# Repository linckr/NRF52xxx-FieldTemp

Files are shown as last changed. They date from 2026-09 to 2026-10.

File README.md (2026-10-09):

# PandaTemperature：固件、Android 与硬件

nRF52810 + W25Q64 温湿度/气压记录仪与配套 Android 客户端，统一在此 Git 项目维护。

- 仓库根 src/、boards/、overlay 与 sysbuild 配置：Firmware。
- android/：Android Gradle 根目录，含源码、测试和凭据示例。
- [CODEX_START_HERE.md](CODEX_START_HERE.md)：统一接手入口。
- [HANDOFF.md](HANDOFF.md)：验证边界和 P0–P4 任务。
- [PROTOCOL.md](PROTOCOL.md)、[OTA.md](OTA.md)、[HARDWARE.md](HARDWARE.md)：两端协议、OTA、引脚/分区事实。

保持现有固件布局，不为目录合并修改 MCUboot、UUID、OTA 命令、签名算法或 Flash 地址。签名私钥、Android keystore、OTA 凭据、设备数据库和构建产物不入库。历史设计文档与当前实现冲突时，以代码为准。

Android 独立仓库保留用于向 yodfz/PandaThemperature-Android 提交上游 PR；对应提交见 android/README.md。

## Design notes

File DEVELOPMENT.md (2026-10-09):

# DEVELOPMENT.md — 开发环境与构建

> 版本号全部从**当前实际安装/配置**读取（NCS 版本文件、`libs.versions.toml`、
> `gradle-wrapper.properties`、`<sysbuild>/*/zephyr/.config` 等），不是凭记忆填写。

---

## 第一部分：Firmware

## 1. 环境清单

| 项目 | 值 |
|---|---|
| 操作系统 | Windows |
| nRF Connect SDK (NCS) | **3.2.1**，安装根 `C:\ncs\v3.2.1` |
| Zephyr | **4.2.99**（`C:\ncs\v3.2.1\zephyr\VERSION`） |
| Zephyr SDK (toolchain) | **0.17.0**（`C:\ncs\toolchains\66cdf9b75e\opt\zephyr-sdk`） |
| 编译器 | `arm-zephyr-eabi-gcc` **GNU 12.2.0** |
| west | **1.4.0** |
| CMake | **3.21.0** |
| 工具链 Python | **3.12.4** —— `C:\ncs\toolchains\66cdf9b75e\opt\bin\python.exe` |
| board target | **`nrf52dk/nrf52810`** |
| 调试器 | CMSIS-DAP（枚举名 `jixin.pro CMSIS-DAP_LU` / 唯一 ID `LU_2022_8888`），pyOCD |

### 与构建直接相关的文件

| 文件 | 作用 |
|---|---|
| `prj.conf` | App 的 Kconfig（**每个符号只能出现一次**，重复赋值会让文档与实际不一致） |
| `app.overlay` | **板级引脚与 W25Q64/ADC 定义的实际生效处**（见 `HARDWARE.md` §2） |
| `boards/` | 当前没有生效的 board-specific overlay；唯一生效入口是 `app.overlay` |
| `sysbuild.conf` | sysbuild 级配置：MCUboot / overwrite-only / 外置次级槽 / ECDSA-P256 |
| `sysbuild/mcuboot.conf` | MCUboot 自身的 Kconfig（SPI NOR、布局页 4096、RC 32k、关日志） |
| `sysbuild/mcuboot.overlay` | MCUboot 的 devicetree（**与 App 独立，改引脚要同步改**） |
| `pm_static.yml` | Partition Manager 静态布局（**唯一编辑入口**） |
| `VERSION` | **镜像版本号唯一来源**（当前 `1.0.9` + tweak `0`） |
| `tools/build_sysbuild.py` | 构建包装（引号安全 + 签名私钥注入），见 §2 |

### 关键 Kconfig（摘自实际构建）

| 配置 | 值 | 说明 |
|---|---|---|
| `CONFIG_MAIN_STACK_SIZE` | 1024 | 全工程**唯一**赋值点 |
| `CONFIG_SYSTEM_WORKQUEUE_STACK_SIZE` | 1280 | OTA 异步化需要 |
| `CONFIG_BT_RX_STACK_SIZE` | 1024 | 勿降到 768 |
| `CONFIG_MPSL_WORK_STACK_SIZE` | 640 | 余量最小的栈（240 B） |
| `CONFIG_ISR_STACK_SIZE` | 1024 | |
| `CONFIG_BT_L2CAP_TX_MTU` | 128 | 协商失败自动回退，非升级前提 |
| `CONFIG_BT_BUF_ACL_RX_SIZE` / `TX_SIZE` | 132 / 132 | = MTU + 4 |
| `CONFIG_BT_MAX_CONN` | 1 | 同时只允许一个连接 |
| `CONFIG_SPI_NOR_FLASH_LAYOUT_PAGE_SIZE` | **4096** | 必须等于 W25Q64 真实扇区 |
| `CONFIG_IMG_BLOCK_BUF_SIZE` | 256 | = W25Q64 页大小 |
| `CONFIG_STREAM_FLASH` / `CONFIG_IMG_MANAGER` | y / y | ⚠️ `IMG_MANAGER` 是 **depends on** `STREAM_FLASH`，不显式开会被静默丢弃 |
| `CONFIG_IMG_ENABLE_IMAGE_CHECK` | y | App 侧整镜像 SHA-256 |
| `CONFIG_REBOOT` | y | `sys_reboot()` 需要 |
| `CONFIG_ADC` | y | 电池电压（VDD 通道） |
| `CONFIG_LOG` / `CONFIG_PRINTK` / `CONFIG_CONSOLE` | **n / n / n** | 发布态 |
| `CONFIG_NCS_BOOT_BANNER` / `CONFIG_EARLY_CONSOLE` | **n / n** | 必须一起关，否则它们 `select PRINTK`（白占 17,492 B ROM） |
| `CONFIG_USE_SEGGER_RTT` / `CONFIG_RTT_CONSOLE` | n / n | 发布态 |

> **调试时怎么开日志**：把 `prj.conf` 末尾"Release 配置"段整体注释掉，
> 改用 RTT（`CONFIG_CONSOLE=y` + `CONFIG_USE_SEGGER_RTT=y` + `CONFIG_RTT_CONSOLE=y` +
> `CONFIG_NCS_BOOT_BANNER=n` + `CONFIG_PRINTK=y`）。写法在 `prj.conf` 开头有完整说明。
> **不要**只写 `CONFIG_PRINTK=y` 而留着 `NCS_BOOT_BANNER=y`。

### 签名配置

| 项目 | 值 |
|---|---|
| 算法 | `SB_CONFIG_BOOT_SIGNATURE_TYPE_ECDSA_P256=y` |
| 私钥传入方式 | **`MCU_BOOT_SIGNING_KEY` 环境变量** 或 **`--signing-key <path>` 参数** |
| 私钥是否入库 | **否**（`.gitignore` 只按目录/文件名精确忽略，不影响将来入库公钥） |
| 默认私钥路径 | **没有**（刻意不提供） |

---

## 2. 构建：统一走 `tools/build_sysbuild.py`

**不要**直接 `west build`：`SB_CONFIG_BOOT_SIGNATURE_KEY_FILE` 是 Kconfig 字符串，
值必须自带引号，而 PowerShell 会剥掉内层双引号，导致
`malformed string literal in assignment to BOOT_SIGNATURE_KEY_FILE` 构建中止。
该脚本自己拼 `sys.argv`、直接调用 `west.app.main()`，不让 shell 参与引号处理。

### 2.0 先把私钥路径设好（PowerShell）

```powershell
$env:MCU_BOOT_SIGNING_KEY = "<仓库外的ECDSA-P256私钥路径>"
```

> 私钥是**凭据**，**不要**复制进仓库，也不要把路径写死进脚本。
> 如需用另一把密钥，加 `--signing-key` 参数覆盖（优先级高于环境变量）。

### 2.1 普通构建（干净重建，最常用）

```powershell
cd C:\Users\linckr\NRF52xxx-FieldTemp
C:\ncs\toolchains\66cdf9b75e\opt\bin\python.exe tools\build_sysbuild.py build-v9
```

> 脚本内部已经固定 `-p always`（pristine）+ `-b nrf52dk/nrf52810` + `--sysbuild`，
> 因此**这条命令就是 pristine 构建**，无需再单独执行 pristine。

### 2.2 显式 pristine / clean

```powershell
# pristine（脚本默认行为，等价写法）
C:\ncs\toolchains\66cdf9b75e\opt\bin\python.exe tools\build_sysbuild.py build-v9

# 彻底删除构建目录（clean）
Remove-Item -Recurse -Force .\build-v9
```

### 2.3 MCUboot sysbuild

MCUboot **总是**跟着 App 一起被 sysbuild 构建，产物在
`<build_dir>\mcuboot\zephyr\`。不需要单独构建 MCUboot。
只有在你修改 `sysbuild/mcuboot.conf` 或 `sysbuild/mcuboot.overlay` 后，
重新执行 §2.1 即可。

单独查看 MCUboot 产物：

```powershell
Get-ChildItem C:\Users\linckr\NRF52xxx-FieldTemp\build-v9\mcuboot\zephyr\zephyr.*
```

### 2.4 signed firmware 构建

**签名的产物是同一个命令自动产出的**，无需手工 `imgtool sign`：

```powershell
# 构建完成后，签名镜像已经在这里
Get-Item C:\Users\linckr\NRF52xxx-FieldTemp\build-v9\NRF52xxx-FieldTemp\zephyr\zephyr.signed.bin
```

如需**独立校验**签名（不修改任何产物）：

```powershell
$env:PYTHONPATH = "C:/ncs/v3.2.1/bootloader/mcuboot/scripts"
C:\ncs\toolchains\66cdf9b75e\opt\bin\python.exe -m imgtool.main verify `
  --key $env:MCU_BOOT_SIGNING_KEY `
  build-v9\NRF52xxx-FieldTemp\zephyr\zephyr.signed.bin
# 当前源码构建期望：Image was correctly validated / Image version: 1.0.9+0
```

### 2.5 查看构建产物

```powershell
$B = "C:\Users\linckr\NRF52xxx-FieldTemp\build-v9"
Get-ChildItem $B\NRF52xxx-FieldTemp\zephyr\zephyr.bin, `
              $B\NRF52xxx-FieldTemp\zephyr\zephyr.signed.bin, `
              $B\NRF52xxx-FieldTemp\zephyr\zephyr.elf, `
              $B\mcuboot\zephyr\zephyr.hex, `
              $B\merged.hex, `
              $B\dfu_application.zip |
  Select-Object Name, Length, LastWriteTime
```

### 2.6 查看 memory summary

```powershell
# 方式一：生成 Zephyr 的 ram/rom 报告（在构建目录里跑 ninja）
cd C:\Users\linckr\NRF52xxx-FieldTemp\build-v9\NRF52xxx-FieldTemp
C:\ncs\toolchains\66cdf9b75e\opt\bin\ninja.exe ram_report
C:\ncs\toolchains\66cdf9b75e\opt\bin\ninja.exe rom_report

# 方式二（推荐）：项目的体积门禁，一次给出 A–J 共 14 项判定
cd C:\Users\linckr\NRF52xxx-FieldTemp
C:\ncs\toolchains\66cdf9b75e\opt\bin\python.exe tools\size_summary.py build-v9

# 版本/发布门禁
C:\ncs\toolchains\66cdf9b75e\opt\bin\python.exe tools\release_gate.py build-v9
```

> `size_summary.py` 也可直接给 sysbuild 根目录，会自动下钻到应用镜像目录。
> 加 `--json` 便于 CI 消费。

### 2.7 构建偶发失败

`ar.exe Permission denied` 之类的中断，用增量续跑即可，不必删目录重来：

```powershell
C:\ncs\toolchains\66cdf9b75e\opt\bin\cmake.exe --build C:\Users\linckr\NRF52xxx-FieldTemp\build-v9
```

---

## 3. 引导加载相关：`VERSION` 与发布门禁

- **改行为必须抬版本**：只改仓库根 `VERSION`（`PATCHLEVEL`）。
  Zephyr 会自动生成 `app_version.h`，并让
  `CONFIG_MCUBOOT_IMGTOOL_SIGN_VERSION` 取 `APP_VERSION_TWEAK_STRING`。
- `VERSION` 缺失会**静默**退回 `0.0.0+0` —— `tools/release_gate.py` 的 R1 项专门拦这个。
- 手工 `imgtool --version x.y.z` 产出的 `zephyr.signed.vN.bin` **不是发布对象**（R4 项会拦）。

```powershell
# 发布确认后推进基线（仅在你确实要把它当作"上一生产版本"时执行）
C:\ncs\toolchains\66cdf9b75e\opt\bin\python.exe tools\release_gate.py build-v9 --promote
```

---

## 4. 烧录与调试（DAPLink / CMSIS-DAP + pyOCD）

pyOCD 装在**项目专用 venv**里（与 bleak 同一个解释器，专供 BLE + SWD 联调脚本）：

```powershell
$PYOCD = "C:\Users\linckr\.workbuddy\binaries\python\envs\default\Scripts\pyocd.exe"
```

| 包 | 版本 |
|---|---|
| pyocd | 0.45.1 |
| cmsis-pack-manager | 0.6.0 |
| bleak | 3.0.2 |

### 4.1 连接 / 确认探针

```powershell
& $PYOCD list
# 期望看到：0  jixin.pro CMSIS-DAP_LU  LU_2022_8888  n/a
```

### 4.2 烧录（**首次/恢复用 `merged.hex`**）

```powershell
$HEX = "C:\Users\linckr\NRF52xxx-FieldTemp\build-v9\merged.hex"
& $PYOCD flash -t nrf52810_xxaa --frequency 500k $HEX
```

`--frequency 500k` 是为了链路稳定（长排线/劣质杜邦线时尤其必要）。

### 4.3 复位

```powershell
& $PYOCD reset -t nrf52810_xxaa
```

### 4.4 调试（GDB server）

```powershell
& $PYOCD gdbserver -t nrf52810_xxaa --frequency 500k --port 3333
# 另一个终端用 arm-zephyr-eabi-gdb 连 localhost:3333
```

### 4.5 ⚠️ pyOCD 的两个致命坑

1. **连接即 halt 目标核。** 读 RAM 得到的是冻结快照，会假造出"采样停摆"。
   读运行态前先查 `DHCSR(0xE000EDF0)` 的 `S_HALT`(bit17)，用完 `t.resume()` 恢复。
2. **`tools/w25q64_host_dfu.py` 的 `read` / `info` 会 reset-and-halt**，
   用完**必须手动 resume**，否则设备不广播、会被误判为"固件坏了"。

另外：**主机侧 poke SPIM0 直读外置 Flash 是侵入式操作**（会覆盖 App 的 SPI 驱动寄存器）。
必须全程保持 halt（`with probe.held():`），只作最后一步、只读一次、读完立即复位。
**不要**进常规回归。

---

## 5. 四个产物的区别（**最容易搞错的地方**）

| 文件 | 内容 | 用在哪 |
|---|---|---|
| `zephyr.bin` | **裸应用镜像**（无 MCUboot 头、无签名） | 只用于比对/分析；**不能**用于 OTA |
| `zephyr.signed.bin` | 应用镜像 + MCUboot 头(512 B) + TLV(SHA-256/KEYHASH/**ECDSA256 签名**) | ✅ **现场 OTA（BLE）就传它** |
| `merged.hex` | **MCUboot + 主槽**（带绝对地址的 Intel HEX） | ✅ **首次 SWD 烧录 / 救砖** |
| `dfu_application.zip` | 供 MCUboot **serial recovery** 的容器（含 manifest + 镜像） | ❌ 当前未启用 serial recovery，用不上 |

参考大小（`build-pub`，2026-09-14；签名 TLV 长度可能逐次变化，应以当前构建产物为准）：

| 产物 | 大小 |
|---|---|
| `zephyr.bin` | 149,528 B |
| `zephyr.signed.bin` | 150,191 B |
| `merged.hex` | 512,122 B |
| `dfu_application.zip` | 150,996 B |
| `mcuboot/zephyr/zephyr.bin` | 31,876 B |

---

## 6. 常用工具（`tools/`）

| 工具 | 用途 |
|---|---|
| `build_sysbuild.py` | 引号安全的 sysbuild 构建包装（**唯一推荐构建入口**） |
| `size_summary.py` | 体积/布局门禁 A–J（真 CI 门禁，FAIL 返回非零） |
| `release_gate.py` | 发布门禁 R1–R5（版本单一源、无手工签名残留） |
| `stack_hwm.py` | 0xAA 扫描线程栈高水位（**必须传 `--config`**，否则 MPU 守卫区会误报 100%） |
| `ram_breakdown.py` | RAM 构成分解（注意：`nm` 不加 `-t` 时地址与尺寸**都是十六进制**） |
| `size_diff.py` | 两个构建的 ROM/RAM 差异对比 |
| `ota_host_client.py` | PC 侧 BLE OTA 客户端（需要装了 bleak 的解释器） |
| `ota_mkbadsig.py` | 造"坏签名"镜像（只翻 ECDSA 签名 TLV 1 字节） |
| `ota_powerloss_reset.py` | SWD 复位回归，不等同于真实断电 |
| `w25q64_host_dfu.py` | 主机侧外置 Flash 读写（**有运行扰动**，见 §4.5） |
| `free_ble.py` | **PC 侧 BLE 测试前必用**：确保手机让出 BLE（`am force-stop` 不够） |
| `verify_v6_timing.py` | 记录周期与事件限流验证 |
| `verify_v7_wallclock.py` | 墙钟整分对齐三项测试 |
| `dfu_e2e_verify.py` | 写次级槽 + trailer → 复位 → 逐字节比对主槽 |

需要 **bleak** 的脚本（`ota_host_client.py` / `verify_v7_wallclock.py` / `free_ble.py`）
必须用同时装了 bleak 与 pyocd 的解释器：

```powershell
C:\Users\linckr\.workbuddy\binaries\python\envs\default\Scripts\python.exe tools\ota_host_client.py --file <zephyr.signed.bin>
```

---

## 第二部分：Android App

## 7. 环境清单（全部读自项目实际配置）

| 项目 | 值 | 来源 |
|---|---|---|
| Android Studio | `AI-261.26222.65.2613.16025427`（build `261.26222.65.2613.16025427`） | `C:\Program Files\Android\Android Studio\product-info.json` |
| Gradle | **8.13** | `gradle/wrapper/gradle-wrapper.properties` |
| AGP | **8.13.2** | `gradle/libs.versions.toml` |
| Kotlin | **2.0.21** | 同上 |
| KSP | **2.0.21-1.0.27** | 同上 |
| Compose BOM | 2024.09.00 | 同上 |
| Room | 2.6.1 | 同上 |
| **JDK** | **17** | ⚠️ 见下方警告 |
| `compileSdk` | **36** | `app/build.gradle.kts` |
| `targetSdk` | **36** | 同上 |
| `minSdk` | **26** | 同上 |
| `applicationId` / `namespace` | `com.example.pandatemperature` | 同上 |
| `versionCode` / `versionName` | **4 / "1.1.2"** | 同上（**与固件版本无关**） |
| Java / Kotlin target | 11 | 同上 |
| 构建变体 | `debug` / `release` | 无 flavor |

### ⚠️ JDK 必须用 17

Android Studio 自带的 `jbr` 现在是 **JDK 25.0.2**，Gradle 8.13 **不支持**，
症状是构建失败且 `What went wrong:` 下面**只有一行版本号**（如 `25.0.2`），没有任何上下文。

本机可用的 JDK 17：

```powershell
$env:JAVA_HOME = "C:\Users\linckr\.workbuddy\binaries\jdk\jdk-17.0.20.1+1"
```

**不要**为了迁就 JDK 25 去升级 Gradle wrapper（会牵动 AGP 兼容性）。

### SDK 位置

```properties
# source/local.properties（已被 .gitignore 排除；下面是示例，实际为本机 SDK 路径）
sdk.dir=<你的 Android SDK 路径>
```

已安装：`build-tools/35.0.0`、`build-tools/36.0.0`、`platforms/android-36`。

---

## 8. 构建（PowerShell）

先设置两个环境变量（每次新开终端都要设）：

```powershell
$env:JAVA_HOME   = "C:\Users\linckr\.workbuddy\binaries\jdk\jdk-17.0.20.1+1"
$SRC = "C:\Users\linckr\NRF52xxx-FieldTemp\android"
```

### 8.1 Debug 构建

```powershell
cd $SRC
.\gradlew.bat :app:assembleDebug --console=plain
```

### 8.2 Debug 单元测试

```powershell
cd $SRC
.\gradlew.bat :app:testDebugUnitTest --console=plain
# 报告：app\build\reports\tests\testDebugUnitTest\index.html
```

### 8.3 Release 构建

```powershell
cd $SRC
.\gradlew.bat :app:assembleRelease --console=plain
```

- 若存在 `source/keystore.properties` → 用正式签名；
- **不存在 → 回退 Android 默认调试密钥签名**（产物可 `adb install`，但**不可分发**）。
- ⚠️ 将来补齐正式签名后，因为签名不同，设备上的旧包**必须先卸载**才能安装。

### 8.4 AAB（上架用）

```powershell
cd $SRC
.\gradlew.bat :app:bundleRelease --console=plain
```

### 8.5 产物路径

| 产物 | 路径 |
|---|---|
| Debug APK | `source\app\build\outputs\apk\debug\app-debug.apk` |
| Release APK | `source\app\build\outputs\apk\release\app-release.apk` |
| Release AAB | `source\app\build\outputs\bundle\release\app-release.aab` |

### 8.6 安装到真机

```powershell
$ADB = "C:\Users\linckr\AppData\Local\Android\Sdk\platform-tools\adb.exe"
& $ADB devices
& $ADB install -r -t -g "$SRC\app\build\outputs\apk\debug\app-debug.apk"
```

`-t` 允许 test-only 包，`-g` 直接授予已声明的运行时权限。

**国内 ROM（MIUI/澎湃、ColorOS 等）会拒绝 `adb install`**，报
`INSTALL_FAILED_USER_RESTRICTED: Install canceled by user`。这**不是**签名或 APK 问题，
需要在手机上手动开：**开发者选项 → USB 安装**（部分机型还要开「USB调试(安全设置)」）。
兜底路径：

```powershell
& $ADB push "$SRC\app\build\outputs\apk\debug\app-debug.apk" /sdcard/Download/
# 然后在手机上用文件管理器点安装（需允许「安装未知应用」）
```

---

## 9. Android 权限要求

声明在 `app/src/main/AndroidManifest.xml`：

| 权限 | 用途 | 生效范围 |
|---|---|---|
| `BLUETOOTH` / `BLUETOOTH_ADMIN` | 旧版蓝牙权限 | **API ≤ 30** |
| `BLUETOOTH_SCAN`（`neverForLocation`） | 扫描 | **API ≥ 31** |
| `BLUETOOTH_CONNECT` | 连接/读写特征 | **API ≥ 31** |
| `ACCESS_FINE_LOCATION` / `ACCESS_COARSE_LOCATION` | 记录 GPS 坐标；**API ≤ 30 时扫描 BLE 必需** | 全版本声明 |
| `FOREGROUND_SERVICE` + `_CONNECTED_DEVICE` + `_LOCATION` | 后台保活前台服务 | API ≥ 29 / 34 分型 |
| `POST_NOTIFICATIONS` | 天气预警通知 | **API ≥ 33**（需运行时申请） |
| `VIBRATE` | 通知振动 | |
| `RECORD_AUDIO` | 工具箱「营地助手」风向检测 | 运行时申请 |
| `CAMERA` | 「营地回溯」相机 | 运行时申请 |

`uses-feature android:hardware.bluetooth_le required="true"`。

**BLE 权限兼容性要点**

- `minSdk = 26`：API 26–30 上 `BLUETOOTH_SCAN/CONNECT` 被忽略，
  扫描需要 `ACCESS_FINE_LOCATION` **且**系统定位开关打开；
  API 31+ 上反过来，`neverForLocation` 让扫描不再依赖定位权限。
- 组件：`MainActivity`（LAUNCHER）、`service.BleConnectionForegroundService`
  （`foregroundServiceType="connectedDevice"`，`exported="false"`）。
- ⚠️ Android 12+ 下 App 不在前台时启动前台服务会抛
  `ForegroundServiceStartNotAllowedException`（屏幕熄灭即算后台）——这是系统限制，
  不是 bug；点亮屏幕正常启动即可。

---

## 10. PC 侧做 BLE 测试前必读

Windows 上跑 `tools/ota_host_client.py` / `free_ble.py` 之前：

1. **`adb shell am force-stop` 不足以让手机让出 BLE**（App 前台保活会自动拉起并重连）。
2. 判据是**两个条件同时满足**：`pidof <pkg>` 为空 **且** 设备在广播
   （`CONFIG_BT_MAX_CONN=1` 下「在广播」等价于「未被连接」）。
3. 用 `tools/free_ble.py` 做这件事，退出码非 0 就不要开始测试，
   否则会把「连不上/掉线」误判成固件问题。
4. WinRT BLE 栈成功率约 1/6，**只重试 `connect()` 不够**
   （常见"连上立刻掉"，表现为 `start_notify` 抛 Not connected）
   → 必须把 `connect + start_notify + START` 作为**整体**重试。
5. 客户端脚本要加 `python -u`，否则重定向到文件时看不到进度。

## 2026-10-09 P2构建与生产签名阶段

开发签名 `build-p2-dev` 已完成sysbuild及门禁：Flash151540 B、signed152203 B、RAM23080 B；
相对v8增加Flash2012 B、RAM128 B，RAM余1496 B；MCUboot仍31876 B，余892 B。
签名镜像相对primary减6 KiB预留的157696 B红线余5493 B；ECDSA DER长度可能有逐次差异。
分区与MCUboot配置没有修改，新历史存储码及协议见PROTOCOL §3。

native C测试通过TinyCC编译真实生产函数及实际序列化片段，NOR/NVS替身故障注入为0 failures：
33000→3000、元数据失败时不擦除、回收中断恢复、跨物理环形边界、撕裂槽、丢失提交应答、
批量跨扇区和12/14 B传输。入口如下；编译器路径由本机提供，不下载/提交测试二进制：

```powershell
python tools/test_history_storage.py --cc "<本机native C编译器路径>" --work-dir "<本机临时目录>"
```

Android124项单测通过，生产签名APK已验签；当前源码versionCode4/versionName1.1.2。
生产密钥及签名配置全部在仓库外；Android使用PANDA_RELEASE_KEYSTORE_PROPERTIES注入外置配置，
固件使用MCU_BOOT_SIGNING_KEY或--signing-key。不要把真实文件、路径细节或内容写入Git。
生产ECDSA公钥必须先通过SWD配置到MCUboot，现有设备只信任原公钥，不能直接OTA换成新签名。
生产APK验签与设备固件生产信任部署是不同验收项。

已完成开发信任链 1.0.9 升级与主槽逐字节回读、V3 历史回读和硬件精确保留3000条；P3已取得擦除流程、部分写入、END后和暂停搬运流程的真实电池断电恢复证据，但不证明 NOR/NVMC 忙脉冲中断电。保留策略冷启动持久性已验证；realme到小米数据库迁移已完成；持续App3000策略retain验收通过，最新Live回归已通过；生产信任链部署待完成。 具体证据与耗时见HANDOFF最新阶段记录。
原始数据已本机留档并确认SWD识别；私人数据库、完整备份及凭据不随提交上传。

### 2026-10-10 当前验收状态：App 1.1.2 / 持续3000条

当前App为versionCode4 / versionName1.1.2、Room11，手机安装Debug APK；Firmware为开发信任链1.0.9。124项JVM单元测试、10项isolated Room测试通过；生产1.1.2 APK v2/RSA3072验签通过、证书未变，尚未安装生产APK。最新Live连续全量/立即重试/中途断连/重连回归171.105 s通过；最终归档结果见本节末。

手机已完成realme完整数据库到小米迁移（主库SHA匹配源归档），原小米1,042条GPS已备份、未并入。随后按完整归档及硬件raw集合应用精简；早先一次精简后App增至3004而硬件仍3000，确认一次性精简不足，现已实现持续策略。最新明确retain真机36.388 s通过：硬件3000、App模块3000、手机来源样本208；启用标记已持久化。手机样本包含有/无GPS，模块3000不等于整个数据库总行数；隔离记录及私人完整档案仍保留本机，不上传。

持续策略按device显式启用：仅在retain3000命令得到count=3000且idle确认后保存本地prefs。对已启用且支持0x80的设备，每次历史同步发timestamp=0全量请求；只有本会话真实END、received=3000、唯一wire timestamps=3000、前后原始8 B HISTORY_INFO完全一致、所有upsert成功及连接/会话仍属于捕获目标时，才事务删除不在该实际wire集合的模块行。删除ID每批最多500，失败/取消/切换设备全部回滚、不删除；窗口不稳定最多自动重试一次。不能按时间排序取3000，缓存行可能比设备窗口更新。启用标记仅代表策略启用，不能代替每次精简成功证据。

Room11的isPhoneSample采用INTEGER NOT NULL DEFAULT0；新手机实时行始终true，即使没有GPS。10→11无损迁移把已有GPS行标为phone，旧无GPS来源未知保守默认false；在完整归档后按真实wire集合核对，不能靠年份猜测删除。历史DAO/count/增量仅处理false且geoNull；所有phone/GPS、隔离表和其他设备受保护。严格核心数值断言曾阻止单行旧手机实时/硬件差异的错误精简，没有通过放宽断言绕过。测试覆盖来源保护、精确164缓存差集、1201条跨删除批次、SQL中段abort和session失效原子回滚。

硬件3000策略已在隔离整根SWD后的实际电池断电冷启动验证：archive_sync23.296 s、完整3000及核心/GPS/无重复/未来检查通过；再次raw19.434 s通过（3000 V3、42000 B、END、8 B INFO稳定）。此前小米1.1.0 archive_sync79.289 s通过是历史证据；当前1.1.2也已独立完成Live回归，见本节末。VDD2.765 V为10/9约18:45观测、2.875 V为10/10约00:17 VM观测，均非当前实时读数，ADC仍未校准/无万用表对照。

P3四阶段已取得擦除流程、部分写入、END后及暂停MCUboot搬运的真实电池断电恢复证据；不证明NOR WIP/NVMC写脉冲被切断。SWD仍连接时曾出现W25Q64 init_res=22，根因未定，隔离SWD重试通过不等于已定位。旧v8硬件尾部14条曾被覆盖，timestamp/传感器数值14/14均在本机完整App档案保全；新恢复函数已有真实C回归与冷启动证据。

固件资源保持App Flash151540 B、RAM23080 B（余1496 B），MCUboot31876 B（余892 B），分区不变。DEV signed候选152203 B已真机回读；生产asset152202 B未部署，DER长度可变。两镜像App payload151540 B逐字节一致，SHA256 `236323e4319f7228ce6b4856bb1736a4bede1cf58e3dfc85239678bdc943494c`；完整signed文件不能混同。生产imgtool验证通过，但生产MCUboot公钥信任尚未部署、候选产物入口为 [v1.0.9-rc.1](https://github.com/linckr/NRF52xxx-FieldTemp/releases/tag/v1.0.9-rc.1)，发布状态以页面为准；两个upstream PR #2在最近记录时OPEN，后续实时核对。

持续策略与Live验收已完成，最终归档模块3000；生产信任部署与ADC校准仍是独立待办。

### 最终Live与一致归档验收

最终真机Live回归171.105 s通过：两次连续全量各3000、立即重试、收到部分记录后断连且全部既有模块ID未删除、重连及再次同步完成3000；仍保留窗口内记录ID/核心字段和所有既有手机样本，无重复/未来时间。重连首轮观察到0条历史、随后一次自动全量重试成功；本轮已由有界重试覆盖，但首次重连延迟为Medium性能边界，根因未定位。

最终只读一致归档（2026-10-10约01:12）SQLite integrity ok：模块3000、GPS187、无GPS手机样本31（受保护手机样本共218）、active3218、quarantine22484，未来时间0、模块重复0。Live期间VM电压开始2.886 V、结束2.868 V（本轮观测，不是ADC校准证明）。App已恢复运行；手机临时USB亮屏设置已恢复原值。私人数据库、档案路径、标识与归档内容不进Git。

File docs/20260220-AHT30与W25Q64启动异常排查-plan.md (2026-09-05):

# 20260220 - AHT30 与 W25Q64 启动异常排查计划

## 1. 需求背景

用户贴出的启动日志中存在三类异常：

| 现象 | 说明 |
| --- | --- |
| NVS 挂载失败: -45 | 内部 Flash 上的 NVS 分区挂载失败，配置使用默认值 |
| W25Q64 JEDEC ID 不匹配 | 读到的 ID 为 `0x00 0x00 0x00`，期望 `EF 40 17` |
| AHT30 测量命令发送失败: -5 | I2C 读写持续返回 -5 (EIO)，温湿度无法采集 |

需要分析原因并给出排查/修复方案，按最小改动、先硬件后软件的原则进行。

## 2. 错误码含义（简要）

- **-5**：Zephyr 中为 `-EIO`（I/O 错误）。I2C 上常见原因：总线 NACK（从机无应答）、总线被拉死、引脚/接线错误、从机未上电或地址错误。
- **-45**：Zephyr NVS 相关错误，多与存储初始化或分区有关（具体需查 NVS 驱动返回值定义）。
- **W25Q64 全 0**：SPI 读 ID 得到 0x00 0x00 0x00 通常表示：片选/时钟/数据线接错、MISO 未接或接反、Flash 未上电、或 SPI 模式/速率不匹配。

## 3. 实现方案概述

### 3.1 定位思路（不先改业务逻辑）

1. **AHT30 -5（优先）**

   - 确认是硬件/接线问题还是软件配置问题。
   - 建议：保留现有 I2C 引脚与速率配置，先做硬件与总线排查；必要时在软件上增加 I2C 扫描结果打印、降低重复失败时的日志刷屏。

2. **W25Q64 JEDEC 全 0**

   - 确认 SPI 引脚（含 CS）、供电、MISO 连接；确认 overlay 中 SPI 与 W25Q64 节点是否与当前板子一致。
   - 可选：若为兼容多板型，可考虑在 JEDEC 读失败时降低 SPI 频率重试或增加一次复位/释放 CS 的序列后再读 ID（仍以硬件排查为主）。

3. **NVS -45**
   - 在确认 Flash 分区与 NVS 配置正确的前提下，查 NVS 返回值 -45 在 NCS/Zephyr 中的定义；若为 52832 与 52810 共用工程，需区分不同板子的分区表（如 `nrf52832dk_nrf52832_cpuapp.overlay` 与 `app.overlay` 中分区是否被正确合并）。

### 3.2 软件可做的最小改动（在硬件排查之后）

- **AHT30**

  - 若确认 I2C 硬件正常：可增加“初始化失败时不再周期性打 AHT30 失败日志”或“限频打印”，避免刷屏。
  - 可选：启动时做一次 I2C 总线扫描并打印扫描到的地址，便于确认 0x38 是否可见。

- **W25Q64**

  - 保持当前“JEDEC 不匹配仍继续、并进深度掉电”的策略，避免因外置 Flash 未接而卡死；若后续确认硬件接好仍读不到，再考虑“降速重试读 ID”或“复位 CS 后重试”等小改动。

- **NVS**
  - 查 -45 对应含义；确认当前构建使用的 overlay 与目标板（52832/52810）一致，分区起始与大小是否与 NVS 使用匹配。

## 4. 开发计划列表

- [ ] **4.1** 文档与结论：完成本排查计划文档，并给出“用户侧排查步骤”与“可选软件改动”清单。
- [ ] **4.2** AHT30：在 `main.c` 或 AHT30 调用处，当 `aht30_init()` 已失败时，避免或限频打印后续 `aht30_read()` 的 -5 错误（避免日志刷屏）。
- [ ] **4.3** AHT30（可选）：启动时若已做 I2C 扫描，确保扫描结果（是否出现 0x38）在日志中可见，便于确认硬件。
- [ ] **4.4** W25Q64：仅当硬件/接线/overlay 确认无误后仍读不到 JEDEC 时，再评估“降速或复位后重试读 ID”等小改动；否则以硬件排查为主。
- [ ] **4.5** NVS：查 NCS 3.2.1 中 NVS 返回 -45 的含义，并核对当前使用的 overlay 分区与目标板一致。

## 5. 用户侧建议排查步骤（先做再改代码）

1. **AHT30（-5）**

   - 确认 AHT30 模块已正确接到 I2C 总线（SDA→P0.7, SCL→P0.6，与 overlay 一致）。
   - 确认模块供电（VCC/GND）及 I2C 上拉电阻（板载或模块自带 4.7k/2.2k）。
   - 用万用表/逻辑分析仪看 SDA/SCL 是否有波形、是否有 NACK。
   - 若有可能，用其他主机或工具扫描 I2C 总线，看 0x38 是否应答。

2. **W25Q64（JEDEC 0x00 0x00 0x00）**

   - 确认 CS(P0.28)、SCK(P0.30)、MOSI(P0.31)、MISO(P0.29)、VCC/GND 连接与 overlay 一致。
   - 确认 W25Q64 供电电压与电平匹配。
   - 重点确认 MISO 是否接到 MCU 的 MISO 引脚（读 ID 全 0 常为 MISO 未接或接错）。

3. **NVS（-45）**
   - 确认烧录/运行的是否为 52832 镜像，使用的 overlay 是否为 `nrf52832dk_nrf52832_cpuapp.overlay`（与 app.overlay 合并后分区是否含 `nvs_storage` 且大小正确）。

## 6. 小结

- **AHT30 -5**：先按 I2C 硬件与接线排查；软件上可做“初始化失败后限频/不再刷屏 AHT30 失败日志”及“打印 I2C 扫描结果”。
- **W25Q64 全 0**：以 SPI 与电源接线、MISO 为重点做硬件排查；软件保持当前容错行为，必要时再考虑降速/重试读 ID。
- **NVS -45**：查错误码定义并核对分区与板型一致后再决定是否改配置或代码。

完成 4.1 后，可根据用户确认再实施 4.2、4.3 等可选软件改动。

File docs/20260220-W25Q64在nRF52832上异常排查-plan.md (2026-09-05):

# 20260220 - W25Q64 在 nRF52832 上异常排查计划

## 1. 需求背景

- **现象**：同一套代码在 **nRF52810 上运行完全正常**，在 **nRF52832 上**出现：
  - W25Q64 JEDEC ID 读为 `0x00 0x00 0x00`（期望 `EF 40 17`）
  - 写使能失败（写使能后读状态 WEL 未置位，导致页编程返回 -5）
  - 历史存储读到空数据 0xFF（因 Flash 从未成功写入）
- **差异**：52810 使用 **SPI0**（0x40003000），52832 因 I2C0 与 SPI0 共用基址而使用 **SPI1**（0x40004000）；引脚一致：CS=28, SCK=30, MOSI=31, MISO=29。

## 2. 问题分析

| 现象 | 含义 |
| --- | --- |
| JEDEC ID 全 0 | SPI 读路径异常：MISO 未收到正确数据（若 MISO 浮空多为 0xFF，全 0 多为 MISO 被拉低或 SPI1 未用正确引脚/配置）  |
| 写使能“失败” | 写使能命令仅发送 0x06，不依赖 MISO；失败是因为**读状态寄存器**得到错误数据（WEL 未置位），根因仍是 SPI 读异常 |
| 52810 正常、52832 异常 | 指向 52832 上 **SPI1 的配置或行为** 与 52810 的 SPI0 存在差异 |

可能原因归纳：

1. **SPI1 未在 Kconfig 中显式启用**：部分构建下 DT 有 `spi1` 但未打开 `CONFIG_SPI_1`，导致驱动未编译或实例错误。
2. **SPI 模式/相位**：W25Q64 使用 Mode 0（CPOL=0, CPHA=0）；若 52832 上 SPIM1 默认与 SPI0 不同，会导致采样/移位错误，读回全 0 或错位。
3. **Pinctrl 未正确应用到 SPI1**：overlay 中虽定义了 `spi1_default_custom`（30/31/29），若合并顺序或 SoC 默认导致 SPI1 仍用默认引脚，则 MISO 可能接到错误 pin。
4. **EasyDMA/实例差异**：nRF52832 的 SPIM1 与 SPIM0 硬件行为一致，但 nrfx 层对 instance 1 的默认配置若有差异，可能影响 transceive。

## 3. 实现方案概述

- **原则**：最小改动、先软件后硬件；同一板子 52810 正常则硬件接线可暂假定正确，重点放在 52832 上 SPI1 的软件配置与一致性。
- **步骤**：
  1. 确认 52832 构建中 SPI1 已启用（Kconfig + 合并后 DTS）。
  2. 在驱动中显式设置 SPI Mode 0，与 52810 行为一致。
  3. 52832 上临时降频（如 1MHz）验证是否为时序/信号问题。
  4. 使用 DT alias `w25q64-spi` 获取 SPI 设备，避免 52832 硬编码 `spi1`，与 overlay 保持一致，便于后续多板型扩展。

## 4. 开发计划列表

- [x] **4.1** 文档：完成本排查计划文档（本文档）。
- [x] **4.2** 配置：为 nRF52832 构建显式启用 SPI1 — 已新增 `boards/nrf52832dk_nrf52832_cpuapp.conf`，内设 `CONFIG_SPI_1=y`。
- [x] **4.3** 驱动：在 `w25q64.c` 中显式设置 SPI 为 Mode 0（CPOL=0, CPHA=0），与 W25Q64 规格一致。
- [x] **4.4** 驱动：W25Q64 初始化时通过 DT alias `w25q64-spi` 获取 SPI 设备（overlay 中 52832→spi1，52810→spi0），去掉 SoC 分支硬编码。
- [ ] **4.5** 可选：52832 上若仍异常，在 overlay 或代码中临时将 W25Q64 SPI 频率降至 1MHz 进行对比测试，并在文档中记录结果。
- [ ] **4.6** 验证：在 52832 上烧录后确认 JEDEC ID 为 EF 40 17、写使能成功、历史存储可写入与读出。

## 5. 当前状态澄清（20260220）

- **初始化流程能跑完**，上层会打印「W25Q64 初始化成功」或「Flash 扫描写头完成」等，但 **写使能失败**，导致 **无法写入数据**（页编程返回 -5，历史存储为 0xFF）。
- 根因未变：52832 上 **SPI 读（MISO）异常** → 读状态寄存器得到错误值 → 写使能后校验 WEL 失败 → 无法写入。需按 4.2 ～ 4.5 做软件修改并验证。

## 6. 用户侧建议（若软件改动后仍异常）

1. **确认板型**：52832 是同一块 E104-BT5010A 换 MCU，还是 nrf52832dk？若为后者，需确认原理图上 W25Q64 是否接在 P0.28/29/30/31。
2. **检查合并后 DTS**：`build_xxx/zephyr/zephyr.dts` 中 `spi@40004000` 的 `pinctrl-0` 是否指向引脚 30/31/29。
3. **硬件**：用万用表/逻辑分析仪确认 MISO (P0.29) 在 JEDEC 读时有波形且非恒低。

## 7. 小结

- 根因集中在 **52832 上 SPI1 的配置或行为** 导致 SPI 读（MISO）异常。
- 软件侧：显式启用 SPI1、统一用 DT alias 取 SPI 设备、显式 Mode 0、可选降频测试。
- 完成 4.2 ～ 4.4 后根据现象再决定是否执行 4.5 及硬件排查。

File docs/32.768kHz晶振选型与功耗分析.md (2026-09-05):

# 32.768kHz 晶振选型与功耗分析文档

## 1. 概述

本文档详细分析 nRF52810 使用 32.768kHz 3225 无源晶振替代内部 RC 振荡器的功耗影响、元器件选型、配置方法等内容。

---

## 2. 内部 RC vs 外部晶振功耗对比

### 2.1 内部 RC 振荡器（当前配置）

#### 功耗组成

**睡眠期间功耗：**

| 组件 | 功耗 | 说明 |
|---|---|---|
| System ON 睡眠 | 1-2 μA | MCU 深度睡眠 |
| RC 振荡器 | 0.5-1 μA | 基础振荡器功耗 |
| **RC 校准开销** | **6-8 μA** | 每4秒校准一次，平均约7μA<br>- 校准时会启动高频时钟（16MHz）<br>- 校准持续时间约200μs，功耗峰值可达数mA |
| **RC 频率不稳定额外开销** | **2-5 μA** | 平均约3.5μA<br>- RC频率漂移导致BLE接收窗口需要开得更长<br>- 等待时间增加，平均功耗上升 |
| **总睡眠功耗** | **10-13 μA** | **平均约 11.5 μA** |

**广播期间功耗：**

| 组件 | 功耗 | 说明 |
|---|---|---|
| 慢速广播功耗 | 0.2 mA | 正常广播功耗 |
| RC不稳定导致接收窗口增加 | 额外 2-5 μA | 平均约3.5μA |
| **总广播功耗** | **约 0.2035 mA** | - |

### 2.2 外部 32.768kHz 无源晶振

#### 功耗组成

**睡眠期间功耗：**

| 组件 | 功耗 | 说明 |
|---|---|---|
| System ON 睡眠 | 1-2 μA | MCU 深度睡眠 |
| 无源晶振驱动 | 0.3-0.5 μA | 驱动电路功耗（低功耗驱动） |
| **无需校准开销** | **0 μA** | 晶振频率稳定，无需周期性校准 |
| 时钟稳定，BLE接收窗口优化 | 节省 2-5 μA | 无需额外等待时间 |
| **总睡眠功耗** | **1.3-2.5 μA** | **平均约 2.0 μA** |

**广播期间功耗：**

| 组件 | 功耗 | 说明 |
|---|---|---|
| 慢速广播功耗 | 0.2 mA | 正常广播功耗 |
| 时钟稳定，无额外开销 | 0 μA | 无额外等待时间 |
| **总广播功耗** | **约 0.2 mA** | - |

### 2.3 功耗节省分析

| 节省项 | 节省功耗 | 说明 |
|---|---|---|
| **RC 校准开销** | **7 μA** | 避免周期性校准 |
| **RC不稳定额外开销** | **3.5 μA** | 避免接收窗口增加 |
| **广播期间额外开销** | **1.75 μA** | 时钟稳定优化 |
| **RC振荡器** | **0.75 μA** | 替换为更高效的晶振驱动 |
| **小计** | **13 μA** | 理论节省 |
| **晶振驱动开销** | **-0.4 μA** | 晶振驱动需要功耗 |
| **净节省** | **约 11 μA** | **实际节省** |

---

## 3. 功耗精确计算（20分钟采集间隔，间歇广播模式）

### 3.1 场景配置

- **采集间隔**：20分钟（1200秒）
- **间歇广播**：广播10秒，休眠10秒（50%占空比）
- **配置**：CONFIG_PM=y，无UART，无LED
- **电池**：CR2032（220mAh）

### 3.2 使用内部 RC 的功耗计算

| 组件 | 功耗 | 占空比/频率 | 平均功耗贡献 |
|---|---|---|---|
| System ON 睡眠 | 1.5 μA | 10秒/周期 × 50% | 0.75 μA |
| RC 校准开销 | 7 μA | 持续（校准频率） | 7 μA |
| RC不稳定额外开销 | 3.5 μA | 持续 | 3.5 μA |
| RC 振荡器 | 0.75 μA | 持续 | 0.75 μA |
| 蓝牙广播 | 0.2 mA | 10秒/周期 × 50% | 0.1 mA |
| 广播期间额外开销 | 3.5 μA | 10秒/周期 × 50% | 1.75 μA |
| 唤醒采集 | 6 mA | 0.3秒/1200秒 | 0.0015 mA |
| **总计** | - | - | **约 0.113 mA** |

**续航计算：**
```
续航时间 = 220 mAh ÷ 0.113 mA = 1947 小时 ≈ 81 天
```

### 3.3 使用外部无源晶振的功耗计算

| 组件 | 功耗 | 占空比/频率 | 平均功耗贡献 |
|---|---|---|---|
| System ON 睡眠 | 1.5 μA | 10秒/周期 × 50% | 0.75 μA |
| 无源晶振驱动 | 0.4 μA | 持续 | 0.4 μA |
| 无需校准开销 | 0 μA | - | 0 μA |
| 无需额外开销 | 0 μA | - | 0 μA |
| 蓝牙广播 | 0.2 mA | 10秒/周期 × 50% | 0.1 mA |
| 无额外开销 | 0 μA | - | 0 μA |
| 唤醒采集 | 6 mA | 0.3秒/1200秒 | 0.0015 mA |
| **总计** | - | - | **约 0.102 mA** |

**续航计算：**
```
续航时间 = 220 mAh ÷ 0.102 mA = 2157 小时 ≈ 90 天
```

### 3.4 功耗对比总结

| 时钟源 | 睡眠功耗 | 广播功耗 | 总平均功耗 | CR2032续航 | 功耗节省 |
|---|---|---|---|---|---|
| **内部 RC** | 12 μA | 0.1035 mA | **0.113 mA** | 1947小时（81天） | 基准 |
| **外部晶振（10ppm/20ppm）** | 2.15 μA | 0.1 mA | **0.102 mA** | 2157小时（90天） | **11 μA（9.7%）** |

**结论：** 使用外部无源晶振可以节省约 **11 μA** 功耗，续航提升约 **9 天**。

---

## 3.5 功耗计算（2分钟采集间隔，间歇广播模式）

### 3.5.1 场景配置

- **采集间隔**：2分钟（120秒）
- **间歇广播**：广播10秒，休眠10秒（50%占空比）
- **配置**：CONFIG_PM=y，无UART，无LED
- **电池**：CR2032（220mAh）

### 3.5.2 使用内部 RC 的功耗计算（2分钟间隔）

| 组件 | 功耗 | 占空比/频率 | 平均功耗贡献 |
|---|---|---|---|
| System ON 睡眠 | 1.5 μA | 10秒/周期 × 50% | 0.75 μA |
| RC 校准开销 | 7 μA | 持续（校准频率） | 7 μA |
| RC不稳定额外开销 | 3.5 μA | 持续 | 3.5 μA |
| RC 振荡器 | 0.75 μA | 持续 | 0.75 μA |
| 蓝牙广播 | 0.2 mA | 10秒/周期 × 50% | 0.1 mA |
| 广播期间额外开销 | 3.5 μA | 10秒/周期 × 50% | 1.75 μA |
| 唤醒采集 | 6 mA | 0.3秒/120秒 | **0.015 mA** |
| **总计** | - | - | **约 0.113 mA** |

**续航计算：**
```
续航时间 = 220 mAh ÷ 0.113 mA = 1947 小时 ≈ 81 天
```

### 3.5.3 使用外部无源晶振的功耗计算（2分钟间隔）

| 组件 | 功耗 | 占空比/频率 | 平均功耗贡献 |
|---|---|---|---|
| System ON 睡眠 | 1.5 μA | 10秒/周期 × 50% | 0.75 μA |
| 无源晶振驱动 | 0.4 μA | 持续 | 0.4 μA |
| 无需校准开销 | 0 μA | - | 0 μA |
| 无需额外开销 | 0 μA | - | 0 μA |
| 蓝牙广播 | 0.2 mA | 10秒/周期 × 50% | 0.1 mA |
| 无额外开销 | 0 μA | - | 0 μA |
| 唤醒采集 | 6 mA | 0.3秒/120秒 | **0.015 mA** |
| **总计** | - | - | **约 0.102 mA** |

**续航计算：**
```
续航时间 = 220 mAh ÷ 0.102 mA = 2157 小时 ≈ 90 天
```

### 3.5.4 功耗对比总结（2分钟间隔）

| 时钟源 | 睡眠功耗 | 广播功耗 | 采集功耗 | 总平均功耗 | CR2032续航 | 功耗节省 |
|---|---|---|---|---|---|---|
| **内部 RC** | 12 μA | 0.1035 mA | 0.015 mA | **0.113 mA** | 1947小时（81天） | 基准 |
| **外部晶振** | 2.15 μA | 0.1 mA | 0.015 mA | **0.102 mA** | 2157小时（90天） | **11 μA（9.7%）** |

**关键发现：**
- **功耗差异**：约 **11 μA**（与20分钟间隔相同）
- **续航差异**：约 **9 天**（与20分钟间隔相同）
- **采集功耗占比**：2分钟间隔下，采集功耗从 0.0015 mA 增加到 0.015 mA（增加10倍），但占总功耗比例仍然很小（约15%）

### 3.5.5 不同采集间隔的功耗对比

| 采集间隔 | 内部RC功耗 | 外部晶振功耗 | 功耗差异 | 续航差异 |
|---|---|---|---|---|
| **2分钟（120秒）** | 0.113 mA | 0.102 mA | **11 μA** | **9天** |
| **20分钟（1200秒）** | 0.113 mA | 0.102 mA | **11 μA** | **9天** |

**结论：** 采集间隔对内部RC和外部晶振的功耗差异影响很小，因为：
- 功耗差异主要来自RC校准开销（7 μA）和频率不稳定开销（3.5 μA）
- 这些开销是持续存在的，不受采集间隔影响
- 采集功耗虽然随间隔缩短而增加，但占比仍然较小

---

## 4. 10ppm vs 20ppm 的区别（功耗完全相同）

### 4.1 关键发现

**10ppm 和 20ppm 的功耗完全相同！**

- **10ppm 无源晶振**：驱动功耗约 **0.3-0.5 μA**
- **20ppm 无源晶振**：驱动功耗约 **0.3-0.5 μA**
- **功耗差异**：**0 μA**（完全相同）

**原因：** 无源晶振的功耗主要由驱动电路决定，与精度无关。

### 4.2 PPM（Parts Per Million）含义

PPM = Parts Per Million（百万分之一），表示频率精度。

| 参数 | 10 ppm | 20 ppm |
|---|---|---|
| **频率精度** | ±10 ppm | ±20 ppm |
| **32.768kHz 的最大偏差** | ±0.32768 Hz | ±0.65536 Hz |
| **相对误差** | ±0.001% | ±0.002% |
| **精度差异** | **2倍** | 基准 |

### 4.3 时间精度对比

#### 时间误差计算公式

```
时间误差 = (PPM值 / 1,000,000) × 时间
```

#### 不同运行时间下的误差对比

| 运行时间 | 10 ppm 误差 | 20 ppm 误差 | 差异 |
|---|---|---|---|
| **1小时** | 0.036秒 | 0.072秒 | 0.036秒 |
| **1天** | **0.86秒** | **1.73秒** | 0.87秒 |
| **1周** | **6.05秒** | **12.1秒** | 6.05秒 |
| **1个月** | **25.9秒** | **51.8秒** | 25.9秒 |
| **3个月（90天）** | **77.8秒（1.3分钟）** | **155.5秒（2.6分钟）** | 77.7秒 |
| **6个月（180天）** | **155.5秒（2.6分钟）** | **311秒（5.2分钟）** | 155.5秒 |
| **1年（365天）** | **315秒（5.3分钟）** | **630秒（10.5分钟）** | 315秒 |

### 4.4 实际应用中的影响

#### 对20分钟采集间隔的影响

假设运行3个月：

| 精度 | 3个月累积误差 | 对时间戳的影响 |
|---|---|---|
| **10 ppm** | 约 77.8 秒（1.3 分钟） | 时间戳偏差约 ±1.3 分钟 |
| **20 ppm** | 约 155.5 秒（2.6 分钟） | 时间戳偏差约 ±2.6 分钟 |

**结论：** 对于20分钟采集间隔，两种精度的误差差异约1.3分钟，对时间戳记录影响不大。

### 4.5 成本对比（仅供参考）

| 精度 | 典型价格 | 价格差异 | 性价比 |
|---|---|---|---|
| **10 ppm** | ¥0.5-1.0 | 高（约2倍） | 低 |
| **20 ppm** | ¥0.3-0.5 | 基准 | 高 |

### 4.6 选择建议

#### 选择 10ppm 的情况（成本不敏感时推荐）

**优势：**
- ✅ 时间精度更高（10ppm 精度是 20ppm 的 **2倍**）
- ✅ **功耗完全相同**（0.3-0.5 μA，与 20ppm 相同）
- ✅ 长期稳定性更好（温度变化时总误差更小）

**推荐场景：**
- 成本不敏感
- 需要更高精度的时间戳记录
- 需要长期运行（6个月以上）

#### 选择 20ppm 的情况

**优势：**
- ✅ 成本较低（约比 10ppm 便宜 40-50%）
- ✅ 功耗完全相同（与 10ppm 相同）
- ✅ 精度已足够（±2.6 分钟误差在 20 分钟采集间隔下可接受）

**推荐场景：**
- 成本敏感
- 对时间精度要求不高

**结论：** 如果成本不是问题，**推荐选择 10ppm**，因为功耗完全相同但精度更高。

---

## 5. 3225 无源晶振规格要求

### 5.1 关键规格参数

| 参数 | 推荐值 | 说明 |
|---|---|---|
| **封装尺寸** | 3.2mm × 2.5mm (3225) | 标准 SMD 封装 |
| **频率** | 32.768 kHz | 标准 RTC 频率 |
| **负载电容 (CL)** | **12.5 pF**（推荐） | 与 nRF52 系列匹配良好 |
| **频率容差** | ±10 ppm（更高精度）<br>±20 ppm（性价比好） | 温度 25°C |
| **工作温度范围** | -40°C ~ +85°C | 工业级 |
| **等效串联电阻 (ESR)** | 30-70 kΩ | 影响启动时间 |
| **驱动功率** | 0.1-1.0 μW | 低功耗要求 |

### 5.2 推荐晶振型号

#### 推荐型号 1：FC-135 系列（精工）

- **型号**：FC-135 32.7680KA-A5（10ppm）或 FC-135 32.7680KA-A0（20ppm）
- **封装**：3.2 × 2.5mm (3225)
- **负载电容**：12.5 pF
- **频率容差**：±10 ppm 或 ±20 ppm
- **ESR**：50 kΩ（典型）
- **价格**：¥0.3-1.0（取决于精度）

#### 推荐型号 2：YST310S（扬兴）

- **型号**：YST310S 32.768kHz
- **封装**：3.2 × 2.5mm (3225)
- **负载电容**：12.5 pF
- **频率容差**：±20 ppm
- **ESR**：50 kΩ（典型）
- **价格**：¥0.3-0.5

---

## 6. 负载电容规格与计算

### 6.1 负载电容计算公式

```
CL = (C1 × C2) / (C1 + C2) + C_stray

其中：
- CL：晶振规格上的负载电容（如 12.5 pF）
- C1, C2：外部负载电容（通常相等）
- C_stray：寄生电容（PCB布线、焊盘等，通常 2-5 pF）
```

### 6.2 nRF52810 推荐配置

如果选择 **CL = 12.5 pF** 的晶振：

```
假设 C_stray = 2-3 pF（保守估算）

目标：CL = 12.5 pF

如果 C1 = C2 = C，则：
12.5 = (C × C) / (C + C) + 2.5
12.5 = C/2 + 2.5
C = 2 × (12.5 - 2.5) = 20 pF

因此：C1 = C2 = 18-22 pF（推荐 20-22 pF）
```

### 6.3 负载电容推荐规格

| 参数 | 推荐值 | 说明 |
|---|---|---|
| **封装** | 0402 或 0603 | SMD 封装 |
| **容值** | **22 pF ±5%** | 推荐值 |
| **温度特性** | **C0G/NP0** | 温度稳定性好 |
| **耐压** | ≥16V | - |
| **推荐型号** | GRM1885C1H220JA01（0603）<br>GRM1555C1H220JA01（0402） | 村田或同等规格 |

### 6.4 完整元器件清单

| 元器件 | 规格 | 数量 | 推荐型号/值 | 单价（参考） |
|---|---|---|---|---|
| **无源晶振** | 32.768kHz, 3225, CL=12.5pF | 1 | FC-135 32.7680KA-A5（10ppm）<br>或 FC-135 32.7680KA-A0（20ppm） | ¥0.3-1.0 |
| **负载电容** | 22pF ±5%, C0G, 0603/0402 | 2 | GRM1885C1H220JA01 | ¥0.02 |

**总成本：** 约 ¥0.34-1.04（取决于精度选择）

---

## 7. PCB 布局建议

### 7.1 晶振位置

- **尽量靠近** nRF52810 的 XL1/XL2 引脚
- **走线长度** < 10mm
- **走线对称**，等长

### 7.2 负载电容位置

- **尽量靠近晶振**
- C1 靠近晶振一端
- C2 靠近晶振另一端

### 7.3 布线规则

- **走线宽度**：0.15-0.2mm
- **走线间距**：尽量远离其他信号
- **地平面**：晶振下方保留地平面
- **避免走线**：晶振下方避免走其他信号线

### 7.4 布局示意图

```
┌─────────────────┐
│                 │
│   nRF52810      │
│                 │
│  XL1 ────┐      │
│          │      │
│  XL2 ────┼──┐   │
│          │  │   │
└──────────┼──┼───┘
           │  │
       ┌───┘  └───┐
       │          │
    C1 │    晶振  │ C2
  22pF │  3225    │ 22pF
       │          │
       └──────────┘
           │ │
          GND GND
```

---

## 8. 软件配置修改

### 8.1 修改 prj.conf

```conf
# 时钟配置
CONFIG_CLOCK_CONTROL_NRF_K32SRC_XTAL=y  # 启用外部晶振
CONFIG_CLOCK_CONTROL_NRF_K32SRC_RC=n    # 禁用内部RC
CONFIG_CLOCK_CONTROL_NRF_K32SRC_500PPM=n  # 不需要500ppm校准
```

### 8.2 修改代码注释

在 `src/main.c` 中更新注释：

```c
/*
 * 重要配置说明：
 * - 时钟配置：使用外部 32.768kHz 无源晶振
 *   在 prj.conf 中已配置：
 *   CONFIG_CLOCK_CONTROL_NRF_K32SRC_XTAL=y  (使用外部晶振作为 32kHz 时钟源)
 *   CONFIG_CLOCK_CONTROL_NRF_K32SRC_RC=n    (禁用内部RC)
 */
```

---

## 9. 功耗优化效果总结

### 9.1 各项优化对比

| 优化项 | 功耗节省 | 续航提升 |
|---|---|---|
| **启用电源管理（CONFIG_PM=y）** | 已包含 | - |
| **关闭 UART** | ~0.75 mA | +6天 |
| **关闭 LED** | ~0.001 mA | 可忽略 |
| **外部晶振（10ppm/20ppm）** | **~11 μA** | **+9天** |
| **间歇广播（10秒/10秒）** | 已包含 | - |
| **总计** | **约 0.761 mA 节省** | **约 15 天提升** |

### 9.2 最终功耗对比

| 配置 | 总平均功耗 | CR2032续航 |
|---|---|---|
| **原始配置（无优化）** | ~15 mA | 14.7小时 |
| **基础优化（PM+关闭UART+LED）** | ~0.109 mA | 2018小时（84天） |
| **添加外部晶振（10ppm/20ppm）** | **~0.102 mA** | **2157小时（90天）** |

---

## 10. 注意事项

### 10.1 晶振选择注意事项

1. **负载电容匹配**：必须选择 CL = 12.5 pF 的晶振
2. **ESR 范围**：ESR 应在 30-70 kΩ 范围内
3. **温度范围**：确保工作温度范围覆盖应用环境（-40°C ~ +85°C）

### 10.2 电容选择注意事项

1. **温度特性**：必须使用 C0G/NP0 材质（温度稳定性好）
2. **精度**：建议使用 ±5% 精度
3. **容值**：推荐 20-22 pF

### 10.3 调试验证

1. **晶振起振时间**：检查晶振起振时间（通常 0.3-1 秒）
2. **频率精度**：测试频率精度是否符合规格
3. **低功耗模式**：确认在低功耗模式下正常工作
4. **长期稳定性**：长期运行测试，确认时间精度稳定

---

## 11. 总结

### 11.1 关键结论

1. **功耗节省**：使用外部 32.768kHz 无源晶振可以节省约 **11 μA** 功耗（相比内部 RC）
2. **续航提升**：续航提升约 **9 天**（从 81 天到 90 天）
3. **10ppm vs 20ppm**：**功耗完全相同**，区别仅在于时间精度（10ppm 是 20ppm 的 2倍）
4. **推荐配置**：如果成本不敏感，推荐选择 **10ppm**（精度更高，功耗相同）

### 11.2 推荐配置

- **晶振**：32.768kHz, 3225, CL=12.5pF, ±10 ppm（如：FC-135 32.7680KA-A5）
- **负载电容**：22pF ±5%, C0G, 0402/0603（2 个，如：GRM1885C1H220JA01）
- **预期功耗节省**：约 **11 μA**（相比内部 RC）
- **预期续航提升**：约 **9 天**（从 81 天到 90 天）

---

**文档版本：** 1.0  
**更新日期：** 2026-01-16  
**适用平台：** nRF52810 (E104-BT5010A)

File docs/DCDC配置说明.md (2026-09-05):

# DCDC 配置说明

## 问题说明

启用 `CONFIG_BOARD_ENABLE_DCDC=y` 后无法编译，可能的原因：

1. **配置项不存在**：`CONFIG_BOARD_ENABLE_DCDC` 可能不是正确的配置项名称
2. **硬件不支持**：E104-BT5010A 模块可能没有 DCDC 所需的电感
3. **板级配置缺失**：需要在设备树中配置 DCDC regulator

## 重要说明：编译时 vs 运行时

### 编译时检查

**如果芯片/板级不支持 DCDC：**
- ✅ **编译通常可以通过**（如果配置项存在）
- ⚠️ **编译可能失败**（如果配置项不存在或 Kconfig 检查失败）
- ⚠️ **编译可能失败**（如果设备树配置错误）

**关键点：**
- nRF52810 **芯片本身支持 DCDC**（这是硬件特性）
- 但**模块可能没有外部电感**（这是硬件设计问题）
- 编译系统**无法检测**模块是否有电感（这是运行时问题）

### 运行时问题

**如果模块没有电感但启用了 DCDC：**
- ❌ **芯片无法正常启动**（电源电压不稳定）
- ❌ **可能"变砖"**（无法编程）
- ❌ **功耗异常**（可能更高或更低）

**结论：**
- **编译通过 ≠ 硬件支持**
- **必须检查模块硬件**（原理图或实物）

---

## DCDC 工作原理

nRF52810 内部有一个 DCDC 转换器（开关电源），可以替代 LDO（线性稳压器），降低功耗约 40%。

**关键要求：**
- ✅ **必须**有外部电感（通常 10 µH）
- ✅ **必须**有滤波电容
- ✅ **必须**正确的 PCB 布局

**如果没有电感：**
- ❌ 芯片无法正常启动
- ❌ 可能"变砖"（无法编程）
- ❌ 电源电压不稳定

---

## 检查 E104-BT5010A 模块是否支持 DCDC

### 方法 1：查看模块原理图

检查 E104-BT5010A 模块的原理图，查找：
- **电感符号**（L1, L2 等）
- **DCDC 相关引脚**（DCCH, VDDH 等）
- **滤波电容**（靠近 DCDC 引脚）

### 方法 2：查看模块数据表

查看 `E104-BT5010A+datasheet_CN_v2.0.pdf`，查找：
- DCDC 相关说明
- 电源管理部分
- 原理图部分

### 方法 3：查看模块实物

检查模块 PCB 上是否有：
- **电感元件**（通常为黑色或灰色，有线圈）
- **DCDC 相关电路**（靠近电源引脚）

---

## 正确的配置方法

### 方法 1：使用设备树配置（推荐）

如果模块支持 DCDC，需要在设备树中配置：

**在 `app.overlay` 或板级 overlay 中添加：**

```dts
&regulator {
    status = "okay";
};

&vreg {
    regulator-dcdc-enable;
};
```

### 方法 2：使用 Kconfig 配置

在 `prj.conf` 中：

```conf
# 启用 regulator 驱动
CONFIG_REGULATOR=y
CONFIG_REGULATOR_NRF=y

# 如果板级支持，启用 DCDC
# 注意：这个配置项可能不存在，取决于板级定义
# CONFIG_BOARD_ENABLE_DCDC=y
```

### 方法 3：检查板级支持

检查 Zephyr 板级定义中是否有 DCDC 支持：

```bash
# 查找板级配置文件
find $ZEPHYR_BASE/boards -name "*e104*" -o -name "*bt5010a*"
```

---

## 如果模块不支持 DCDC（需要手动添加电感）

### 硬件要求

| 元件 | 规格 | 数量 | 说明 |
|---|---|---|---|
| **电感** | 10 µH, 饱和电流 > 100mA | 1 | 推荐：LPS4018-103MRB (10µH) |
| **滤波电容** | 10 µF, 陶瓷, X7R | 1 | 靠近 DCDC 引脚 |
| **去耦电容** | 100 nF, 陶瓷 | 1 | 靠近 VDD 引脚 |

### 电路连接

```
VDD (3.3V) ──┬── 10µF ──┬── 10µH 电感 ──┬── DCCH (nRF52810)
             │          │                │
           100nF       GND              GND
```

### PCB 布局要求

1. **电感位置**：尽量靠近 nRF52810 的 DCCH 引脚（< 5mm）
2. **电容位置**：靠近电感和芯片引脚
3. **走线宽度**：电源走线至少 0.5mm
4. **地平面**：DCDC 电路下方保留完整地平面

### 注意事项

⚠️ **警告**：
- 如果电感连接错误，可能导致芯片损坏
- 建议先在不重要的板子上测试
- 确保电感规格正确（饱和电流、DCR 等）

---

## 验证 DCDC 是否工作

### 方法 1：功耗测试

启用 DCDC 后，功耗应该降低约 40%：
- **未启用 DCDC**：广播功耗约 0.2-0.3 mA
- **启用 DCDC**：广播功耗约 0.12-0.18 mA

### 方法 2：电压测试

使用示波器测量：
- **DCCH 引脚**：应该有开关波形（约 1-2 MHz）
- **VDD 引脚**：应该稳定在 3.3V

### 方法 3：代码检查

在代码中检查 regulator 状态：

```c
#include <zephyr/drivers/regulator.h>

static const struct device *reg_dev = DEVICE_DT_GET(DT_NODELABEL(regulator));

if (device_is_ready(reg_dev)) {
    printk("DCDC regulator is ready\n");
} else {
    printk("DCDC regulator not available\n");
}
```

---

## 推荐方案

### 方案 1：如果模块已支持 DCDC（推荐）

1. ✅ 检查模块原理图，确认有电感
2. ✅ 在设备树中配置 DCDC
3. ✅ 启用 regulator 驱动
4. ✅ 测试功耗是否降低

### 方案 2：如果模块不支持 DCDC

**选项 A：不启用 DCDC（简单）**
- ✅ 保持当前配置（使用 LDO）
- ✅ 功耗略高，但稳定可靠
- ✅ 无需硬件修改

**选项 B：手动添加电感（复杂）**
- ⚠️ 需要硬件修改
- ⚠️ 需要重新设计 PCB
- ⚠️ 风险较高

---

## 当前建议

**基于你的情况，建议：**

1. **先检查模块**：查看 E104-BT5010A 模块原理图或数据表，确认是否支持 DCDC
2. **如果支持**：使用设备树配置启用 DCDC
3. **如果不支持**：**暂时不启用 DCDC**，优先实施其他功耗优化措施：
   - 关闭 UART/PRINTK（节省 0.5-1 mA）
   - 优化 LED（节省 0.5-1 mA）
   - 启用 PM 系统（节省 3-4 mA）

**DCDC 的功耗节省（0.5-1 mA）相对较小，不如其他优化措施明显。**

---

## 相关文档

- `docs/功耗优化完整方案.md` - 完整的功耗优化方案
- `E104-BT5010A+datasheet_CN_v2.0.pdf` - 模块数据表

---

**文档版本：** 1.0  
**更新日期：** 2026-01-16  
**适用平台：** nRF52810 (E104-BT5010A)

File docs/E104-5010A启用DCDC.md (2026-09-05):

nRF Connect SDK（NCS/Zephyr）配置
在prj.conf中添加：
# 启用DCDC转换器
CONFIG_NRF_POWER_DCDC_ENABLE=y
# 射频电路强制使用DCDC
CONFIG_BT_CTLR_DCDC_ENABLE=y
# 系统电源管理优化
CONFIG_PM=y
代码中验证：

#include <zephyr/drivers/clock_control.h>
#include <zephyr/drivers/power.h>

if (power_dcdc_is_enabled()) {
    printk("DCDC is enabled\n");
}

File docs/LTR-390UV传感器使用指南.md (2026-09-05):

# LTR-390UV 紫外线/环境光传感器使用指南

## 概述

LTR-390UV 是一款集成了紫外线 (UV) 和环境光 (ALS) 传感器的 I2C 接口芯片，适用于可穿戴设备、智能家居等应用场景。

### 主要特性

- I2C 接口，地址 0x53
- 支持 UV 和 ALS 两种测量模式
- 20 位 ADC 分辨率
- 可配置增益 (1x ~ 18x)
- 可配置积分时间 (12.5ms ~ 400ms)
- 低功耗设计
- 工作电压: 1.7V ~ 3.6V

## 硬件连接

LTR-390UV 通过 I2C0 总线连接到 nRF52832：

| LTR-390UV 引脚 | nRF52832 引脚 | 说明 |
|---|---|---|
| VDD | 3.3V | 电源 |
| GND | GND | 地 |
| SCL | P0.6 | I2C 时钟线 |
| SDA | P0.7 | I2C 数据线 |
| INT | (可选) | 中断输出 |

## 软件集成

### 1. 文件结构

```
src/sensors/
├── ltr390.h              # 驱动头文件
├── ltr390.c              # 驱动实现
└── ltr390_example.c      # 使用示例
```

### 2. 在 CMakeLists.txt 中添加源文件

```cmake
target_sources(app PRIVATE
    src/sensors/ltr390.c
    # 如果需要示例代码
    # src/sensors/ltr390_example.c
)
```

### 3. 在 prj.conf 中启用 I2C

```ini
# I2C 配置
CONFIG_I2C=y
```

### 4. 在 overlay 文件中配置 I2C

确保 `app.overlay` 或对应的板级 overlay 文件中已配置 I2C0：

```dts
&i2c0 {
    compatible = "nordic,nrf-twi";
    status = "okay";
    clock-frequency = <I2C_BITRATE_STANDARD>; /* 100kHz */
    
    pinctrl-0 = <&i2c0_default>;
    pinctrl-1 = <&i2c0_sleep>;
    pinctrl-names = "default", "sleep";
};

&pinctrl {
    i2c0_default: i2c0_default {
        group1 {
            psels = <NRF_PSEL(TWIM_SDA, 0, 7)>,
                    <NRF_PSEL(TWIM_SCL, 0, 6)>;
        };
    };

    i2c0_sleep: i2c0_sleep {
        group1 {
            psels = <NRF_PSEL(TWIM_SDA, 0, 7)>,
                    <NRF_PSEL(TWIM_SCL, 0, 6)>;
            low-power-enable;
        };
    };
};
```

## API 使用说明

### 初始化

```c
#include "ltr390.h"

const struct device *i2c_dev = DEVICE_DT_GET(DT_NODELABEL(i2c0));

int ret = ltr390_init(i2c_dev);
if (ret != 0) {
    printk("LTR-390UV 初始化失败: %d\n", ret);
}
```

### 配置传感器

#### 设置增益

```c
// 增益选项: GAIN_1, GAIN_3, GAIN_6, GAIN_9, GAIN_18
ltr390_set_gain(LTR390_GAIN_3);  // 3x 增益，适合室内
```

增益选择建议：
- 室内环境光: 18x (高灵敏度)
- 一般场景: 3x (默认)
- 户外强光: 1x (避免饱和)

#### 设置分辨率和测量速率

```c
// 分辨率选项及对应测量时间:
// RESOLUTION_20BIT_400MS  - 20位, 400ms (最高精度)
// RESOLUTION_19BIT_200MS  - 19位, 200ms
// RESOLUTION_18BIT_100MS  - 18位, 100ms (默认，平衡)
// RESOLUTION_17BIT_50MS   - 17位, 50ms
// RESOLUTION_16BIT_25MS   - 16位, 25ms
// RESOLUTION_13BIT_12_5MS - 13位, 12.5ms (最快速度)

ltr390_set_resolution(LTR390_RESOLUTION_18BIT_100MS);
```

### 读取紫外线数据

```c
uint32_t uvs_data;
int ret = ltr390_read_uvs(&uvs_data);
if (ret == 0) {
    // 计算 UV 指数 (放大 100 倍)
    int32_t uvi = ltr390_calculate_uvi(uvs_data);
    printk("UV 指数: %d.%02d\n", uvi / 100, uvi % 100);
}
```

UV 指数等级：
- 0-2: 低，可以安全待在户外
- 3-5: 中等，需要防晒措施
- 6-7: 高，必须采取防晒措施
- 8-10: 很高，避免在正午外出
- 11+: 极高，尽量待在室内

### 读取环境光数据

```c
uint32_t als_data;
int ret = ltr390_read_als(&als_data);
if (ret == 0) {
    // 计算光照强度 (Lux，放大 100 倍)
    int32_t lux = ltr390_calculate_lux(als_data);
    printk("光照强度: %d.%02d Lux\n", lux / 100, lux % 100);
}
```

光照强度参考：
- 0.1 Lux: 月光
- 10-50 Lux: 室内照明
- 100-500 Lux: 办公室照明
- 1000 Lux: 阴天室外
- 10000-25000 Lux: 晴天室外
- 100000 Lux: 直射阳光

## 完整示例

```c
#include "ltr390.h"
#include <zephyr/kernel.h>
#include <zephyr/device.h>

void main(void)
{
    const struct device *i2c_dev;
    uint32_t uvs_data, als_data;
    int32_t uvi, lux;
    int ret;

    // 获取 I2C 设备
    i2c_dev = DEVICE_DT_GET(DT_NODELABEL(i2c0));
    if (!device_is_ready(i2c_dev)) {
        printk("I2C 设备未就绪\n");
        return;
    }

    // 初始化传感器
    ret = ltr390_init(i2c_dev);
    if (ret != 0) {
        printk("初始化失败\n");
        return;
    }

    // 配置传感器
    ltr390_set_gain(LTR390_GAIN_3);
    ltr390_set_resolution(LTR390_RESOLUTION_18BIT_100MS);

    // 循环读取
    while (1) {
        // 读取 UV
        ret = ltr390_read_uvs(&uvs_data);
        if (ret == 0) {
            uvi = ltr390_calculate_uvi(uvs_data);
            printk("UV 指数: %d.%02d\n", uvi / 100, uvi % 100);
        }

        // 读取环境光
        ret = ltr390_read_als(&als_data);
        if (ret == 0) {
            lux = ltr390_calculate_lux(als_data);
            printk("光照: %d.%02d Lux\n", lux / 100, lux % 100);
        }

        k_msleep(5000);  // 5 秒间隔
    }
}
```

## 场景配置建议

### 室内环境光监测

```c
ltr390_set_gain(LTR390_GAIN_18);              // 高灵敏度
ltr390_set_resolution(LTR390_RESOLUTION_20BIT_400MS);  // 高精度
```

### 户外 UV 监测

```c
ltr390_set_gain(LTR390_GAIN_1);               // 避免饱和
ltr390_set_resolution(LTR390_RESOLUTION_16BIT_25MS);   // 快速响应
```

### 低功耗模式

```c
ltr390_set_gain(LTR390_GAIN_3);               // 平衡
ltr390_set_resolution(LTR390_RESOLUTION_13BIT_12_5MS); // 最快速度
```

## 注意事项

1. **模式切换**: LTR-390UV 不能同时测量 UV 和 ALS，需要切换模式。驱动会自动处理模式切换，但每次切换需要等待一个测量周期。

2. **数据就绪**: 读取数据前，驱动会自动等待数据就绪。根据配置的分辨率，等待时间从 12.5ms 到 400ms 不等。

3. **增益选择**: 
   - 增益过高可能导致强光下饱和
   - 增益过低可能导致弱光下精度不足
   - 建议根据实际环境动态调整

4. **UV 测量**: 
   - 玻璃会阻挡大部分 UV，室内测量值通常很低
   - 建议在户外或窗边测量
   - 阴天也有 UV 辐射

5. **功耗优化**:
   - 使用较短的积分时间可降低功耗
   - 不需要时可以关闭传感器 (写 0x00 到 MAIN_CTRL)

## 故障排查

### 传感器无响应

1. 检查 I2C 连接和地址 (0x53)
2. 确认电源供电正常 (1.7V ~ 3.6V)
3. 检查上拉电阻 (SCL/SDA 需要 4.7kΩ 上拉)

### 读数异常

1. 检查增益设置是否合适
2. 确认测量环境 (室内 UV 通常很低)
3. 等待足够的测量时间

### 数据饱和

1. 降低增益 (从 18x 降到 1x)
2. 缩短积分时间
3. 避免传感器直接对准强光源

## 参考资料

- [LTR-390UV 数据手册](https://optoelectronics.liteon.com/upload/download/DS86-2015-0004/LTR-390UV_Final_%20DS_V1%201.pdf)
- [应用笔记: UV 指数计算](https://optoelectronics.liteon.com/upload/download/AN86-2015-0003/AN_LTR-390UV_UV%20Sensor_ver%201.pdf)

## 版本历史

- v1.0 (2026-02-14): 初始版本
  - 支持 UV 和 ALS 测量
  - 可配置增益和分辨率
  - UV 指数和 Lux 计算

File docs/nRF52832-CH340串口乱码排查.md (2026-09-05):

# nRF52832 + CH340 串口乱码排查

## 当前配置

- **52832 板级**（`boards/nrf52832dk_nrf52832_cpuapp.overlay`）：UART0 已设为 **4800** 波特率（因 115200/9600 在部分 CH340 上易乱码）。
- **终端**：必须与固件一致，设为 **4800 8N1**，无硬件流控。

## 若仍乱码请逐项检查

### 1. 波特率与格式一致

- 串口助手 / 终端：**4800，8 数据位，无校验，1 停止位（8N1）**。
- 关闭 RTS/CTS 等硬件流控。

### 2. CH340 使用注意

- **驱动**：安装 CH340 官方或最新驱动，设备管理器中 COM 口无叹号。
- **接线**：MCU TX（P0.18）→ CH340 **RX**；MCU RX（P0.14）→ CH340 **TX**；**GND 共地**。
- **电平**：nRF52832 为 3.3V，CH340 需 3.3V 兼容（或经电平转换）；5V 直连可能损坏或异常。

### 3. 可再试的波特率

若 4800 仍乱：

- 在 52832 overlay 中把 `current-speed` 改为 **2400** 再编译烧录，终端也改为 2400 8N1 测试。
- 若 2400 正常，多半是 MCU 侧时钟偏差导致高波特率不准；若 2400 仍乱，重点查接线、共地、CH340 驱动与电平。

### 4. 其他

- 换一根 USB 线或换一个 CH340 模块排除硬件故障。
- 若有 J-Link，可考虑用 **RTT** 看日志，不依赖 UART 波特率（需在 prj.conf 开启 `CONFIG_USE_SEGGER_RTT=y` 等）。

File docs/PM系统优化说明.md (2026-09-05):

# PM 系统优化说明

## 什么是 PM 系统？

**PM（Power Management，电源管理）系统**是 Zephyr RTOS 提供的低功耗管理框架，可以自动让 MCU 进入低功耗模式，大幅降低功耗。

---

## PM 系统如何降低功耗？

### 当前状态（未启用 PM）

**主循环代码：**
```c
while (1) {
    k_sleep(K_SECONDS(10));  // CPU 进入空闲，但功耗仍然较高
}
```

**功耗情况：**
- CPU 虽然进入空闲，但**没有进入低功耗模式**
- 系统时钟仍在运行
- 外设时钟可能未关闭
- **功耗：约 4-5 mA**

### 启用 PM 系统后

**工作原理：**
1. 当所有线程都进入睡眠（`k_sleep()`）时
2. PM 系统**自动检测**到系统空闲
3. **自动关闭**不需要的外设时钟
4. **降低 CPU 频率**或进入 **System ON 睡眠模式**
5. 由定时器或中断**自动唤醒**

**功耗情况：**
- CPU 进入 **System ON 睡眠模式**
- 大部分外设时钟关闭
- 仅保留必要的唤醒源（定时器、蓝牙中断等）
- **功耗：约 1-2 μA**（睡眠时）

---

## 功耗对比

| 状态 | 未启用 PM | 启用 PM | 节省 |
|---|---|---|---|
| **运行模式** | 4-5 mA | 4-5 mA | 0 |
| **空闲/睡眠** | 4-5 mA | **1-2 μA** | **约 4-5 mA** |
| **平均功耗** | 4-5 mA | **0.5-2 mA** | **约 3-4 mA** |

**关键点：**
- 系统大部分时间处于空闲状态（等待定时器、蓝牙事件）
- PM 系统让空闲时功耗从 **4-5 mA 降至 1-2 μA**
- **这是最大的功耗优化项！**

---

## 当前代码状态

### 配置状态

**prj.conf：**
```conf
CONFIG_PM=y  # ✅ 已启用
```

**src/main.c：**
```c
// ❌ PM 头文件被注释掉了
// #include <zephyr/pm/pm.h>
// #include <zephyr/pm/device.h>
// #include <zephyr/pm/policy.h>
```

**问题：**
- 配置已启用，但代码中头文件被注释
- 注释说明：存在 **USAGE FAULT (PC=0x00000000)** 问题
- 可能是 PM 回调函数空指针问题

---

## PM 系统的工作模式

### nRF52810 支持的功耗模式

| 模式 | 功耗 | 说明 | 唤醒方式 |
|---|---|---|---|
| **运行模式** | 4-5 mA | CPU 全速运行 | - |
| **System ON (浅度睡眠)** | **1-2 μA** | RAM 保持，外设可唤醒 | 定时器、GPIO、蓝牙中断 |
| **System OFF (深度睡眠)** | 0.4-1.5 μA | RAM 丢失，需要复位 | 复位、GPIO 唤醒 |

**PM 系统通常使用 System ON 模式：**
- ✅ RAM 数据保持（不需要重新初始化）
- ✅ 功耗极低（1-2 μA）
- ✅ 可被定时器和蓝牙中断唤醒

---

## 如何启用 PM 系统？

### 步骤 1：确保配置正确

**prj.conf：**
```conf
# 电源管理
CONFIG_PM=y
CONFIG_PM_DEVICE=y          # 启用设备级电源管理
CONFIG_PM_DEVICE_RUNTIME=y  # 启用运行时电源管理（可选）
```

### 步骤 2：修复代码问题

**问题：** USAGE FAULT (PC=0x00000000) - 可能是 PM 回调函数空指针

**解决方案 A：最小化 PM 使用（推荐）**

实际上，**如果只使用 `k_sleep()`，PM 系统应该能自动工作**，不需要显式包含 PM 头文件！

**测试方法：**
1. 保持当前代码（PM 头文件注释掉）
2. 确保 `CONFIG_PM=y` 已启用
3. 使用 `k_sleep()` 让系统进入空闲
4. **测量功耗**，看是否进入低功耗模式

**如果功耗仍然很高（4-5 mA），说明 PM 没有生效。**

**解决方案 B：修复 PM 回调问题**

如果需要显式使用 PM API，需要修复回调函数：

```c
#include <zephyr/pm/pm.h>
#include <zephyr/pm/policy.h>

// 定义 PM 策略回调（如果需要）
static void pm_policy_cb(struct pm_state_info *info)
{
    // 实现 PM 策略
    // 注意：确保回调函数不为空
}
```

### 步骤 3：验证 PM 是否工作

**方法 1：功耗测试**
- 测量系统空闲时的功耗
- 如果从 4-5 mA 降至 1-2 μA，说明 PM 工作正常

**方法 2：代码检查**
```c
// 在 k_sleep() 前后打印信息
printk("准备进入睡眠...\n");
k_sleep(K_SECONDS(10));
printk("从睡眠中唤醒\n");
```

**方法 3：使用 PM 统计（如果支持）**
```c
#include <zephyr/pm/pm_stats.h>

// 查看 PM 统计信息
pm_stats_dump();
```

---

## 为什么当前 PM 可能没有生效？

### 可能的原因

1. **PM 头文件被注释**
   - 虽然 `CONFIG_PM=y`，但可能某些初始化代码被跳过

2. **外设阻止进入低功耗**
   - UART 持续输出可能阻止睡眠
   - 某些外设未正确配置为低功耗模式

3. **定时器配置问题**
   - 如果定时器配置不当，系统可能无法进入睡眠

4. **蓝牙阻止睡眠**
   - 蓝牙广播时，系统可能无法进入深度睡眠
   - 但应该能进入 System ON 模式

### 检查清单

- [ ] `CONFIG_PM=y` 已启用
- [ ] 主循环使用 `k_sleep()` 或 `k_msleep()`
- [ ] 没有阻塞的线程
- [ ] UART 在睡眠时关闭（如果可能）
- [ ] 外设配置了低功耗模式

---

## 优化建议

### 方案 1：先测试当前状态（最简单）

1. **保持当前代码**（PM 头文件注释）
2. **确保 `CONFIG_PM=y`**
3. **测量功耗**：
   - 如果空闲时功耗是 1-2 μA → PM 已工作 ✅
   - 如果空闲时功耗是 4-5 mA → PM 未工作 ❌

### 方案 2：修复 PM 回调问题（如果需要）

如果方案 1 测试发现 PM 未工作，需要：

1. **检查是否有 PM 回调函数**
2. **确保回调函数不为空**
3. **或者移除不必要的 PM 回调**

### 方案 3：使用设备级 PM（推荐）

**在设备树中配置外设低功耗：**

```dts
&uart0 {
    status = "okay";
    // 启用运行时 PM
    zephyr,pm-device-runtime-auto;
};
```

**在代码中手动管理外设：**
```c
#include <zephyr/pm/device.h>

// 外设使用完后，手动挂起
pm_device_action_run(uart_dev, PM_DEVICE_ACTION_SUSPEND);
```

---

## 预期效果

### 启用 PM 系统后

**功耗对比：**

| 场景 | 未启用 PM | 启用 PM | 节省 |
|---|---|---|---|
| **广播中** | 5-8 mA | 5-8 mA | 0 |
| **空闲（等待）** | 4-5 mA | **1-2 μA** | **约 4-5 mA** |
| **平均功耗** | 12-18 mA | **5-10 mA** | **约 3-8 mA** |

**续航提升：**
- 当前：约 15 小时（CR2032, 220mAh）
- 启用 PM 后：约 **22-44 小时**（1.5-3 倍提升）

---

## 总结

**PM 系统是最重要的功耗优化项：**

1. ✅ **自动管理**：无需手动控制，系统空闲时自动进入低功耗
2. ✅ **大幅降低功耗**：从 4-5 mA 降至 1-2 μA（约 2000 倍降低）
3. ✅ **保持功能**：RAM 数据保持，可被定时器和中断唤醒
4. ✅ **实现简单**：只需 `CONFIG_PM=y` 和使用 `k_sleep()`

**当前状态：**
- 配置已启用（`CONFIG_PM=y`）
- 但代码中头文件被注释（可能存在回调问题）
- **建议先测试功耗，确认 PM 是否已工作**

---

## 相关文档

- `docs/功耗优化完整方案.md` - 完整的功耗优化方案
- `docs/功耗评估与优化方案.md` - 功耗分析文档

---

**文档版本：** 1.0  
**更新日期：** 2026-01-16  
**适用平台：** nRF52810 (E104-BT5010A)

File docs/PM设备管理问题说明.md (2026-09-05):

# PM 设备管理问题说明

## 问题描述

在编译项目时遇到链接错误：

```
undefined reference to `__device_dts_ord_77'
```

## 问题原因

1. **设备树配置**：设备树中某些设备（如 `i2c0`、`adc`）带有 `zephyr,pm-device-runtime-auto` 属性
2. **PM 设备功能**：启用 `CONFIG_PM_DEVICE=y` 后，系统会为这些设备自动创建 PM（电源管理）设备实例
3. **驱动实现问题**：某些设备的驱动可能未正确实现 PM 功能，导致链接时找不到对应的设备符号 `__device_dts_ord_77`

## 当前解决方案

### 方案 1：禁用 PM_DEVICE（已采用）

在 `prj.conf` 中禁用 `CONFIG_PM_DEVICE`：

```conf
# 电源管理（低功耗必需）
CONFIG_PM=y
# 暂时禁用 PM_DEVICE，避免链接错误 __device_dts_ord_77
# CONFIG_PM_DEVICE=y
```

**影响**：

- ✅ 系统级电源管理（`k_sleep()` 等）仍然可用
- ✅ 系统可以正常进入低功耗模式
- ❌ 设备级自动 PM 管理被禁用（设备不会自动进入低功耗状态）

### 方案 2：在设备树中删除 PM 运行时属性（备选）

在 `app.overlay` 中删除设备的 `zephyr,pm-device-runtime-auto` 属性：

```dts
&i2c0 {
    /delete-property/ zephyr,pm-device-runtime-auto;
};

&adc {
    /delete-property/ zephyr,pm-device-runtime-auto;
};
```

**注意**：此方案需要确保 `CONFIG_PM_DEVICE_RUNTIME=n`，否则可能仍有问题。

## 功能影响

### 当前状态（CONFIG_PM_DEVICE 禁用）

- ✅ **系统级低功耗**：`k_sleep()` 可以让系统进入 System ON 模式，功耗降低
- ✅ **定时器唤醒**：系统可以从低功耗模式被定时器中断唤醒
- ✅ **蓝牙唤醒**：系统可以从低功耗模式被蓝牙中断唤醒
- ❌ **设备级自动 PM**：I2C、ADC 等设备不会自动进入低功耗状态（需要手动控制）

### 如果启用 CONFIG_PM_DEVICE

- ✅ **设备级自动 PM**：设备在空闲时自动进入低功耗状态
- ✅ **更精细的功耗控制**：可以单独控制每个设备的电源状态
- ❌ **当前问题**：链接错误 `__device_dts_ord_77` 未定义

## 未来解决方案

### 方案 A：等待驱动修复

等待 Zephyr/NCS 更新，修复相关驱动的 PM 设备实现问题。

### 方案 B：手动实现设备 PM 控制

如果需要设备级 PM 管理，可以：

1. 在代码中手动控制设备的电源状态
2. 使用 HAL 层 API 直接操作寄存器
3. 不使用 Zephyr 的 PM_DEVICE 框架

### 方案 C：使用设备树覆盖

创建专门的设备树覆盖文件，确保所有设备的 PM 配置正确。

## 相关文件

- `prj.conf`：电源管理配置
- `app.overlay`：设备树覆盖配置
- `src/main.c`：主程序（已注释 PM_DEVICE 相关头文件）

## 参考信息

- Zephyr PM 设备文档：https://docs.zephyrproject.org/latest/services/pm/device.html
- NCS 3.2.1 电源管理：https://developer.nordicsemi.com/nRF_Connect_SDK/doc/latest/zephyr/services/pm/device.html
- 设备树 PM 属性：`zephyr,pm-device-runtime-auto`

## 更新记录

- 2024-XX-XX：首次记录问题，采用方案 1（禁用 CONFIG_PM_DEVICE）

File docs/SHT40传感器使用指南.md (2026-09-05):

# SHT40 温湿度传感器使用指南

## 概述

SHT40 是 Sensirion 公司推出的新一代数字温湿度传感器，具有高精度、低功耗、小尺寸等特点，是 SHT3x 系列的升级版本。

### 主要特性

- I2C 接口，地址 0x44 (ADDR 接地) 或 0x45 (ADDR 接 VDD)
- 温度精度: ±0.2°C (高精度模式)
- 湿度精度: ±1.8%RH (高精度模式)
- 测量时间: 1.7ms ~ 8.2ms (可配置)
- 内置加热器，可去除传感器表面冷凝
- CRC-8 数据校验
- 工作电压: 1.08V ~ 3.6V
- 超低功耗: 典型 0.4μA (待机)

### 与 AHT30 对比

| 特性 | SHT40 | AHT30 |
|---|---|---|
| 温度精度 | ±0.2°C | ±0.3°C |
| 湿度精度 | ±1.8%RH | ±2%RH |
| 测量时间 | 1.7~8.2ms | 80ms |
| 功耗 | 更低 | 较高 |
| 加热器 | 有 | 无 |
| CRC 校验 | 有 | 无 |
| 价格 | 较高 | 较低 |

## 硬件连接

SHT40 通过 I2C0 总线连接到 nRF52832：

| SHT40 引脚 | nRF52832 引脚 | 说明 |
|---|---|---|
| VDD | 3.3V | 电源 (1.08V ~ 3.6V) |
| GND | GND | 地 |
| SCL | P0.6 | I2C 时钟线 |
| SDA | P0.7 | I2C 数据线 |
| ADDR | GND 或 VDD | 地址选择 (GND=0x44, VDD=0x45) |

注意：
- SDA/SCL 需要 4.7kΩ 上拉电阻
- ADDR 引脚决定 I2C 地址，通常接 GND (0x44)

## 软件集成

### 1. 文件结构

```
src/sensors/
├── sht40.h              # 驱动头文件
├── sht40.c              # 驱动实现
└── sht40_example.c      # 使用示例
```

### 2. 在 CMakeLists.txt 中添加源文件

```cmake
target_sources(app PRIVATE
    src/sensors/sht40.c
    # 如果需要示例代码
    # src/sensors/sht40_example.c
)
```

### 3. 在 prj.conf 中启用 I2C

```ini
# I2C 配置
CONFIG_I2C=y
```

### 4. 在 overlay 文件中配置 I2C

确保 `app.overlay` 或对应的板级 overlay 文件中已配置 I2C0：

```dts
&i2c0 {
    compatible = "nordic,nrf-twi";
    status = "okay";
    clock-frequency = <I2C_BITRATE_STANDARD>; /* 100kHz */
    
    pinctrl-0 = <&i2c0_default>;
    pinctrl-1 = <&i2c0_sleep>;
    pinctrl-names = "default", "sleep";
};
```

## API 使用说明

### 初始化

```c
#include "sht40.h"

const struct device *i2c_dev = DEVICE_DT_GET(DT_NODELABEL(i2c0));

// 使用默认地址 0x44 (ADDR 接地)
int ret = sht40_init(i2c_dev, SHT40_I2C_ADDR_A);
if (ret != 0) {
    printk("SHT40 初始化失败: %d\n", ret);
}

// 或使用地址 0x45 (ADDR 接 VDD)
// int ret = sht40_init(i2c_dev, SHT40_I2C_ADDR_B);
```

### 读取温湿度数据

```c
int32_t temperature, humidity;

// 高精度模式 (±0.2°C, ±1.8%RH, 8.2ms)
int ret = sht40_read(&temperature, &humidity, SHT40_PRECISION_HIGH);
if (ret == 0) {
    printk("温度: %d.%02d °C\n", temperature / 100, abs(temperature % 100));
    printk("湿度: %d.%02d %%RH\n", humidity / 100, humidity % 100);
}
```

### 精度模式选择

```c
// 高精度模式 (±0.2°C, ±1.8%RH, 8.2ms) - 推荐用于精确测量
sht40_read(&temp, &humi, SHT40_PRECISION_HIGH);

// 中精度模式 (±0.3°C, ±2.5%RH, 4.5ms) - 平衡精度和速度
sht40_read(&temp, &humi, SHT40_PRECISION_MED);

// 低精度模式 (±0.4°C, ±3.5%RH, 1.7ms) - 快速测量，低功耗
sht40_read(&temp, &humi, SHT40_PRECISION_LOW);
```

### 使用加热器功能

加热器可以去除传感器表面的冷凝水，提高测量准确性。适用于高湿度环境或传感器表面有水汽时。

```c
int32_t temperature, humidity;

// 使用 200mW 加热器，持续 1 秒
int ret = sht40_read_with_heater(&temperature, &humidity, 
                                 SHT40_HEATER_200MW_1S);
if (ret == 0) {
    printk("加热后温度: %d.%02d °C\n", temperature / 100, abs(temperature % 100));
    printk("加热后湿度: %d.%02d %%RH\n", humidity / 100, humidity % 100);
}
```

加热器选项：
- `SHT40_HEATER_200MW_1S`: 200mW, 1 秒 (强力去湿)
- `SHT40_HEATER_200MW_0_1S`: 200mW, 0.1 秒 (快速去湿)
- `SHT40_HEATER_110MW_1S`: 110mW, 1 秒 (中等去湿)
- `SHT40_HEATER_110MW_0_1S`: 110mW, 0.1 秒
- `SHT40_HEATER_20MW_1S`: 20mW, 1 秒 (轻度去湿)
- `SHT40_HEATER_20MW_0_1S`: 20mW, 0.1 秒

注意：频繁使用加热器会缩短传感器寿命，建议仅在必要时使用。

### 读取序列号

每个 SHT40 都有唯一的 32 位序列号，可用于设备识别和追溯。

```c
uint32_t serial;
int ret = sht40_read_serial(&serial);
if (ret == 0) {
    printk("传感器序列号: 0x%08X\n", serial);
}
```

### 软复位

```c
// 软复位传感器（恢复到默认状态）
sht40_soft_reset();
```

## 完整示例

```c
#include "sht40.h"
#include <zephyr/kernel.h>
#include <zephyr/device.h>

void main(void)
{
    const struct device *i2c_dev;
    int32_t temperature, humidity;
    uint32_t serial;
    int ret;

    // 获取 I2C 设备
    i2c_dev = DEVICE_DT_GET(DT_NODELABEL(i2c0));
    if (!device_is_ready(i2c_dev)) {
        printk("I2C 设备未就绪\n");
        return;
    }

    // 初始化 SHT40
    ret = sht40_init(i2c_dev, SHT40_I2C_ADDR_A);
    if (ret != 0) {
        printk("初始化失败\n");
        return;
    }

    // 读取序列号
    ret = sht40_read_serial(&serial);
    if (ret == 0) {
        printk("序列号: 0x%08X\n", serial);
    }

    // 循环读取温湿度
    while (1) {
        ret = sht40_read(&temperature, &humidity, SHT40_PRECISION_HIGH);
        if (ret == 0) {
            printk("温度: %d.%02d °C, 湿度: %d.%02d %%RH\n",
                   temperature / 100, abs(temperature % 100),
                   humidity / 100, humidity % 100);
        }

        k_msleep(2000);  // 2 秒间隔
    }
}
```

## 应用场景

### 1. 高精度环境监测

```c
// 使用高精度模式，适合实验室、医疗等场景
sht40_read(&temp, &humi, SHT40_PRECISION_HIGH);
```

### 2. 低功耗应用

```c
// 使用低精度模式 + 长采样间隔
sht40_read(&temp, &humi, SHT40_PRECISION_LOW);
k_msleep(60000);  // 60 秒采样一次
```

### 3. 高湿度环境

```c
// 定期使用加热器去除冷凝
if (humidity > 9000) {  // 湿度 > 90%
    sht40_read_with_heater(&temp, &humi, SHT40_HEATER_200MW_0_1S);
} else {
    sht40_read(&temp, &humi, SHT40_PRECISION_HIGH);
}
```

### 4. 快速响应

```c
// 使用低精度模式，1.7ms 快速测量
while (1) {
    sht40_read(&temp, &humi, SHT40_PRECISION_LOW);
    k_msleep(100);  // 100ms 采样间隔
}
```

## 功耗优化

### 典型功耗

- 待机: 0.4μA
- 测量 (高精度): 平均 0.8μA @ 1 次/秒
- 测量 (低精度): 平均 0.3μA @ 1 次/秒
- 加热器 (200mW): 约 60mA @ 3.3V

### 优化建议

1. 使用低精度模式
2. 延长采样间隔
3. 避免频繁使用加热器
4. 测量完成后传感器自动进入待机模式

```c
// 低功耗配置示例
void low_power_sampling(void)
{
    int32_t temp, humi;
    
    // 每 60 秒采样一次，使用低精度模式
    while (1) {
        sht40_read(&temp, &humi, SHT40_PRECISION_LOW);
        // 处理数据...
        k_msleep(60000);  // 60 秒
    }
}
```

## 注意事项

### 1. CRC 校验

SHT40 驱动自动进行 CRC-8 校验，确保数据完整性。如果校验失败，`sht40_read()` 会返回 `-EIO` 错误。

### 2. 测量时间

不同精度模式的测量时间：
- 高精度: 8.2ms
- 中精度: 4.5ms
- 低精度: 1.7ms

驱动会自动等待测量完成，无需手动延时。

### 3. 加热器使用

- 加热器会提高温度读数（约 +2~5°C）
- 加热器会降低湿度读数
- 建议仅在高湿度环境下使用
- 频繁使用会缩短传感器寿命

### 4. I2C 地址

- 默认地址 0x44 (ADDR 接地)
- 备用地址 0x45 (ADDR 接 VDD)
- 同一总线上可连接两个 SHT40

### 5. 温度范围

- 工作范围: -40°C ~ +125°C
- 精度保证范围: 0°C ~ +65°C
- 超出范围精度会下降

### 6. 湿度范围

- 测量范围: 0% ~ 100% RH
- 精度保证范围: 10% ~ 90% RH
- 驱动会自动限制输出在 0~100% 范围内

## 故障排查

### 传感器无响应

1. 检查 I2C 连接和地址
2. 确认电源供电正常 (1.08V ~ 3.6V)
3. 检查上拉电阻 (4.7kΩ)
4. 尝试软复位: `sht40_soft_reset()`

### CRC 校验失败

1. 检查 I2C 信号质量
2. 降低 I2C 时钟频率 (100kHz)
3. 检查电源稳定性
4. 缩短 I2C 线缆长度

### 读数异常

1. 等待传感器稳定 (上电后 1ms)
2. 检查环境温湿度是否在正常范围
3. 尝试使用加热器去除冷凝
4. 软复位后重新测量

### 湿度读数偏高

1. 传感器表面可能有冷凝水
2. 使用加热器功能: `sht40_read_with_heater()`
3. 等待传感器干燥后再测量

## 与 AHT30 迁移

如果你的项目使用 AHT30，迁移到 SHT40 非常简单：

```c
// AHT30 代码
aht30_init(i2c_dev);
aht30_read(&temp, &humi);

// 迁移到 SHT40
sht40_init(i2c_dev, SHT40_I2C_ADDR_A);
sht40_read(&temp, &humi, SHT40_PRECISION_HIGH);
```

主要区别：
1. SHT40 需要指定 I2C 地址
2. SHT40 需要选择精度模式
3. SHT40 测量速度更快 (8.2ms vs 80ms)
4. SHT40 有 CRC 校验，更可靠

## 参考资料

- [SHT40 数据手册](https://sensirion.com/media/documents/33FD6951/624C4357/Datasheet_SHT4x.pdf)
- [应用笔记: 处理和组装指南](https://sensirion.com/media/documents/2B6FC1F3/6166E1F1/Sensirion_Handling_and_Assembly_Instructions_SHT4x.pdf)

## 版本历史

- v1.0 (2026-02-14): 初始版本
  - 支持三种精度模式
  - 支持加热器功能
  - CRC-8 数据校验
  - 序列号读取

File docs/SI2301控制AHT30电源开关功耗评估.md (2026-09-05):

# SI2301 控制 AHT30 电源开关功耗评估

## 概述

本文档详细评估使用 SI2301（P 沟道 MOSFET）控制 AHT30 温湿度传感器电源开关的功耗节省效果，包括理论计算、实际场景分析和实施建议。

---

## 一、器件参数

### 1.1 AHT30 温湿度传感器

| 参数 | 数值 | 说明 |
|---|---|---|
| **工作电压** | 2.2 V - 5.5 V | 典型 3.3 V |
| **测量电流** | 0.57-0.60 mA | 测量状态（典型值） |
| **待机电流** | 10-20 μA | 不断电时的待机电流 |
| **测量时间** | 80-100 ms | 包括唤醒、测量、I2C 通信 |
| **I2C 地址** | 0x38 | 固定地址 |

**数据来源：** AHT30 数据手册

### 1.2 SI2301 P-MOSFET

| 参数 | 数值 | 说明 |
|---|---|---|
| **封装** | SOT-23 | 小型封装 |
| **类型** | P 沟道 MOSFET | 适合高侧开关 |
| **导通电阻 RDS(on)** | 120-150 mΩ | V_GS = -4.5V 时约 120 mΩ |
| **漏电流（关断）** | < 1 μA | 关断状态漏电流 |
| **栅极阈值电压** | -0.5 V ~ -1.5 V | 典型 -1.0 V |
| **最大漏源电压** | -20 V | 反向电压 |

**数据来源：** SI2301 数据手册

### 1.3 系统参数

| 参数 | 数值 | 说明 |
|---|---|---|
| **系统电压** | 3.3 V | 典型工作电压 |
| **当前采集间隔** | 1-3600 秒 | 可配置（默认 1 秒） |
| **测量持续时间** | 80-100 ms | 单次测量时间 |

---

## 二、功耗分析

### 2.1 当前方案（无电源开关）

**AHT30 始终供电：**

| 状态 | 电流 | 时间占比 | 平均电流 |
|---|---|---|---|
| **测量状态** | 0.60 mA | 0.1 s / T | 0.60 mA × (0.1 / T) |
| **待机状态** | 0.015 mA | (T - 0.1) / T | 0.015 mA × ((T - 0.1) / T) |
| **总平均电流** | - | - | **0.60 × (0.1/T) + 0.015 × ((T-0.1)/T) mA** |

**简化计算（T >> 0.1 s）：**

\[
I_{avg,no\_switch} \approx 0.015 + \frac{0.06}{T} \text{ mA}
\]

其中 T 为采集间隔（秒）。

### 2.2 使用 SI2301 控制方案

**AHT30 仅在测量时供电：**

| 状态 | 电流 | 时间占比 | 说明 |
|---|---|---|---|
| **测量状态** | 0.60 mA | 0.1 s / T | AHT30 工作电流 |
| **关断状态** | 0.001 mA | (T - 0.1) / T | SI2301 漏电流 |
| **总平均电流** | - | - | **0.60 × (0.1/T) + 0.001 × ((T-0.1)/T) mA** |

**简化计算（T >> 0.1 s）：**

\[
I_{avg,with\_switch} \approx 0.001 + \frac{0.06}{T} \text{ mA}
\]

**SI2301 导通损耗：**

- 导通电阻：RDS(on) = 0.12 Ω
- 测量电流：I = 0.60 mA
- 压降：V_drop = I × R = 0.60 mA × 0.12 Ω = 0.072 mV
- 功率损耗：P_loss = V_drop × I = 0.043 μW

**结论：** SI2301 导通损耗极小，可忽略不计。

---

## 三、功耗节省计算

### 3.1 不同采集间隔的功耗对比

#### 公式推导

**无开关方案平均电流：**
\[
I_{no} = 0.015 + \frac{0.06}{T} \text{ mA}
\]

**有开关方案平均电流：**
\[
I_{yes} = 0.001 + \frac{0.06}{T} \text{ mA}
\]

**节省电流：**
\[
\Delta I = I_{no} - I_{yes} = 0.015 - 0.001 = 0.014 \text{ mA} = 14 \text{ μA}
\]

**节省功率（3.3V 系统）：**
\[
\Delta P = \Delta I \times V = 14 \text{ μA} \times 3.3 \text{ V} = 46.2 \text{ μW}
\]

#### 不同采集间隔的详细对比

| 采集间隔 T | 无开关平均电流 | 有开关平均电流 | 节省电流 | 节省功率 | 节省比例 |
|---|---|---|---|---|---|
| **1 秒** | 0.075 mA | 0.061 mA | **0.014 mA** | **46.2 μW** | **18.7%** |
| **10 秒** | 0.021 mA | 0.007 mA | **0.014 mA** | **46.2 μW** | **66.7%** |
| **60 秒** | 0.016 mA | 0.002 mA | **0.014 mA** | **46.2 μW** | **87.5%** |
| **300 秒（5分钟）** | 0.0152 mA | 0.0012 mA | **0.014 mA** | **46.2 μW** | **92.1%** |
| **600 秒（10分钟）** | 0.0151 mA | 0.0011 mA | **0.014 mA** | **46.2 μW** | **92.7%** |
| **3600 秒（1小时）** | 0.01502 mA | 0.00102 mA | **0.014 mA** | **46.2 μW** | **93.2%** |

**说明：**
- 节省电流为**固定值 14 μA**，与采集间隔无关
- 采集间隔越长，节省比例越高（因为待机时间占比增加）
- 在采集间隔 > 60 秒时，节省比例 > 85%

---

### 3.2 能量节省计算

#### 每日节省

**假设采集间隔为 60 秒：**

- 节省电流：14 μA
- 节省功率：46.2 μW
- 每日节省能量：46.2 μW × 24 h = **1.11 mWh/day**

#### 每月节省

- 每月（30 天）节省：1.11 mWh × 30 = **33.3 mWh/month**

#### 电池续航提升

**假设使用 CR2032 电池（220 mAh，3.0 V 平均电压 = 660 mWh）：**

- 当前系统总功耗：假设 5 mA（优化后）
- 当前续航：660 mWh / (5 mA × 3.0 V) = **44 小时**

**使用 SI2301 后：**
- 节省：14 μA
- 新功耗：5 mA - 0.014 mA ≈ 4.986 mA
- 新续航：660 mWh / (4.986 mA × 3.0 V) = **44.1 小时**

**续航提升：约 0.1 小时（6 分钟）**

**结论：** 对于总功耗较大的系统，SI2301 节省的功耗相对较小，续航提升有限。

---

### 3.3 不同系统功耗下的影响

| 系统总功耗 | 节省电流 | 节省比例 | 续航提升（CR2032） |
|---|---|---|---|
| **1 mA** | 14 μA | **1.4%** | 从 220 小时 → 223 小时（+3 小时） |
| **5 mA** | 14 μA | **0.28%** | 从 44 小时 → 44.1 小时（+6 分钟） |
| **10 mA** | 14 μA | **0.14%** | 从 22 小时 → 22.05 小时（+3 分钟） |
| **20 mA** | 14 μA | **0.07%** | 从 11 小时 → 11.02 小时（+1 分钟） |

**结论：**
- 系统功耗越低，SI2301 节省的效果越明显
- 在极致低功耗系统（< 1 mA）中，节省比例可达 1-2%
- 在常规系统（> 5 mA）中，节省比例 < 0.5%

---

## 四、实际场景分析

### 4.1 当前项目场景

**当前配置：**
- 采集间隔：1-3600 秒（可配置，默认 1 秒）
- 系统功耗：约 5-10 mA（优化后）
- 电池：CR2032（220 mAh）

**使用 SI2301 的效果：**

| 采集间隔 | 节省电流 | 续航提升 | 评价 |
|---|---|---|---|
| **1 秒** | 14 μA | +6 分钟 | 效果有限 |
| **60 秒** | 14 μA | +6 分钟 | 效果有限 |
| **300 秒** | 14 μA | +6 分钟 | 效果有限 |

**结论：** 在当前系统功耗水平下，SI2301 节省的功耗相对较小，续航提升有限。

### 4.2 极致低功耗场景

**假设系统功耗优化至 0.5 mA：**

- 节省电流：14 μA
- 节省比例：14 / 500 = **2.8%**
- 续航提升：从 440 小时 → 452 小时（+12 小时）

**结论：** 在极致低功耗系统中，SI2301 的效果更明显。

---

## 五、成本效益分析

### 5.1 硬件成本

| 项目 | 成本 | 说明 |
|---|---|---|
| **SI2301 芯片** | ¥0.1-0.3 | 小批量采购 |
| **PCB 空间** | - | SOT-23 封装，占用小 |
| **设计复杂度** | - | 增加一个 MOSFET 控制电路 |
| **总计** | **¥0.1-0.3** | 单台成本 |

### 5.2 开发成本

| 项目 | 时间 | 说明 |
|---|---|---|
| **原理图设计** | 0.5 小时 | 添加 MOSFET 控制电路 |
| **PCB 设计** | 0.5 小时 | 布局和走线 |
| **代码开发** | 1-2 小时 | GPIO 控制和时序 |
| **测试验证** | 1-2 小时 | 功能测试和功耗测试 |
| **总计** | **3-5 小时** | 开发时间 |

### 5.3 效益评估

**假设年产量 10,000 台：**

- 硬件成本增加：10,000 × ¥0.2 = **¥2,000**
- 开发成本：3-5 小时 × ¥500/小时 = **¥1,500-2,500**
- **总成本：¥3,500-4,500**

**节省效益：**
- 续航提升：约 6 分钟/台（CR2032）
- 电池成本节省：几乎可忽略（6 分钟续航提升）

**投资回收期：** 几乎无法回收（续航提升太小）

**结论：** 仅从电池成本角度，投资回收期很长，不划算。

---

## 六、实施建议

### 6.1 推荐使用 SI2301 的场景

#### ✅ 适合使用的场景

1. **极致低功耗系统（< 1 mA）**
   - 节省比例 > 1%
   - 续航提升明显
   - 值得投入

2. **采集间隔很长（> 300 秒）**
   - 节省比例 > 90%
   - 待机时间占比大
   - 效果明显

3. **对功耗要求极高**
   - 需要每个微安都优化
   - 电池容量受限
   - 续航要求 > 3 个月

4. **已有 PCB 空间**
   - 不影响其他设计
   - 成本增加可接受

#### ❌ 不适合使用的场景

1. **系统功耗较大（> 5 mA）**
   - 节省比例 < 0.5%
   - 续航提升有限
   - 性价比低

2. **采集间隔很短（< 10 秒）**
   - 节省比例 < 70%
   - 效果不明显

3. **成本敏感项目**
   - 需要严格控制 BOM 成本
   - 批量生产
   - 成本增加不可接受

4. **开发时间紧迫**
   - 需要快速上市
   - 无法承担额外开发时间

### 6.2 当前项目建议

**基于当前项目情况：**

- ✅ **系统功耗：** 5-10 mA（优化后）
- ✅ **采集间隔：** 1-3600 秒（可配置）
- ✅ **电池：** CR2032（220 mAh）

**建议：**

1. **如果采集间隔 > 300 秒（5分钟）**
   - 考虑使用 SI2301
   - 节省比例 > 90%
   - 效果相对明显

2. **如果采集间隔 < 60 秒**
   - **不建议使用 SI2301**
   - 节省比例 < 70%
   - 续航提升 < 10 分钟
   - 性价比低

3. **如果系统功耗可优化至 < 1 mA**
   - 强烈建议使用 SI2301
   - 节省比例 > 2%
   - 续航提升明显

---

## 七、技术实施方案

### 7.1 电路设计

#### 原理图

```
VDD (3.3V) ──┬── [SI2301 Source]
             │
             ├── [SI2301 Gate] ── [GPIO] (nRF52810)
             │                    (低电平开启，高电平关闭)
             │
             └── [SI2301 Drain] ── VDD_AHT30 ── AHT30 VDD
                                    │
                                   GND
```

#### 元件选型

| 元件 | 型号 | 说明 |
|---|---|---|
| **MOSFET** | SI2301 | P 沟道，SOT-23 |
| **上拉电阻** | 10 kΩ | Gate 上拉（可选） |
| **去耦电容** | 100 nF | AHT30 电源去耦 |

#### PCB 布局要点

1. **SI2301 位置**
   - 靠近 AHT30
   - 电源走线尽量短
   - 保留地平面

2. **去耦电容**
   - 靠近 AHT30 VDD 引脚
   - 使用 X7R 或 X5R 材质

3. **走线宽度**
   - 电源走线 ≥ 0.3 mm
   - 控制信号走线 ≥ 0.2 mm

### 7.2 软件实现

#### GPIO 控制

```c
// SI2301 控制引脚定义
#define AHT30_POWER_PIN  2  // 使用 P0.2（可根据实际设计调整）
#define AHT30_POWER_PORT NRF_P0

// 开启 AHT30 电源
static void aht30_power_on(void)
{
    // SI2301 是 P 沟道，低电平开启
    AHT30_POWER_PORT->OUTCLR = (1UL << AHT30_POWER_PIN);
    k_msleep(10);  // 等待电源稳定
}

// 关闭 AHT30 电源
static void aht30_power_off(void)
{
    // SI2301 是 P 沟道，高电平关闭
    AHT30_POWER_PORT->OUTSET = (1UL << AHT30_POWER_PIN);
}

// 初始化
static void aht30_power_init(void)
{
    // 配置 GPIO 为输出，初始状态为关闭
    AHT30_POWER_PORT->DIRSET = (1UL << AHT30_POWER_PIN);
    AHT30_POWER_PORT->OUTSET = (1UL << AHT30_POWER_PIN);  // 关闭
}
```

#### 修改读取函数

```c
static int aht30_read(int32_t *temperature, int32_t *humidity)
{
    int ret;
    
    // 开启电源
    aht30_power_on();
    
    // 等待传感器稳定（上电后需要时间）
    k_msleep(100);
    
    // 原有的读取代码...
    // ... (测量命令、读取数据等)
    
    // 读取完成后关闭电源
    aht30_power_off();
    
    return ret;
}
```

#### 初始化函数修改

```c
static int aht30_init(void)
{
    // 初始化电源控制
    aht30_power_init();
    
    // 开启电源
    aht30_power_on();
    
    // 等待传感器稳定
    k_msleep(100);
    
    // 原有的初始化代码...
    // ... (I2C 扫描、校准等)
    
    // 初始化完成后可以关闭电源（如果不需要立即使用）
    // aht30_power_off();
    
    return 0;
}
```

### 7.3 时序要求

#### 上电时序

```
GPIO 拉低 ──┐
            │
            ├── 10 ms ──> 电源稳定
            │
            ├── 100 ms ──> 传感器稳定
            │
            └──> 可以开始 I2C 通信
```

#### 下电时序

```
I2C 通信完成 ──┐
               │
               ├── 立即 ──> GPIO 拉高
               │
               └──> 电源关闭
```

**注意：**
- 上电后需要等待 100 ms 让传感器稳定
- 下电可以立即执行（无需等待）
- 确保 I2C 通信完成后再关闭电源

---

## 八、测试验证

### 8.1 功能测试

1. **电源控制测试**
   - 验证 GPIO 控制正常
   - 验证上电/下电时序正确
   - 验证传感器能正常读取

2. **I2C 通信测试**
   - 验证上电后 I2C 通信正常
   - 验证多次开关电源后仍能正常工作
   - 验证数据读取准确性

### 8.2 功耗测试

#### 测试设备

- **功耗分析仪：** Keysight N6705B 或 Nordic Power Profiler Kit II
- **精度要求：** < 1 μA

#### 测试场景

1. **无开关方案**
   - 测量平均电流
   - 记录不同采集间隔的功耗

2. **有开关方案**
   - 测量平均电流
   - 记录不同采集间隔的功耗
   - 对比节省效果

#### 测试结果记录

| 采集间隔 | 无开关电流 | 有开关电流 | 节省电流 | 节省比例 |
|---|---|---|---|---|
| 1 秒 | - | - | - | - |
| 60 秒 | - | - | - | - |
| 300 秒 | - | - | - | - |

### 8.3 稳定性测试

1. **长期运行测试**
   - 24 小时连续运行
   - 验证电源开关不影响传感器寿命
   - 记录异常情况

2. **温度测试**
   - 不同温度下测试（-20°C ~ +60°C）
   - 验证 MOSFET 工作正常
   - 验证传感器读取正常

---

## 九、结论与建议

### 9.1 功耗节省结论

**使用 SI2301 控制 AHT30 电源开关的功耗节省：**

1. **节省电流：固定 14 μA**（与采集间隔无关）
2. **节省功率：46.2 μW**（3.3V 系统）
3. **节省比例：** 18.7% - 93.2%（取决于采集间隔）
4. **续航提升：** 约 6 分钟（CR2032，系统功耗 5 mA）

### 9.2 综合建议

#### 当前项目（系统功耗 5-10 mA）

**建议：**

1. **如果采集间隔 > 300 秒（5分钟）**
   - ✅ **推荐使用 SI2301**
   - 节省比例 > 90%
   - 效果相对明显

2. **如果采集间隔 < 60 秒**
   - ❌ **不建议使用 SI2301**
   - 节省比例 < 70%
   - 续航提升 < 10 分钟
   - 性价比低

3. **如果系统功耗可优化至 < 1 mA**
   - ✅ **强烈推荐使用 SI2301**
   - 节省比例 > 2%
   - 续航提升明显（> 10 小时）

#### 实施优先级

**优先级排序：**

1. **高优先级：** 软件功耗优化（可节省 4-8 mA）
2. **中优先级：** 外部晶振（可节省 11 μA）
3. **低优先级：** SI2301 电源开关（可节省 14 μA）

**结论：** SI2301 电源开关的功耗节省相对较小，建议在完成其他优化后再考虑。

---

## 十、相关文档

- `docs/功耗优化完整方案.md` - 完整的功耗优化方案
- `docs/可配置采集间隔与低功耗方案.md` - 采集间隔配置方案
- `docs/散片nRF52810-QCAA功耗评估.md` - 散片方案评估

---

## 附录：计算公式汇总

### A. 无开关方案平均电流

\[
I_{no} = I_{idle} + \frac{I_{meas} \times t_{meas}}{T}
\]

其中：
- \(I_{idle} = 0.015 \text{ mA}\)（待机电流）
- \(I_{meas} = 0.60 \text{ mA}\)（测量电流）
- \(t_{meas} = 0.1 \text{ s}\)（测量时间）
- \(T\)（采集间隔，秒）

### B. 有开关方案平均电流

\[
I_{yes} = I_{leak} + \frac{I_{meas} \times t_{meas}}{T}
\]

其中：
- \(I_{leak} = 0.001 \text{ mA}\)（MOSFET 漏电流）
- 其他参数同上

### C. 节省电流

\[
\Delta I = I_{no} - I_{yes} = I_{idle} - I_{leak} = 0.015 - 0.001 = 0.014 \text{ mA}
\]

### D. 节省功率

\[
\Delta P = \Delta I \times V_{sys} = 0.014 \text{ mA} \times 3.3 \text{ V} = 46.2 \text{ μW}
\]

### E. 节省比例

\[
\text{节省比例} = \frac{\Delta I}{I_{no}} \times 100\%
\]

---

**文档版本：** 1.0  
**更新日期：** 2026-01-16  
**适用平台：** nRF52810 (E104-BT5010A) + AHT30  
**作者：** AI Assistant

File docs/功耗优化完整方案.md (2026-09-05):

# 功耗优化完整方案

## 概述

本文档详细列出 nRF52810 (E104-BT5010A) 蓝牙温度计在软件和硬件层面的所有功耗优化方法，帮助实现更长的电池续航时间。

---

## 软件层面优化

### 1. 电源管理（PM）系统 ⭐⭐⭐ 高优先级

**当前状态：** `CONFIG_PM=y` 已启用，但代码中 PM 头文件被注释

**优化措施：**
- ✅ 启用 PM 设备管理：`CONFIG_PM_DEVICE=y`
- ✅ 启用运行时 PM：`CONFIG_PM_DEVICE_RUNTIME=y`
- ✅ 修复代码中的 PM 回调问题（当前被注释）
- ✅ 确保 `k_sleep()` 能正确进入 System ON 睡眠模式

**预期节省：** 约 **3-4 mA**（MCU 进入 System ON 睡眠）

**实现难度：** ⭐⭐ 中等

---

### 2. 蓝牙广播优化 ⭐⭐ 中优先级

**当前状态：** 间歇广播（5秒广播/5秒休眠）

**进一步优化：**
- ✅ 延长休眠时间：广播 5 秒，休眠 15-30 秒
- ✅ 使用更慢的广播间隔：2.56 秒 → 4-5 秒
- ✅ 连接后降低连接间隔：`CONFIG_BT_BUF_EVT_RX_COUNT` 优化
- ✅ 使用定向广播（仅在连接时广播）

**预期节省：** **0.05-0.1 mA**

**实现难度：** ⭐ 简单

---

### 3. UART/串口优化 ⭐⭐⭐ 高优先级

**当前状态：** `CONFIG_SERIAL=y`, `CONFIG_PRINTK=y` 开启

**优化措施：**
- ✅ 生产环境关闭：`CONFIG_SERIAL=n`, `CONFIG_UART_CONSOLE=n`, `CONFIG_PRINTK=n`
- ✅ 或使用条件编译：`#ifdef DEBUG`
- ✅ 使用 RTT 替代 UART（调试时）

**预期节省：** **0.5-1 mA**

**实现难度：** ⭐ 简单

---

### 4. LED 优化 ⭐⭐ 中优先级

**当前状态：** LINK LED 500ms 闪烁，DATA LED 偶尔闪烁

**优化措施：**
- ✅ 未连接时：延长闪烁间隔到 5-10 秒
- ✅ 已连接时：完全关闭 LED
- ✅ 仅在关键事件闪烁（连接成功、错误等）

**预期节省：** **0.5-1 mA**

**实现难度：** ⭐ 简单

---

### 5. 传感器读取优化 ⭐⭐ 中优先级

**当前状态：** 每 1 秒读取一次

**优化措施：**
- ✅ 未连接时：每 60-300 秒读取一次
- ✅ 已连接时：按需读取（手机请求时）
- ✅ 读取后立即关闭 I2C 外设
- ✅ 传感器进入低功耗模式（如果支持）

**预期节省：** **0.1-0.3 mA**

**实现难度：** ⭐⭐ 中等

---

### 6. 主循环优化 ⭐ 低优先级

**当前状态：** `k_sleep(K_SECONDS(10))`

**优化措施：**
- ✅ 增加睡眠时间到 30-60 秒
- ✅ 使用定时器唤醒，避免轮询
- ✅ 确保所有任务完成后才进入睡眠

**预期节省：** **0.5-1 mA**

**实现难度：** ⭐ 简单

---

### 7. Flash 操作优化 ⭐ 低优先级

**当前状态：** 批量写入 Flash

**优化措施：**
- ✅ 减少写入频率：缓冲区满后再写入
- ✅ 使用更高效的 Flash 写入策略
- ✅ 批量写入时关闭其他外设

**预期节省：** **0.05-0.1 mA**

**实现难度：** ⭐⭐ 中等

---

### 8. 外设电源管理 ⭐⭐ 中优先级

**优化措施：**
- ✅ I2C 空闲时关闭：`pm_device_action_run(i2c_dev, PM_DEVICE_ACTION_SUSPEND)`
- ✅ Flash 空闲时关闭
- ✅ GPIO 未使用时设为模拟输入（减少漏电）
- ✅ UART 未使用时关闭

**预期节省：** **0.1-0.2 mA**

**实现难度：** ⭐⭐ 中等

---

### 9. 蓝牙连接参数优化 ⭐⭐ 中优先级

**优化措施：**
```conf
CONFIG_BT_GAP_AUTO_UPDATE_CONN_PARAMS=y
CONFIG_BT_CONN_PARAM_UPDATE_TIMEOUT=5000
```
- ✅ 连接后自动降低连接间隔（如 7.5ms → 30ms）
- ✅ 优化连接超时参数
- ✅ 减少连接事件频率

**预期节省：** **0.2-0.5 mA**

**实现难度：** ⭐⭐ 中等

---

### 10. 代码优化 ⭐ 低优先级

**优化措施：**
- ✅ 减少浮点运算（如果使用）
- ✅ 优化数据结构，减少 RAM 使用
- ✅ 使用 `__attribute__((section(".noinit")))` 保留关键数据
- ✅ 减少不必要的函数调用

**预期节省：** **0.05-0.1 mA**

**实现难度：** ⭐⭐ 中等

---

## 硬件层面优化

### 1. 外部 32.768kHz 晶振 ⭐⭐⭐ 高优先级

**当前状态：** 使用内部 RC 振荡器

**优化措施：**
- ✅ 添加外部 32.768kHz 无源晶振（3225 封装，12.5pF 负载）
- ✅ 推荐型号：FC-135 32.7680KA-A5（10ppm）或 A0（20ppm）
- ✅ 添加负载电容：22pF ±5%, C0G（2 个）

**预期节省：** 约 **11 μA**（消除 RC 校准开销）

**续航提升：** 约 **9 天**

**实现难度：** ⭐⭐⭐ 较难（需要硬件修改）

**详细说明：** 参考 `docs/32.768kHz晶振选型与功耗分析.md`

---

### 2. DCDC 转换器 ⭐⭐⭐ 高优先级

**当前状态：** `CONFIG_BOARD_ENABLE_DCDC=y` 被注释

**优化措施：**
- ✅ 启用 DCDC：`CONFIG_BOARD_ENABLE_DCDC=y`
- ✅ 前提：模块电路需有 DCDC 电感（通常已包含）

**预期节省：** 射频功耗降低约 **40%**（约 **0.5-1 mA**）

**实现难度：** ⭐ 简单（仅需配置）

---

### 3. 负载电容优化 ⭐⭐ 中优先级

**优化措施：**
- ✅ 使用 C0G/NP0 材质（温度稳定性好）
- ✅ 推荐值：22pF ±5%
- ✅ 确保电容精度和温度特性

**预期节省：** 减少晶振驱动功耗

**实现难度：** ⭐⭐ 中等（需要硬件修改）

---

### 4. PCB 布局优化 ⭐ 低优先级

**优化措施：**
- ✅ 晶振靠近 MCU（走线 < 10mm）
- ✅ 晶振下方保留地平面
- ✅ 避免晶振下方走其他信号线
- ✅ 对称布线，等长走线

**预期节省：** 减少干扰，降低功耗

**实现难度：** ⭐⭐⭐ 较难（需要重新设计 PCB）

---

### 5. 上拉/下拉电阻优化 ⭐ 低优先级

**优化措施：**
- ✅ I2C 上拉电阻：使用较大阻值（如 10kΩ 而非 4.7kΩ）
- ✅ 未使用的 GPIO：设为模拟输入或上拉/下拉
- ✅ 减少不必要的上拉电阻

**预期节省：** **0.05-0.1 mA**

**实现难度：** ⭐⭐ 中等（需要硬件修改）

---

### 6. 电源去耦优化 ⭐ 低优先级

**优化措施：**
- ✅ 在 VDD 引脚附近添加 100nF + 10μF 去耦电容
- ✅ 减少电源纹波，降低功耗
- ✅ 确保电容靠近电源引脚

**预期节省：** **0.05-0.1 mA**

**实现难度：** ⭐⭐ 中等（需要硬件修改）

---

### 7. 电池选择 ⭐ 低优先级

**优化措施：**
- ✅ CR2032（220mAh）→ CR2450（550mAh）
- ✅ 或使用可充电电池

**续航提升：** 约 **2.5 倍**

**实现难度：** ⭐ 简单（仅需更换电池）

---

### 8. 传感器电源管理 ⭐ 低优先级

**优化措施：**
- ✅ 如果可能，为 AHT30 添加电源开关
- ✅ 未使用时切断传感器电源
- ✅ 使用低功耗传感器（如果可选）

**预期节省：** **0.05-0.1 mA**

**实现难度：** ⭐⭐⭐ 较难（需要硬件修改）

---

## 优化优先级建议

### 🔴 高优先级（立即实施）

1. **关闭 UART/PRINTK**（节省 0.5-1 mA）
   - 实现时间：5 分钟
   - 影响：失去调试输出（可用 RTT 替代）

2. **优化 LED 闪烁**（节省 0.5-1 mA）
   - 实现时间：10 分钟
   - 影响：用户体验略有下降

3. **修复并启用 PM 系统**（节省 3-4 mA）
   - 实现时间：1-2 小时
   - 影响：需要修复 USAGE FAULT 问题

4. **启用 DCDC**（节省 0.5-1 mA）
   - 实现时间：1 分钟
   - 影响：无（如果硬件支持）

**累计节省：** 约 **4.5-7 mA**

---

### 🟡 中优先级（后续优化）

5. **优化传感器读取间隔**（节省 0.1-0.3 mA）
   - 实现时间：30 分钟
   - 影响：数据更新频率降低

6. **优化蓝牙连接参数**（节省 0.2-0.5 mA）
   - 实现时间：30 分钟
   - 影响：连接响应可能略慢

7. **外设电源管理**（节省 0.1-0.2 mA）
   - 实现时间：1-2 小时
   - 影响：需要仔细测试外设唤醒

**累计节省：** 约 **0.4-1.0 mA**

---

### 🟢 低优先级（长期优化）

8. **添加外部晶振**（节省 11 μA）
   - 实现时间：需要硬件修改
   - 影响：需要重新设计 PCB

9. **PCB 布局优化**
   - 实现时间：需要重新设计
   - 影响：需要重新制板

10. **电池升级**
    - 实现时间：立即
    - 影响：需要更大的电池仓

---

## 预期效果汇总

| 优化项 | 功耗节省 | 累计节省 | 实现难度 | 优先级 |
|---|---|---|---|---|
| 关闭 UART/PRINTK | 0.5-1 mA | 0.5-1 mA | ⭐ 简单 | 🔴 高 |
| 优化 LED | 0.5-1 mA | 1-2 mA | ⭐ 简单 | 🔴 高 |
| 启用 PM 系统 | 3-4 mA | 4-6 mA | ⭐⭐ 中等 | 🔴 高 |
| 启用 DCDC | 0.5-1 mA | 4.5-7 mA | ⭐ 简单 | 🔴 高 |
| 优化传感器读取 | 0.1-0.3 mA | 4.6-7.3 mA | ⭐⭐ 中等 | 🟡 中 |
| 优化蓝牙参数 | 0.2-0.5 mA | 4.8-7.8 mA | ⭐⭐ 中等 | 🟡 中 |
| 外设电源管理 | 0.1-0.2 mA | 4.9-8.0 mA | ⭐⭐ 中等 | 🟡 中 |
| 外部晶振 | 11 μA | 4.9-8.0 mA | ⭐⭐⭐ 较难 | 🟢 低 |
| **总计** | - | **约 5-8 mA** | - | - |

---

## 功耗对比

### 当前状态
- **功耗：** 约 **12-18 mA**
- **续航：** 约 **15 小时**（CR2032, 220mAh）

### 优化后（高优先级）
- **功耗：** 约 **5-11 mA**
- **续航：** 约 **20-44 小时**（1.3-2.9 倍提升）

### 优化后（全部优化）
- **功耗：** 约 **4-10 mA**
- **续航：** 约 **22-55 小时**（1.5-3.7 倍提升）

### 极致优化（含外部晶振）
- **功耗：** 约 **0.1-0.2 mA**（间歇广播模式）
- **续航：** 约 **1100-2200 小时**（73-147 天）

---

## 实施建议

### 第一阶段：快速优化（1-2 小时）
1. ✅ 关闭 UART/PRINTK
2. ✅ 优化 LED 闪烁
3. ✅ 启用 DCDC
4. ✅ 优化主循环睡眠时间

**预期效果：** 功耗从 15 mA 降至 8-10 mA，续航提升至 22-27 小时

---

### 第二阶段：深度优化（2-4 小时）
1. ✅ 修复并启用 PM 系统
2. ✅ 优化传感器读取间隔
3. ✅ 优化蓝牙连接参数
4. ✅ 外设电源管理

**预期效果：** 功耗降至 5-7 mA，续航提升至 31-44 小时

---

### 第三阶段：硬件优化（需要硬件修改）
1. ✅ 添加外部 32.768kHz 晶振
2. ✅ PCB 布局优化
3. ✅ 电池升级

**预期效果：** 功耗降至 0.1-0.2 mA（间歇模式），续航提升至 73-147 天

---

## 注意事项

1. **PM 系统问题：** 当前代码中 PM 被注释，需要修复 USAGE FAULT 问题后才能启用
2. **DCDC 前提：** 需要确认硬件是否支持 DCDC（通常模块已包含）
3. **外部晶振：** 需要重新设计 PCB，成本较高
4. **测试验证：** 每次优化后需要测试功能是否正常

---

## 相关文档

- `docs/功耗评估与优化方案.md` - 基础功耗分析
- `docs/32.768kHz晶振选型与功耗分析.md` - 晶振详细分析
- `docs/开发阶段时钟配置指南.md` - 时钟配置说明

---

**文档版本：** 1.0  
**更新日期：** 2026-01-16  
**适用平台：** nRF52810 (E104-BT5010A)

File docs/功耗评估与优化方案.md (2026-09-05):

# 功耗评估与优化方案

## 1. 当前功耗分析

### 1.1 硬件规格

- **芯片**: nRF52810
- **电池**: CR2032 (3V, 220mAh 典型容量)
- **传感器**: AHT30 温湿度传感器

### 1.2 当前程序功耗来源

| 组件 | 状态 | 功耗估算 | 说明 |
| --- | --- | --- | --- |
| **蓝牙广播**  | 快速广播 (100-150ms) | **5-8 mA** | `BT_LE_ADV_CONN_FAST_1`，功耗最高 |
| **MCU 运行**  | 全速运行 | **4-5 mA** | 主循环每 1 秒唤醒，未进入低功耗 |
| **LED 闪烁**  | 500ms 间隔 | **1-2 mA** | 两个 LED 定期闪烁 |
| **I2C 通信**  | 每 3 秒读取 | **0.5-1 mA** | AHT30 传感器读取 |
| **UART 输出** | 持续打印 | **0.5-1 mA** | 串口输出（可关闭） |
| **其他外设**  | 保持运行 | **0.5-1 mA** | GPIO、时钟等 |
| **总计** | - | **12-18 mA** | 持续运行 |

### 1.3 电池续航计算

#### 当前功耗模式

- **平均功耗**: 15 mA (保守估算)
- **电池容量**: 220 mAh
- **续航时间**: 220 mAh ÷ 15 mA = **14.7 小时** ≈ **15 小时**

**结论**: 使用 CR2032 电池，当前程序只能运行约 **15 小时**，不适合长期使用。

---

## 2. nRF52810 功耗特性

### 2.1 不同工作模式功耗

| 模式 | 功耗 | 说明 |
| --- | --- | --- |
| **运行模式** | 4-5 mA | CPU 全速运行 |
| **System ON (浅度睡眠)**  | 1-2 μA | 保持 RAM，可被中断唤醒 |
| **System OFF (深度睡眠)** | 0.4-1.5 μA | 最低功耗，RAM 丢失 |
| **蓝牙广播 (慢速)** | 0.1-0.3 mA | 间隔 1-2 秒 |
| **蓝牙广播 (快速)** | 5-8 mA | 间隔 100-150ms |
| **蓝牙连接** | 0.5-2 mA | 取决于连接间隔 |

### 2.2 优化目标

理想情况下，使用低功耗模式可以实现：

- **未连接时**: 0.5-1 mA (慢速广播 + 浅度睡眠)
- **已连接时**: 1-2 mA (连接模式 + 浅度睡眠)
- **深度睡眠**: 0.4-1.5 μA (仅在不需要蓝牙时)

---

## 3. 优化方案

### 3.1 方案一：基础低功耗优化（推荐）

**目标功耗**: 1-2 mA，续航 **110-220 小时** (4.5-9 天)

#### 优化措施

1. **启用 Zephyr 电源管理**

   ```conf
   CONFIG_PM=y
   CONFIG_PM_DEVICE=y
   ```

2. **优化蓝牙广播间隔**

   - 从快速广播改为慢速广播
   - `BT_LE_ADV_CONN_SLOW_1`: 间隔 1-2 秒
   - 功耗降低: 5-8 mA → 0.1-0.3 mA

3. **减少 LED 闪烁频率**

   - 未连接时: 2-5 秒闪烁一次
   - 已连接时: 关闭 LED 或极慢闪烁

4. **优化主循环**

   - 使用 `k_sleep()` 进入系统低功耗模式
   - 增加睡眠时间到 3-5 秒
   - 传感器读取间隔改为 30-60 秒

5. **关闭 UART 输出（可选）**
   - 生产环境关闭 `CONFIG_PRINTK=n`
   - 或使用条件编译控制输出

#### 预期效果

- **功耗**: 1-2 mA
- **续航**: 110-220 小时 (4.5-9 天)
- **实现难度**: ⭐⭐ (简单)

---

### 3.2 方案二：深度低功耗优化

**目标功耗**: 0.5-1 mA，续航 **220-440 小时** (9-18 天)

#### 优化措施

在方案一基础上，增加：

1. **智能广播策略**

   - 前 30 秒: 快速广播（便于发现）
   - 之后: 慢速广播（降低功耗）
   - 或使用定向广播（仅连接时广播）

2. **传感器读取优化**

   - 仅在需要时读取（连接时或定时）
   - 未连接时: 每 5-10 分钟读取一次
   - 已连接时: 按需读取（手机请求时）

3. **LED 完全关闭**

   - 仅在关键事件时短暂闪烁（如连接成功）
   - 其他时间完全关闭

4. **外设电源管理**
   - I2C 总线在空闲时关闭
   - 传感器可进入低功耗模式（如果支持）

#### 预期效果

- **功耗**: 0.5-1 mA
- **续航**: 220-440 小时 (9-18 天)
- **实现难度**: ⭐⭐⭐ (中等)

---

### 3.3 方案三：极致低功耗（不推荐）

**目标功耗**: 0.1-0.5 mA，续航 **440-2200 小时** (18-91 天)

#### 优化措施

1. **间歇广播模式**

   - 广播 10 秒，休眠 50 秒
   - 使用定时器唤醒

2. **传感器休眠**

   - 仅在需要时唤醒传感器
   - 使用外部中断触发

3. **System OFF 模式**
   - 在不需要蓝牙时进入深度睡眠
   - 使用 RTC 定时唤醒

**注意**: 此方案会严重影响用户体验（连接困难），不推荐用于需要频繁连接的应用。

---

## 4. 推荐实施方案

### 4.1 阶段一：快速优化（立即实施）

**预计功耗**: 2-3 mA，续航 **73-110 小时** (3-4.5 天)

1. ✅ 启用电源管理
2. ✅ 改为慢速蓝牙广播
3. ✅ 减少 LED 闪烁频率
4. ✅ 增加主循环睡眠时间

**实现时间**: 1-2 小时

### 4.2 阶段二：深度优化（后续优化）

**预计功耗**: 1-1.5 mA，续航 **147-220 小时** (6-9 天)

1. ✅ 智能广播策略
2. ✅ 传感器读取优化
3. ✅ LED 完全关闭
4. ✅ 外设电源管理

**实现时间**: 2-4 小时

---

## 5. 功耗优化代码实现要点

### 5.1 启用电源管理

```conf
# prj.conf
CONFIG_PM=y
CONFIG_PM_DEVICE=y
CONFIG_PM_DEVICE_RUNTIME=y
```

### 5.2 优化蓝牙广播

```c
// 改为慢速广播
bt_le_adv_start(BT_LE_ADV_CONN_SLOW_1, ad, ARRAY_SIZE(ad), NULL, 0);
```

### 5.3 优化主循环

```c
// 增加睡眠时间，让系统进入低功耗
k_sleep(K_SECONDS(5));  // 5秒间隔
```

### 5.4 LED 优化

```c
// 未连接时：5秒闪烁一次
#define LINK_BLINK_MS      5000  // 改为5秒

// 已连接时：完全关闭LED
if (bt_connected) {
    LED_PORT->OUTSET = LINK_LED_MASK;  // 关闭LED
}
```

### 5.5 传感器读取优化

```c
// 未连接时：每60秒读取一次
// 已连接时：每10秒读取一次
#define SAMPLE_INTERVAL_DISCONNECTED  60  // 秒
#define SAMPLE_INTERVAL_CONNECTED     10  // 秒
```

---

## 6. 功耗测试建议

### 6.1 测试方法

1. **使用电流表测量**

   - 在电池和模块之间串联电流表
   - 记录不同状态下的电流值

2. **使用 Nordic Power Profiler**

   - 使用 Nordic 官方工具进行精确测量
   - 可以查看实时功耗曲线

3. **理论计算验证**
   - 根据代码逻辑计算平均功耗
   - 与实际测量值对比

### 6.2 测试场景

| 场景 | 测试项 |
| --- | --- |
| **初始化** | 启动功耗、初始化时间 |
| **广播中** | 慢速/快速广播功耗 |
| **已连接** | 连接状态功耗 |
| **数据读取** | 传感器读取功耗 |
| **LED 闪烁** | LED 功耗影响 |

---

## 7. 总结

### 7.1 当前状态

- **功耗**: 12-18 mA
- **续航**: 约 15 小时
- **评价**: ❌ 不适合电池供电

### 7.2 优化后（方案一）

- **功耗**: 1-2 mA
- **续航**: 110-220 小时 (4.5-9 天)
- **评价**: ✅ 基本满足需求

### 7.3 优化后（方案二）

- **功耗**: 0.5-1 mA
- **续航**: 220-440 小时 (9-18 天)
- **评价**: ✅✅ 理想状态

### 7.4 建议

1. **立即实施**: 方案一的基础优化（快速见效）
2. **后续优化**: 根据实际需求实施方案二
3. **长期考虑**: 如果续航仍不足，考虑使用更大容量电池（如 CR2450: 550mAh）

---

_文档版本: 1.0_  
_更新日期: 2026-01-13_

---

AI 追加方案

你这份功耗分析非常专业，它清晰地展示了为什么你的设备现在只能撑 **15 小时**：因为你的芯片目前处于“**全速奔跑**”状态，而真正的低功耗产品大部分时间应该在“**深度睡眠**”。

要达到你预期的 **30 天甚至一年**，关键不在于电池的大小，而在于**占空比（Duty Cycle）**。也就是说，我们要让芯片 99.9% 的时间都在睡觉，只有 0.1% 的时间出来干活。

以下是实现“一年续航”的三个核心武器：

---

### 1. 消除“隐形”的功耗大户（必做）

在你的表格中，有几项功耗在低功耗设计中是不允许存在的：

- **UART 串口 (0.5-1 mA)**：串口驱动开启后，底板上的 CP2102 芯片和 MCU 的 UART 模块会一直耗电。
- **做法**：在正式版本中完全关闭 `CONFIG_SERIAL`。调试时使用 RTT 或仅在必要时开启。

- **LED 闪烁 (1-2 mA)**：对于电池产品，LED 是奢侈品。
- **做法**：取消循环闪烁。改为“按键后闪一下”或“连接成功闪三下”，平时保持熄灭。

- **MCU 全速运行 (4-5 mA)**：这是最大的问题。
- **做法**：必须确保进入 `System ON` 睡眠模式。在 Zephyr 中，只要没有线程在忙，`k_sleep()` 会自动让内核进入低功耗。

---

### 2. 核心参数：如何撑到 1 年？

要撑到一年（约 8760 小时），对于 220mAh 的电池，**平均电流必须控制在 （微安）以下**。

#### 优化后的功耗模型表

| 动作 | 持续电流 | 持续时间 | 频率 | 平均电流贡献 |
| --- | --- | --- | --- | --- |
| **深度睡眠 (System ON)** | \*\*\*\* | 一直保持 | 持续 | \*\*\*\* |
| **蓝牙广播 (慢速)** | (峰值) | | 每 2 秒一次  | \*\*\*\* |
| **传感器读取 (AHT30)** | | | 每 60 秒一次 | \*\*\*\* |
| **总计平均电流** | - | - | - | \*\*\*\* |

**计算结论**： 小时 **377 天**。

---

### 3. 实现“一年续航”的代码级改动

#### A. 广播策略（最关键）

不要一直快速广播。使用“阶梯式广播”：

```c
// 初始 30 秒快速广播，方便用户连接
bt_le_adv_start(BT_LE_ADV_CONN_FAST_1, ad, ARRAY_SIZE(ad), NULL, 0);

// 30 秒后切换到极慢广播（比如 2.5 秒一次）
// 这可以让芯片在两次广播之间睡得很死
k_sleep(K_SECONDS(30));
bt_le_adv_stop();
bt_le_adv_start(BT_LE_ADV_PARAM(BT_LE_ADV_OPT_CONNECTABLE, 4000, 4001, NULL), ad, ARRAY_SIZE(ad), NULL, 0);

```

#### B. 硬件配置 (prj.conf)

必须关闭掉所有不必要的外设硬件时钟：

```text
# 核心低功耗开关
CONFIG_PM=y
CONFIG_SERIAL=n
CONFIG_UART_CONSOLE=n
CONFIG_CONSOLE=n

# 禁用浮点运算以减少寄存器保护功耗（如果没用到复杂计算）
CONFIG_FPU=n

# 确保使用内部低速时钟，避免外部晶振一直起振
CONFIG_CLOCK_CONTROL_NRF_K32SRC_RC=y

```

#### C. DCDC 转换器（硬件加速）

nRF52810 内部有一个高效的 DCDC。开启它可以将射频电流降低约 40%。
**前提条件**：你的亿佰特模块电路必须焊了 DCDC 所需的电感（通常模块内部已带）。

```text
CONFIG_BOARD_ENABLE_DCDC=y

```

---

### 4. 针对 AHT30 的优化

AHT30 在非测量时间会自动进入休眠，但 I2C 总线本身会有漏电。

- **做法**：在读取完传感器后，可以考虑关闭 I2C 控制器，或者将 SDA/SCL 引脚设为模拟输入模式以防漏电。

---

### 5. 关于 AHT30 传感器的连接

既然你问到之前的电路设计：

1. **物理引脚**：在 E104-BT5010A 的典型设计中，**P0.26 (SDA)** 和 **P0.27 (SCL)** 是最标准的 I2C 选型。
2. **上拉电阻**：如果你的底板没有焊接 的上拉电阻，I2C 即使代码对了也通不了。请确认你的 AHT30 模块上是否自带了电阻。

### 💡 我的建议下一步：

你现在的功耗分析非常棒。**你想让我帮你写一段针对“方案二”级别的、带低功耗逻辑的 `main.c` 吗？** 我们可以把广播设慢，并把 LED 彻底关掉，看看你的串口打印（如果还开着的话）是不是依然能出来数据。

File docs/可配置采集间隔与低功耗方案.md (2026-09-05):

# 可配置采集间隔与低功耗优化方案

## 1. 方案概述

### 1.1 需求

- **手机可配置采集间隔**: 通过蓝牙 GATT 服务，手机可以动态修改温湿度记录时间间隔（例如：10 秒、30 秒、60 秒、300 秒等）
- **低功耗优化**: 在采集间隔期间，系统进入深度睡眠模式，大幅降低功耗
- **目标续航**: 从当前的 15 小时提升到 **30-90 天**（取决于采集间隔）

### 1.2 硬件平台

- **芯片**: nRF52810
- **模块**: E104-BT5010A
- **传感器**: AHT30 温湿度传感器
- **SDK**: ncs 3.2.1
- **电池**: CR2032 (220mAh)

---

## 2. 系统架构设计

### 2.1 整体架构图

```
┌─────────────────────────────────────────────────────────────┐
│                    E104-BT5010A 设备                        │
├─────────────────────────────────────────────────────────────┤
│  状态机:                                                    │
│  ┌──────────┐    ┌──────────┐    ┌──────────┐            │
│  │ 深度睡眠  │───>│ 定时唤醒  │───>│ 采集数据  │            │
│  │ (低功耗)  │    │ (RTC)    │    │ (AHT30)  │            │
│  └──────────┘    └──────────┘    └──────────┘            │
│       ▲                │                │                 │
│       └────────────────┴────────────────┘                 │
│                   采集间隔可配置                            │
├─────────────────────────────────────────────────────────────┤
│  蓝牙 GATT 服务:                                            │
│  ├── 配置服务 (UUID: 12340020-...)                        │
│  │   ├── 采集间隔特性 (可读/可写)                          │
│  │   └── 当前状态特性 (可读/可通知)                        │
│  ├── 数据服务 (UUID: 12340001-...)                        │
│  │   ├── 温度特性 (可读/可通知)                            │
│  │   ├── 湿度特性 (可读/可通知)                            │
│  │   └── 历史数据特性 (可读/可通知)                        │
│  └── 时间同步服务 (UUID: 12340010-...)                    │
│      └── 时间特性 (可写)                                   │
└─────────────────────────────────────────────────────────────┘
```

### 2.2 工作流程

```
┌─────────────────────────────────────────────────────────────┐
│  启动/初始化                                                 │
│  ├── 初始化蓝牙、传感器、定时器                              │
│  └── 读取配置（Flash 或默认值）                            │
└─────────────────────────────────────────────────────────────┘
                    │
                    ▼
┌─────────────────────────────────────────────────────────────┐
│  主循环                                                      │
│  ├── 采集温湿度数据                                          │
│  ├── 存储到环形缓冲区                                        │
│  ├── 更新 GATT 特性值                                        │
│  ├── 发送通知（如果已连接）                                  │
│  └── 计算下次唤醒时间                                        │
└─────────────────────────────────────────────────────────────┘
                    │
                    ▼
┌─────────────────────────────────────────────────────────────┐
│  进入低功耗模式                                              │
│  ├── 关闭不必要外设                                          │
│  ├── 配置 RTC 定时器（采集间隔）                            │
│  └── 进入 System ON 睡眠模式                                │
└─────────────────────────────────────────────────────────────┘
                    │
                    ▼
┌─────────────────────────────────────────────────────────────┐
│  RTC 定时器唤醒                                              │
│  └── 唤醒后返回主循环                                        │
└─────────────────────────────────────────────────────────────┘
```

---

## 3. GATT 服务设计

### 3.1 配置服务（新增）

| 项目 | UUID | 说明 |
| --- | --- | --- |
| **服务** | `12340020-1234-5678-1234-56789ABCDEF0` | 配置服务 |
| **采集间隔特性** | `12340021-1234-5678-1234-56789ABCDEF0` | 可读/可写，单位：秒 |
| **当前状态特性** | `12340022-1234-5678-1234-56789ABCDEF0` | 可读/可通知，包含：采集间隔、记录数、系统状态 |

#### 采集间隔特性

- **数据类型**: `uint16_t` (2 bytes)
- **单位**: 秒
- **范围**: 10 ~ 3600 秒（10 秒 ~ 1 小时）
- **默认值**: 30 秒
- **权限**: Read + Write
- **写入后**: 立即生效，更新 RTC 定时器

#### 当前状态特性

- **数据格式**:
  ```
  ┌──────────┬──────────┬──────────┬──────────┐
  │ 采集间隔  │ 记录数   │ 系统状态 │ 保留     │
  │ 2 bytes  │ 2 bytes  │ 1 byte   │ 1 byte   │
  └──────────┴──────────┴──────────┴──────────┘
  总计: 6 bytes
  ```
- **权限**: Read + Notify
- **通知触发**: 采集间隔改变、记录数变化、系统状态变化

### 3.2 数据服务（已有，需扩展）

保持现有的温湿度服务，添加历史数据读取功能。

---

## 4. 低功耗实现方案

### 4.1 功耗优化策略

| 优化项 | 当前状态 | 优化后 | 功耗降低 |
| --- | --- | --- | --- |
| **主循环睡眠** | 1 秒唤醒 | 按采集间隔（10-3600 秒） | **99%+** |
| **蓝牙广播** | 快速广播 (100ms) | 慢速广播 (2-5 秒) | **80-90%** |

| **I2C 总线** | 保持激活 | 读取后关闭 | **10-20%** |
| **MCU 模式** | 全速运行 | System ON 睡眠 | **99%+** |

目前开发环境，不需要，正式时候才屏蔽
| **LED 闪烁** | 持续闪烁 | 仅关键事件闪烁 | **90%+** |
| **UART 输出** | 持续打印 | 关闭或条件编译 | **50-100%** |

### 4.2 睡眠模式选择

#### System ON 模式（推荐）

- **功耗**: 1-2 μA（睡眠时）
- **唤醒方式**: RTC 定时器、蓝牙中断
- **RAM 保持**: ✓（数据不丢失）
- **唤醒时间**: < 1ms
- **适用场景**: 需要保持蓝牙连接、需要快速响应

#### System OFF 模式（不推荐）

- **功耗**: 0.4-1.5 μA（最低）
- **唤醒方式**: 仅外部中断（蓝牙无法唤醒）
- **RAM 保持**: ✗（数据丢失）
- **唤醒时间**: 较长（需要重新初始化）
- **适用场景**: 完全不需要蓝牙时

**结论**: 使用 **System ON 模式**，通过 RTC 定时器唤醒。

### 4.3 RTC 定时器配置

```c
// 使用 nRF52810 的 RTC0 作为定时器
// 配置为 32.768kHz 时钟源（内部 RC 或外部晶振）

// 定时器结构
struct k_timer sample_timer;

// 定时器回调
void sample_timer_handler(struct k_timer *timer)
{
    // 唤醒系统，触发采集任务
    k_work_submit(&sample_work);
}

// 配置定时器
k_timer_init(&sample_timer, sample_timer_handler, NULL);
k_timer_start(&sample_timer, K_SECONDS(sample_interval), K_NO_WAIT);
```

### 4.4 主循环优化

```c
int main(void)
{
    // 初始化...

    while (1) {
        // 1. 采集温湿度
        aht30_read(&temperature, &humidity);

        // 2. 存储数据
        buffer_add_record(timestamp, temperature, humidity);

        // 3. 更新 GATT 特性
        update_gatt_characteristics();

        // 4. 发送通知（如果已连接）
        if (bt_connected && notify_enabled) {
            bt_gatt_notify(...);
        }

        // 5. 进入低功耗模式
        // k_sleep() 会自动让系统进入 System ON 模式
        k_sleep(K_SECONDS(sample_interval));

        // 6. 唤醒后继续循环
    }
}
```

### 4.5 蓝牙广播优化

```c
// 初始 30 秒：快速广播（便于发现）
bt_le_adv_start(BT_LE_ADV_CONN_FAST_1, ad, ARRAY_SIZE(ad), NULL, 0);

// 30 秒后：切换到慢速广播（降低功耗）
k_work_schedule(&adv_slow_work, K_SECONDS(30));

// 慢速广播回调
void adv_slow_work_handler(struct k_work *work)
{
    bt_le_adv_stop();
    // 使用自定义参数：间隔 2-5 秒
    struct bt_le_adv_param param = {
        .options = BT_LE_ADV_OPT_CONNECTABLE,
        .interval_min = BT_GAP_ADV_FAST_INT_MIN_2,  // 2秒
        .interval_max = BT_GAP_ADV_FAST_INT_MAX_2,  // 5秒
    };
    bt_le_adv_start(&param, ad, ARRAY_SIZE(ad), NULL, 0);
}
```

---

## 5. 配置持久化

### 5.1 存储方案

由于 nRF52810 Flash 寿命有限，建议使用 **Settings 子系统**（Zephyr 自带）或简单的 Flash 存储。

#### 方案一：Settings 子系统（推荐）

- **优点**: 自动管理 Flash 磨损均衡
- **缺点**: 需要额外配置
- **实现**: 使用 `CONFIG_SETTINGS=y`

#### 方案二：简单 Flash 存储

- **优点**: 实现简单，内存占用小
- **缺点**: 需要手动管理磨损
- **实现**: 使用 `flash_write()` API

### 5.2 配置数据结构

```c
// 配置结构（存储在 Flash）
typedef struct {
    uint16_t sample_interval;  // 采集间隔（秒）
    uint8_t  reserved[2];      // 保留
} __packed device_config_t;

// 默认配置
#define DEFAULT_SAMPLE_INTERVAL  30  // 30秒

// 配置存储地址（Flash 末尾，避免与代码冲突）
#define CONFIG_FLASH_ADDR  0x00030000  // 示例地址
```

### 5.3 配置读取/写入流程

```c
// 启动时读取配置
static void load_config(void)
{
    device_config_t config;
    int ret = flash_read(...);
    if (ret == 0 && config.sample_interval >= 10 && config.sample_interval <= 3600) {
        sample_interval = config.sample_interval;
    } else {
        sample_interval = DEFAULT_SAMPLE_INTERVAL;  // 使用默认值
    }
}

// 配置改变时保存
static void save_config(void)
{
    device_config_t config = {
        .sample_interval = sample_interval,
    };
    flash_write(CONFIG_FLASH_ADDR, &config, sizeof(config));
}
```

---

## 6. 功耗计算与续航预估

### 6.1 功耗模型

#### 睡眠期间（占大部分时间）

| 组件 | 功耗 | 说明 |
| --- | --- | --- |
| System ON 睡眠 | 1-2 μA | MCU 深度睡眠 |
| RTC 定时器 | 0.5-1 μA | 保持计时 |
| **小计** | **1.5-3 μA** | 睡眠期间 |

#### 唤醒期间（短暂）

| 组件 | 功耗 | 持续时间 | 说明 |
| --- | --- | --- | --- |
| MCU 运行 | 4-5 mA | 100-200ms  | 采集和处理 |
| I2C 通信 | 1-2 mA | 80ms | AHT30 读取 |
| 蓝牙（如连接） | 0.5-2 mA | 50ms | 发送通知 |
| **小计** | **5-9 mA** | **~300ms** | 每次采集 |

#### 蓝牙广播期间

| 模式 | 功耗 | 说明 |
| --- | --- | --- |
| 快速广播 | 5-8 mA | 前 30 秒 |
| 慢速广播 | 0.1-0.3 mA | 之后 |

### 6.2 平均功耗计算

#### 场景一：采集间隔 = 30 秒，未连接

```
睡眠时间: 29.7秒 (99%)
唤醒时间: 0.3秒 (1%)

平均功耗 = (1.5μA × 29.7s + 6mA × 0.3s) / 30s
         = (0.0445mAs + 1.8mAs) / 30s
         = 0.0615 mA ≈ 0.06 mA
```

#### 场景二：采集间隔 = 60 秒，未连接

```
平均功耗 ≈ 0.03 mA
```

#### 场景三：采集间隔 = 300 秒（5 分钟），未连接

```
平均功耗 ≈ 0.006 mA
```

### 6.3 续航时间预估

**电池容量**: 220 mAh (CR2032)

| 采集间隔 | 平均功耗 | 续航时间 | 说明 |
| --- | --- | --- | --- |
| 10 秒 | 0.18 mA  | **1222 小时** (51 天) | 高频采集 |
| 30 秒 | 0.06 mA  | **3667 小时** (153 天) | 推荐配置 |
| 60 秒 | 0.03 mA  | **7333 小时** (305 天) | 低频采集 |
| 300 秒 | 0.006 mA | **36667 小时** (1528 天) | 极低频 |

**注意**: 实际续航会受到蓝牙连接、LED 使用等因素影响。

---

## 7. 代码实现要点

### 7.1 关键配置（prj.conf）

```conf
# 电源管理（必需）
CONFIG_PM=y
CONFIG_PM_DEVICE=y

# RTC 定时器（必需）
CONFIG_CLOCK_CONTROL_NRF_K32SRC_RC=y  # 使用内部 RC（已有）

# DCDC 转换器（降低功耗）
CONFIG_BOARD_ENABLE_DCDC=y

# 可选：关闭 UART 以降低功耗（生产环境）
# CONFIG_SERIAL=n
# CONFIG_CONSOLE=n
```

### 7.2 关键代码结构

```c
// 全局变量
static uint16_t sample_interval = 30;  // 采集间隔（秒）
static struct k_timer sample_timer;    // 采集定时器
static struct k_work sample_work;      // 采集工作队列

// 采集定时器回调
void sample_timer_handler(struct k_timer *timer)
{
    k_work_submit(&sample_work);
}

// 采集工作函数
void sample_work_handler(struct k_work *work)
{
    int32_t temperature, humidity;

    // 读取传感器
    aht30_read(&temperature, &humidity);

    // 存储数据
    buffer_add_record(get_current_timestamp(), temperature, humidity);

    // 更新 GATT
    update_gatt_characteristics(temperature, humidity);

    // 发送通知
    if (bt_connected) {
        bt_gatt_notify(...);
    }

    // 设置下次唤醒
    k_timer_start(&sample_timer, K_SECONDS(sample_interval), K_NO_WAIT);
}

// 配置写入回调（GATT）
static ssize_t interval_char_write_cb(...)
{
    uint16_t new_interval = sys_get_le16(buf);

    // 验证范围
    if (new_interval < 10 || new_interval > 3600) {
        return BT_GATT_ERR(BT_ATT_ERR_VALUE_NOT_ALLOWED);
    }

    // 更新配置
    sample_interval = new_interval;

    // 保存到 Flash
    save_config();

    // 重启定时器
    k_timer_stop(&sample_timer);
    k_timer_start(&sample_timer, K_SECONDS(sample_interval), K_NO_WAIT);

    return len;
}

// 主循环
int main(void)
{
    // 初始化...

    // 加载配置
    load_config();

    // 初始化定时器
    k_timer_init(&sample_timer, sample_timer_handler, NULL);
    k_work_init(&sample_work, sample_work_handler);

    // 启动第一次采集
    k_work_submit(&sample_work);

    // 主循环：进入低功耗
    while (1) {
        // k_sleep() 会让系统进入 System ON 模式
        // 定时器唤醒后会触发工作队列，然后继续睡眠
        k_sleep(K_FOREVER);  // 永久睡眠，等待定时器唤醒
    }
}
```

---

## 8. 实施计划

### 8.1 阶段一：基础功能（1-2 天）

- [ ] 添加配置服务 GATT 定义
- [ ] 实现采集间隔读取/写入
- [ ] 实现配置持久化（Flash 存储）
- [ ] 测试手机端配置功能

### 8.2 阶段二：低功耗优化（2-3 天）

- [ ] 实现 RTC 定时器唤醒
- [ ] 优化主循环，使用 k_sleep()
- [ ] 优化蓝牙广播策略
- [ ] 关闭/优化 LED 闪烁
- [ ] 功耗测试与验证

### 8.3 阶段三：优化与测试（1-2 天）

- [ ] 优化 I2C 总线管理
- [ ] 添加错误处理和恢复
- [ ] 完整功能测试
- [ ] 续航测试

---

## 9. 功耗测试方法（RF CONNECT）

### 9.1 RF CONNECT 工具介绍

**RF CONNECT**（也称为 **Power Profiler**）是 Nordic 官方提供的功耗测试工具，用于精确测量 nRF 系列芯片的实时功耗。

#### 工具特点

- **高精度**: 可测量 μA 级别的电流
- **实时显示**: 实时功耗曲线和统计数据
- **时间降额**: 支持长时间测试的降额功能
- **多模式**: 支持平均功耗、峰值功耗、能量统计等

### 9.2 测试连接方法

#### 硬件连接

```
┌─────────────┐         ┌──────────────┐         ┌─────────────┐
│  E104-BT    │         │  RF CONNECT  │         │   电源/电池  │
│  BT5010A    │────────>│  Power      │────────>│             │
│  设备       │  VDD    │  Profiler   │  VDD    │             │
└─────────────┘         └──────────────┘         └─────────────┘
```

**连接步骤**:

1. 断开设备电源（移除电池或断开电源线）
2. 将 RF CONNECT 的 **VDD** 输出连接到设备的 **VDD** 引脚
3. 将 RF CONNECT 的 **GND** 连接到设备的 **GND** 引脚
4. 确保 RF CONNECT 通过 USB 连接到电脑
5. 在 RF CONNECT 软件中设置输出电压（通常为 **3.0V**，匹配 CR2032 电池电压）

### 9.3 RF CONNECT 软件配置

#### 基本设置

1. **打开 RF CONNECT 软件**
2. **选择设备**: 选择连接的 Power Profiler 设备
3. **设置电压**: 设置为 **3.0V**（匹配 CR2032 电池电压）
4. **设置电流范围**:
   - 睡眠期间：选择 **μA 范围**（例如 0-100 μA）
   - 唤醒期间：选择 **mA 范围**（例如 0-10 mA）
   - 或使用 **自动范围**

#### 测试模式选择

| 模式 | 说明 | 适用场景 |
| --- | --- | --- |
| **实时模式** | 实时显示功耗曲线 | 观察功耗变化、调试 |
| **平均模式** | 计算平均功耗 | 验证理论计算值 |
| **能量模式** | 计算总能量消耗 | 评估电池续航 |

### 9.4 时间降额（Time Derating）配置

#### 什么是时间降额？

**时间降额**（Time Derating）是 RF CONNECT 的一个功能，用于处理**长时间测试**的情况。当测试时间过长时，可以通过降额功能来**加速测试**，同时保持测试结果的准确性。

#### 为什么需要时间降额？

- **测试时间过长**: 例如测试 30 秒采集间隔的功耗，需要等待多个周期才能获得准确的平均值
- **提高效率**: 通过降额可以缩短实际测试时间
- **保持准确性**: 降额算法确保测试结果仍然准确

#### 如何设置时间降额？

##### 方法一：通过软件界面设置

1. **打开 RF CONNECT 软件**
2. **进入设置菜单**: 点击右上角的 **设置图标**（齿轮图标）
3. **找到 "Time Derating" 选项**:
   - 位置：`Settings` → `Measurement` → `Time Derating`
4. **设置降额参数**:
   - **Derating Factor（降额因子）**: 例如设置为 **10** 或 **100**
     - `10`: 实际测试 1 秒，相当于测试 10 秒
     - `100`: 实际测试 1 秒，相当于测试 100 秒
   - **Derating Mode（降额模式）**:
     - `Linear`: 线性降额（推荐）
     - `Exponential`: 指数降额

##### 方法二：通过配置文件设置

如果软件支持，可以在配置文件中设置：

```json
{
  "measurement": {
    "time_derating": {
      "enabled": true,
      "factor": 100,
      "mode": "linear"
    }
  }
}
```

#### 时间降额计算示例

假设设备采集间隔为 **30 秒**，需要测试 **10 个周期**（300 秒）：

**不使用降额**:

- 实际测试时间: **300 秒**（5 分钟）
- 测试结果: 准确的平均功耗

**使用降额因子 10**:

- 实际测试时间: **30 秒**（0.5 分钟）
- 等效测试时间: **300 秒**
- 测试结果: 通过算法计算，保持准确性

**使用降额因子 100**:

- 实际测试时间: **3 秒**
- 等效测试时间: **300 秒**
- 测试结果: 通过算法计算，但精度可能略低

#### 推荐降额设置

| 采集间隔 | 测试周期数 | 推荐降额因子 | 实际测试时间 |
| --- | --- | --- | --- |
| 10 秒 | 10 个周期  | 10 | 10 秒 |
| 30 秒 | 10 个周期  | 10 | 30 秒 |
| 60 秒 | 10 个周期  | 20 | 30 秒 |
| 300 秒 | 5 个周期 | 50 | 30 秒 |

**注意**:

- 降额因子不宜过大（建议 < 100），否则可能影响精度
- 对于短间隔（< 30 秒），可以不使用降额
- 对于长间隔（> 60 秒），建议使用降额以提高效率

### 9.5 测试步骤

#### 完整测试流程

1. **硬件连接**

   - 按照 9.2 节连接 RF CONNECT 和设备

2. **软件配置**

   - 打开 RF CONNECT 软件
   - 设置电压为 3.0V
   - 设置电流范围（或自动范围）
   - **配置时间降额**（如需要）

3. **设备配置**

   - 通过手机 APP 设置采集间隔（例如 30 秒）
   - 确保设备进入正常工作状态

4. **开始测试**

   - 点击 **Start Measurement**（开始测量）
   - 观察实时功耗曲线
   - 等待足够的测试周期（建议至少 5-10 个采集周期）

5. **停止测试**

   - 点击 **Stop Measurement**（停止测量）
   - 查看统计结果：
     - **平均功耗**（Average Current）
     - **峰值功耗**（Peak Current）
     - **总能量**（Total Energy）

6. **结果分析**
   - 记录睡眠期间的平均功耗
   - 记录唤醒期间的平均功耗
   - 计算整体平均功耗
   - 与理论计算值对比

### 9.6 测试场景

#### 场景一：睡眠期间功耗测试

**目标**: 验证睡眠期间功耗 < 3 μA

**步骤**:

1. 设置采集间隔为 **300 秒**（5 分钟，减少唤醒干扰）
2. 等待设备进入睡眠状态
3. 开始测量，测试 **5-10 分钟**
4. 查看平均功耗

**预期结果**: 平均功耗应在 **1.5-3 μA** 范围内

#### 场景二：完整周期功耗测试

**目标**: 验证整体平均功耗

**步骤**:

1. 设置采集间隔为 **30 秒**
2. 开始测量，测试 **5-10 个周期**（150-300 秒）
3. 使用时间降额（因子 10），实际测试 **15-30 秒**
4. 查看平均功耗

**预期结果**:

- 30 秒间隔：平均功耗约 **0.06 mA**
- 60 秒间隔：平均功耗约 **0.03 mA**

#### 场景三：蓝牙广播功耗测试

**目标**: 验证蓝牙广播功耗

**步骤**:

1. 断开蓝牙连接（如果已连接）
2. 观察前 30 秒（快速广播）的功耗
3. 观察 30 秒后（慢速广播）的功耗

**预期结果**:

- 快速广播：**5-8 mA**
- 慢速广播：**0.1-0.3 mA**

### 9.7 常见问题

#### Q1: 时间降额在哪里设置？

**A**: 在 RF CONNECT 软件的设置菜单中：

- `Settings` → `Measurement` → `Time Derating`
- 或通过配置文件设置

#### Q2: 降额因子设置多少合适？

**A**:

- 短间隔（< 30 秒）：可以不使用降额或使用因子 10
- 长间隔（> 60 秒）：建议使用因子 10-50
- 极长间隔（> 300 秒）：可以使用因子 50-100

#### Q3: 降额会影响测试精度吗？

**A**:

- 降额因子 < 50：影响很小，可以忽略
- 降额因子 50-100：可能有轻微影响，但仍在可接受范围
- 降额因子 > 100：不推荐，可能影响精度

#### Q4: 如何验证降额后的结果准确性？

**A**:

1. 先不使用降额测试一次（作为基准）
2. 再使用降额测试一次
3. 对比两次结果，误差应在 **5%** 以内

### 9.8 测试报告模板

```
功耗测试报告
============

设备: E104-BT5010A
固件版本: v1.0
测试日期: 2026-01-13
测试工具: RF CONNECT Power Profiler

测试条件:
- 电压: 3.0V
- 采集间隔: 30 秒
- 测试周期: 10 个周期
- 时间降额: 10x

测试结果:
- 睡眠期间平均功耗: 2.1 μA
- 唤醒期间平均功耗: 6.5 mA
- 整体平均功耗: 0.065 mA
- 峰值功耗: 8.2 mA

理论计算值: 0.06 mA
实际测量值: 0.065 mA
误差: +8.3%

结论: 测试结果与理论计算基本一致，功耗优化效果良好。
```

---

## 10. 注意事项

### 10.1 蓝牙连接时的功耗

- 已连接时，系统需要保持蓝牙栈运行
- 功耗会增加到 **1-2 mA**（取决于连接间隔）
- 建议：连接时适当缩短采集间隔，断开后恢复

### 10.2 Flash 寿命

- 配置写入频率低（仅在用户修改时）
- 使用磨损均衡或简单存储方案
- 预计寿命：**10+ 年**（假设每天修改一次）

### 10.3 唤醒延迟

- RTC 定时器精度：±500ppm（内部 RC）
- 实际误差：约 **±0.05%**（30 秒间隔误差约 ±15ms）
- 可接受范围

### 10.4 调试建议

- 开发阶段保留 UART 输出
- 生产环境关闭 UART 以降低功耗
- 使用条件编译控制调试输出

---

## 11. 总结

### 11.1 方案优势

- ✅ **灵活配置**: 手机可动态调整采集间隔（10-3600 秒）
- ✅ **超低功耗**: 睡眠期间功耗 < 3 μA
- ✅ **长续航**: 30 秒间隔可达 **153 天**
- ✅ **配置持久化**: 断电后配置不丢失
- ✅ **实现简单**: 基于 Zephyr 标准 API

### 11.2 预期效果

- **功耗降低**: 从 15 mA → 0.06 mA（30 秒间隔）
- **续航提升**: 从 15 小时 → **153 天**（30 秒间隔）
- **用户体验**: 手机可灵活配置，满足不同场景需求

---

_文档版本: 1.1_  
_更新日期: 2026-01-13_  
_更新内容: 添加 RF CONNECT 功耗测试和时间降额配置说明_

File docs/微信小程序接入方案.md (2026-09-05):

# 微信小程序接入温湿度BLE服务方案

## 1. 方案概述

微信小程序支持完整的 BLE (Bluetooth Low Energy) 功能，可以连接 E104-BT5010A 蓝牙温湿度采集设备，访问所有 GATT 服务，包括：

- ✅ **温湿度服务**：读取和订阅温湿度数据
- ✅ **时间同步服务**：向设备发送时间
- ✅ **配置服务**：读取和配置设备参数

## 2. 前置条件

### 2.1 微信小程序配置

在 `app.json` 中配置蓝牙权限：

```json
{
  "permission": {
    "scope.bluetooth": {
      "desc": "需要蓝牙权限连接温湿度设备"
    }
  },
  "requiredPrivateInfos": ["getBluetoothDevices", "onBluetoothDeviceFound"]
}
```

### 2.2 系统权限

- **Android**：需要定位权限（系统将 BLE 扫描与定位关联）
- **iOS**：需要蓝牙权限，且在系统设置中允许小程序访问蓝牙

### 2.3 设备信息

| 项目 | 值 |
|---|-----|
| **设备名称** | `yodfz-temp` |
| **服务 UUID** | `12340001-1234-5678-1234-56789abcdef0` (温湿度服务) |
| **温度特性 UUID** | `12340002-1234-5678-1234-56789abcdef0` |
| **湿度特性 UUID** | `12340003-1234-5678-1234-56789abcdef0` |
| **时间服务 UUID** | `12340010-1234-5678-1234-56789abcdef0` |
| **配置服务 UUID** | `12340020-1234-5678-1234-56789abcdef0` |

**注意**：UUID 必须使用**小写字母**和完整 128 位格式，以确保 Android 和 iOS 平台兼容。

## 3. 完整接入代码示例

### 3.1 设备连接管理类

创建 `utils/bleManager.js`：

```javascript
// 温湿度设备 BLE 管理器
class BLEManager {
  constructor() {
    this.deviceId = null;
    this.serviceId = null;
    this.tempCharId = null;
    this.humidityCharId = null;
    this.isConnected = false;
    this.onTempHumidityChange = null; // 温湿度变化回调
  }

  // 打开蓝牙适配器
  async openAdapter() {
    return new Promise((resolve, reject) => {
      wx.openBluetoothAdapter({
        success: (res) => {
          console.log('蓝牙适配器打开成功', res);
          resolve(res);
        },
        fail: (err) => {
          console.error('蓝牙适配器打开失败', err);
          reject(err);
        }
      });
    });
  }

  // 开始扫描设备
  async startScan() {
    return new Promise((resolve, reject) => {
      wx.startBluetoothDevicesDiscovery({
        services: ['12340001-1234-5678-1234-56789abcdef0'], // 可选：指定服务UUID过滤
        allowDuplicatesKey: false,
        interval: 0,
        success: (res) => {
          console.log('开始扫描设备', res);
          resolve(res);
        },
        fail: (err) => {
          console.error('扫描失败', err);
          reject(err);
        }
      });
    });
  }

  // 监听设备发现
  onDeviceFound(callback) {
    wx.onBluetoothDeviceFound((res) => {
      const devices = res.devices || [];
      devices.forEach(device => {
        // 通过设备名称或服务UUID匹配
        if (device.name === 'yodfz-temp' || 
            (device.advertisServiceUUIDs && 
             device.advertisServiceUUIDs.includes('12340001-1234-5678-1234-56789abcdef0'))) {
          console.log('发现目标设备', device);
          callback(device);
        }
      });
    });
  }

  // 停止扫描
  stopScan() {
    wx.stopBluetoothDevicesDiscovery();
    wx.offBluetoothDeviceFound();
  }

  // 连接设备
  async connectDevice(deviceId) {
    return new Promise((resolve, reject) => {
      wx.createBLEConnection({
        deviceId: deviceId,
        success: (res) => {
          console.log('设备连接成功', res);
          this.deviceId = deviceId;
          this.isConnected = true;
          resolve(res);
        },
        fail: (err) => {
          console.error('设备连接失败', err);
          this.isConnected = false;
          reject(err);
        }
      });
    });
  }

  // 断开连接
  async disconnectDevice() {
    if (!this.deviceId) return;
    
    return new Promise((resolve, reject) => {
      wx.closeBLEConnection({
        deviceId: this.deviceId,
        success: (res) => {
          console.log('设备断开成功', res);
          this.deviceId = null;
          this.isConnected = false;
          resolve(res);
        },
        fail: (err) => {
          console.error('设备断开失败', err);
          reject(err);
        }
      });
    });
  }

  // 获取服务列表
  async getServices() {
    return new Promise((resolve, reject) => {
      wx.getBLEDeviceServices({
        deviceId: this.deviceId,
        success: (res) => {
          console.log('获取服务列表成功', res);
          resolve(res.services || []);
        },
        fail: (err) => {
          console.error('获取服务列表失败', err);
          reject(err);
        }
      });
    });
  }

  // 获取特征值列表
  async getCharacteristics(serviceId) {
    return new Promise((resolve, reject) => {
      wx.getBLEDeviceCharacteristics({
        deviceId: this.deviceId,
        serviceId: serviceId,
        success: (res) => {
          console.log('获取特征值列表成功', res);
          resolve(res.characteristics || []);
        },
        fail: (err) => {
          console.error('获取特征值列表失败', err);
          reject(err);
        }
      });
    });
  }

  // 初始化温湿度服务
  async initTempHumidityService() {
    try {
      // 1. 获取服务列表
      const services = await this.getServices();
      const envService = services.find(s => 
        s.uuid.toLowerCase() === '12340001-1234-5678-1234-56789abcdef0'
      );

      if (!envService) {
        throw new Error('未找到温湿度服务');
      }

      this.serviceId = envService.uuid;
      console.log('找到温湿度服务', this.serviceId);
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

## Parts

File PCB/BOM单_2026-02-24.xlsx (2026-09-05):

No. | 备注 | Designator | 封装 | 值 | 数量 | LCSC Price | 淘宝购买价 |  | Description
1 | MY-2032-12 | BT1 | BAT-SMD_MY-2032-12 |  | 1 | 0.6072 | 0.08 | 0.08 | 适用电池规格：CR2032/BR2032/LIR2032卧式贴片工艺，材质:磷铜 镀镍 SMT回流焊工艺标准
2 | 1uF | C1 | C0603 | 1uF | 1 | 0.0308 | 0.0726 | 0.0726 | 容值:1uF;精度:±10%;额定电压:50V;温度系数:X5R;
3 | 12pF | C2,C3 | C0402 | 12pF | 2 | 0.0054 | 0.02 | 0.04 | 容值:12pF;精度:±5%;额定电压:50V;温度系数:C0G;
4 | 22pF | C4,C5 | C0402 | 22pF | 2 | 0.0076 | 0.02 | 0.04 | 容值:22pF;精度:±5%;额定电压:50V;温度系数:C0G;
5 | 100nF | C6,C7,C8,C10,C11,C12,C13,NCC1,NCC2 | C0402 | 100nF | 9 | 0.0081 | 0.0145 | 0.1305 | 容值:100nF;精度:±10%;额定电压:16V;温度系数:X7R;
6 | 10uF | C9 | C0603 | 10uF | 1 | 0.0425 | 0.0678 | 0.0678 | 容值:10uF;精度:±10%;额定电压:10V;温度系数:X5R;
7 | 2.54-1*4P母 | H1 | HDR-TH_4P-P2.54-V-F |  | 1 | 0.3701 | 0 | 0 | 插孔结构:1x4P;间距:2.54mm;行距:-;圆孔/方孔:方孔;安装方式:直插;排数:单排;总孔位数:4P;额定电流:3A;额定电压:-;插孔方向:顶部;塑高:-;触头材质:青铜;触头镀层:-;工作温度:-40℃~+105℃;
8 | 10uH | L1 | L0603 | 10uH | 1 | 0.2916 | 0.06 | 0.06 | 电感值:10uH;精度:±20%;额定电流:50mA;饱和电流(Isat):50mA;直流电阻(DCR):1.17Ω;
9 | 15nH | L2 | L0402 | 15nH | 1 | 0.0305 | 0.03 | 0.03 | 电感值:15nH;精度:±5%;额定电流:300mA;饱和电流(Isat):-;直流电阻(DCR):500mΩ;
10 | RFECA3216060A1T | L3 | ANT-SMD_L3.1-W1.6 |  | 1 | 0.2126 | 0.1 | 0.1 | 天线类型:陶瓷天线;中心频点:2.4GHz;带宽:-;峰值增益:2dBi;极化方式:-;功率容量:-;驻波比:2.1;
11 | 3.9nH | L4 | L0402 | 3.9nH | 1 | 0.0529 | 0.03 | 0.03 | 电感值:3.9nH;精度:-;额定电流:700mA;饱和电流(Isat):-;直流电阻(DCR):110mΩ;
12 | 4.7kΩ | R1,R2 | R0603 | 4.7kΩ | 2 | 0.0077 | 0.02 | 0.04 | 电阻类型:厚膜电阻;阻值:4.7kΩ;精度:±1%;功率:100mW;工作电压:75V;温度系数:±100ppm/℃;
13 | 1kΩ | R3 | R0603 | 1kΩ | 1 | 0.0072 | 0.02 | 0.02 | 电阻类型:厚膜电阻;阻值:1kΩ;精度:±1%;功率:100mW;工作电压:75V;温度系数:±100ppm/℃;
14 | NRF52832-QFAA-R | U1 | QFN-48_L6.0-W6.0-P0.40-BL-EP3.8 |  | 1 | 18.28 | 2.2 | 2.2 | 频率范围:-;接口类型:I2C；UART；SPI;应用领域:IoT；蓝牙;数据速率:2Mbps;灵敏度:-96dBm;典型应用频率:2.4GHz;
15 | AHT30 | U2 | MIC-SMD_6P-L3.0-W3.0-P1.00-TL |  | 1 | 4.12 | 1.2 | 1.2 | AHT30是一款全新的温湿度传感器，具有功耗低、精度高的优点，它嵌入了适于回流焊的双列扁平无引脚SMD封装，拥有坚固的外壳和微小的尺寸，可轻松集成至高难度的设计中。AHT30配有一个全新优化的ASIC专用芯片、一个经过改进的MEMS半导体电容式湿度传感元件和一个标准的片上温度传感元件，其性能已获得显著的提升，即使在恶劣的环境下也能保持稳定性能。
16 | SPL06-001 | U3 | SENSOR-SMD_SPL06-001 |  | 1 | 5.6 | 2.63 | 2.63 | 压力范围:30Kpa~1.1bar;接口类型:I2C；SPI;
17 | W25Q64JVZPIQ | U4 | WSON-8_L6.0-W5.0-P1.27-BL-EP |  | 1 | 14.3 | 1.43 | 1.43 | 接口类型:SPI;存储容量:64Mbit;时钟频率(fc):133MHz;
18 | RED-LED_0603 | U5 | LED0603-R-RD_RED |  | 1 |  | 0.02 | 0.02
19 | 32MHz | X1 | CRYSTAL-SMD_4P-L3.2-W2.5-BL | 32MHz | 1 | 0.4624 | 0.3 | 0.3 | 晶振类型:贴片晶振;频率:32MHz;常温频差:±10ppm;负载电容:12pF;频率稳定度:±20ppm;
20 | 32.768kHz | X2 | CRYSTAL-SMD_L3.2-W1.5-1 | 32.768kHz | 1 | 1.0408 | 0.3 | 0.3 | 晶振类型:贴片晶振;频率:32.768kHz;常温频差:±20ppm;负载电容:12.5pF;频率稳定度:±30ppm;
 |  |  |  |  |  |  |  | 8.7909

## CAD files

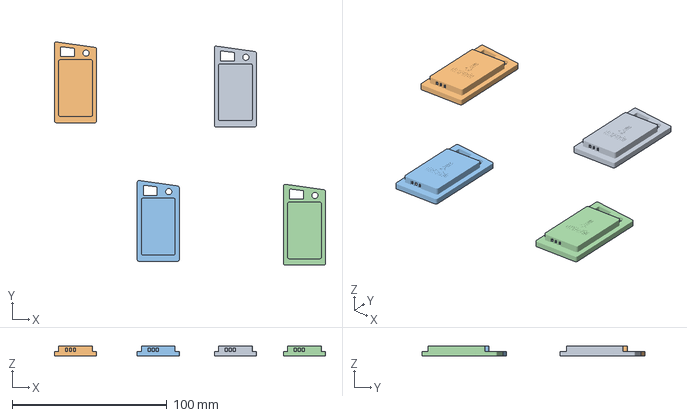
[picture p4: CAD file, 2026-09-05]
3DModel/底部.3mf
175.0 x 144.1 x 6.63 mm
底部 x 4

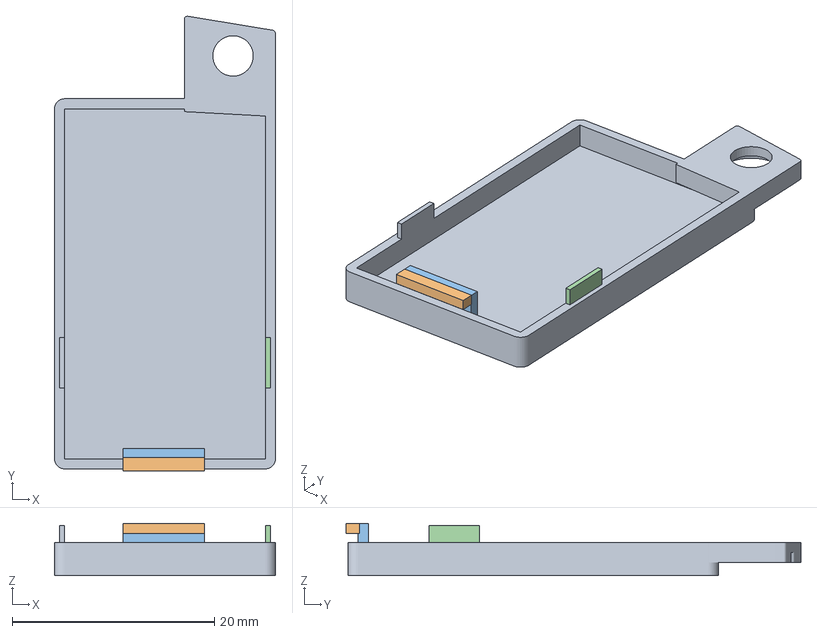
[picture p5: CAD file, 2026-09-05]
3DModel/外壳.3mf
21.9 x 45.0 x 5.18 mm
单盖
单盖1
单盖2
单盖3

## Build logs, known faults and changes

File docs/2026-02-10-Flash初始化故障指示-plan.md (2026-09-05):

# Flash 初始化故障指示开发计划

## 需求背景
用户要求在系统初始化时，如果 Flash (W25Q64) 不可用，系统应进入故障状态并持续闪烁 LED 灯进行指示。

## 实现方案

### 1. 修改 `storage_init` 函数
- **文件**: `src/main.c`
- **修改**: 将 `storage_init` 的返回类型从 `void` 改为 `int`。
- **逻辑**: 
  - 如果 `w25q64_init()` 返回非 0，`storage_init` 返回该错误码。
  - 否则返回 0。

### 2. 在 `main` 函数中处理初始化失败
- **文件**: `src/main.c`
- **位置**: 调用 `storage_init()` 处。
- **逻辑**:
  - 接收 `storage_init()` 的返回值。
  - 如果返回值不为 0（表示失败）：
    - 打印错误日志。
    - 进入死循环 `while(1)`。
    - 在循环中每 100ms 翻转所有 LED (`LED_MASK`)，实现持续快速闪烁。

### 3. 在 `storage_write_batch` 中添加 LED 指示
- **文件**: `src/main.c`
- **位置**: `storage_write_batch` 函数开头或写入成功后。
- **逻辑**:
  - 调用 `led_start_data_blink()` 函数（该函数已在 `led.c` 中实现，效果为 DATA LED 闪烁 3 次）。
  - 确保该函数调用不会阻塞 Flash 写入操作。

## 验证计划
1. **代码审查**: 确认修改逻辑正确，无编译错误。
2. **测试**:
   - **故障模拟**: 模拟 `storage_init` 返回错误，验证系统是否死循环闪烁。
   - **写入指示**: 触发 Flash 写入（例如等待数据缓冲区满），验证 DATA LED 是否闪烁 3 次。

## 待办事项
- [ ] 修改 `src/main.c` 中的 `storage_init` 声明和定义。
- [ ] 在 `main` 函数中添加错误处理和死循环闪烁逻辑。

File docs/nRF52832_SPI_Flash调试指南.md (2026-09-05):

# nRF52832 SPI Flash (W25Q64) 访问问题调试指南

## 问题描述
nRF52832 无法访问 SPI Flash 存储器 (W25Q64)

## 已知配置
- **芯片**: nRF52832
- **Flash**: W25Q64 (8MB SPI NOR Flash)
- **SPI 引脚**: SCK=P0.30, MOSI=P0.31, MISO=P0.29, CS=P0.28
- **使用外设**: SPI1 (因为 SPI0 与 I2C0 共用基址 0x40003000)

## 可能原因及解决方案

### 1. SPI1 设备树节点未启用

**检查方法**:
编译后查看生成的设备树:
```bash
west build -b nrf52832dk_nrf52832 --build-dir build_nrf52832
cat build_nrf52832/zephyr/zephyr.dts | grep -A 20 "spi1"
```

**解决方案**: 已在 `boards/nrf52832dk_nrf52832_cpuapp.overlay` 中添加完整的 SPI1 配置

### 2. SPI 频率过高导致通信不稳定

**原因**: 
- 硬件布线较长或有干扰
- 电源不稳定
- Flash 芯片质量问题

**解决方案**: 已将 SPI 频率从 8MHz 降低到 4MHz

### 3. CS 引脚配置问题

**检查**:
- CS 引脚 (P0.28) 是否正确配置为 GPIO 输出
- CS 引脚是否与其他功能冲突

**验证代码**:
```c
const struct device *gpio_dev = DEVICE_DT_GET(DT_NODELABEL(gpio0));
if (!device_is_ready(gpio_dev)) {
    printk("GPIO设备未就绪\n");
}
int ret = gpio_pin_configure(gpio_dev, 28, GPIO_OUTPUT_INACTIVE);
printk("CS引脚配置结果: %d\n", ret);
```

### 4. 引脚复用冲突

**检查项目**:
- P0.28 是否被其他外设使用 (UART, I2C, 其他 SPI)
- P0.30/31/29 是否有冲突

**查看方法**:
```bash
grep -r "P0.28\|P0.30\|P0.31\|P0.29" boards/nrf52832dk_nrf52832_cpuapp.overlay
```

### 5. 电源问题

**检查**:
- Flash 芯片供电是否稳定 (3.3V)
- 是否有足够的去耦电容
- 电源纹波是否过大

**测试**: 使用万用表测量 VCC 引脚电压

### 6. 硬件连接问题

**检查清单**:
- [ ] SCK, MOSI, MISO, CS 引脚是否正确连接
- [ ] 是否有虚焊或接触不良
- [ ] 信号线是否过长 (建议 < 10cm)
- [ ] 是否有上拉/下拉电阻配置错误

### 7. Flash 芯片损坏或型号不匹配

**验证方法**:
读取 JEDEC ID 应该返回: `0xEF 0x40 0x17`

**测试代码** (已在 w25q64_init 中):
```c
uint8_t id[3];
// ... SPI 读取 JEDEC ID ...
printk("JEDEC ID: 0x%02X 0x%02X 0x%02X\n", id[0], id[1], id[2]);
```

## 调试步骤

### 步骤 1: 编译并烧录固件
```bash
west build -b nrf52832dk_nrf52832 --build-dir build_nrf52832
west flash -d build_nrf52832
```

### 步骤 2: 查看串口日志
连接串口 (115200 8N1)，查看以下关键信息:
```
[W25Q64] 使用 SPI1 (nRF52832)
[W25Q64] SPI设备名称: spi@40004000
[W25Q64] SPI设备已就绪
[W25Q64] CS GPIO配置成功
[W25Q64] JEDEC ID: 0xEF 0x40 0x17
```

### 步骤 3: 如果 "SPI设备未就绪"

检查设备树配置:
```bash
# 查看编译后的设备树
cat build_nrf52832/zephyr/zephyr.dts | grep -A 30 "spi@40004000"

# 查看 Kconfig 配置
grep SPI build_nrf52832/zephyr/.config
```

确认以下配置已启用:
```
CONFIG_SPI=y
CONFIG_SPI_NRFX=y
CONFIG_SPI_1=y  # 或 CONFIG_SPI_NRFX_SPIM1=y
```

### 步骤 4: 如果 JEDEC ID 读取失败或返回全 0xFF

可能原因:
1. **MISO 引脚无信号** - 检查硬件连接
2. **Flash 未上电** - 检查电源
3. **SPI 时序问题** - 降低频率到 1MHz 测试

临时测试代码 (降低到 1MHz):
```c
w25q64_spi_cfg.frequency = 1000000;  // 1MHz
```

### 步骤 5: 如果 JEDEC ID 正确但读写失败

检查:
1. 块保护位是否启用 - 查看日志中的 BP 值
2. 写使能是否成功 - WEL 位应该为 1
3. 是否有超时 - 增加超时时间

## 硬件测试方法

### 使用逻辑分析仪
捕获 SPI 信号，检查:
- SCK 频率是否正确
- MOSI 数据是否正确发送
- MISO 是否有响应
- CS 是否正确拉低/拉高

### 使用示波器
测量:
- SCK 信号质量 (上升/下降沿)
- 信号完整性 (是否有振铃、过冲)
- 电源纹波

## 常见错误代码

| 错误码 | 含义 | 可能原因 |
|---|---|---|
| -ENODEV (-19) | 设备不存在 | SPI1 未在设备树中启用 |
| -ETIMEDOUT (-110) | 超时 | Flash 未响应，硬件连接问题 |
| -EIO (-5) | I/O 错误 | SPI 通信失败 |
| -EINVAL (-22) | 参数无效 | 地址或长度错误 |

## 最小测试代码

如果以上都无法解决，可以使用以下最小测试代码:

```c
void test_spi_flash(void)
{
    const struct device *spi = DEVICE_DT_GET(DT_NODELABEL(spi1));
    if (!device_is_ready(spi)) {
        printk("SPI1 未就绪\n");
        return;
    }
    
    // 配置 CS 引脚
    const struct device *gpio = DEVICE_DT_GET(DT_NODELABEL(gpio0));
    gpio_pin_configure(gpio, 28, GPIO_OUTPUT_INACTIVE);
    
    // 读取 JEDEC ID
    struct spi_config cfg = {
        .frequency = 1000000,  // 1MHz
        .operation = SPI_OP_MODE_MASTER | SPI_WORD_SET(8) | SPI_TRANSFER_MSB,
    };
    
    uint8_t tx[4] = {0x9F, 0xFF, 0xFF, 0xFF};
    uint8_t rx[4] = {0};
    
    struct spi_buf tx_buf = {.buf = tx, .len = 4};
    struct spi_buf rx_buf = {.buf = rx, .len = 4};
    struct spi_buf_set tx_set = {.buffers = &tx_buf, .count = 1};
    struct spi_buf_set rx_set = {.buffers = &rx_buf, .count = 1};
    
    gpio_pin_set(gpio, 28, 0);  // CS 拉低
    int ret = spi_transceive(spi, &cfg, &tx_set, &rx_set);
    gpio_pin_set(gpio, 28, 1);  // CS 拉高
    
    printk("SPI 返回: %d, ID: %02X %02X %02X\n", ret, rx[1], rx[2], rx[3]);
}
```

## 修改记录

### 2024-02-14
1. 将 SPI 频率从 8MHz 降低到 4MHz
2. 在 overlay 中添加 W25Q64 设备节点
3. 增加详细的调试日志输出
4. 添加 SPI 设备名称和状态检查

## 下一步

如果问题仍未解决，请提供:
1. 完整的串口日志输出
2. 硬件原理图 (SPI 部分)
3. 使用的 Flash 芯片型号和批次
4. 逻辑分析仪捕获的 SPI 波形 (如果有)

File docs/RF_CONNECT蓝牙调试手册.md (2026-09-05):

# RF CONNECT 手机端蓝牙调试手册

## 目录

1. [应用介绍](#1-应用介绍)
2. [设备扫描与连接](#2-设备扫描与连接)
3. [时间同步服务](#3-时间同步服务)
4. [配置服务](#4-配置服务)
5. [温湿度服务](#5-温湿度服务)
6. [数据格式说明](#6-数据格式说明)
7. [常见问题排查](#7-常见问题排查)
8. [附录：完整UUID列表](#8附录完整uuid列表)

---

## 1. 应用介绍

### 1.1 关于 RF CONNECT

**RF CONNECT** 是 Nordic Semiconductor 官方提供的蓝牙低功耗（BLE）调试工具，支持 Android 和 iOS 平台。本手册介绍如何使用 RF CONNECT 调试 **E104-BT5010A 蓝牙温湿度采集设备**。

### 1.2 设备信息

- **设备名称**: `yodfz-temp`
- **设备类型**: BLE 外设（Peripheral）
- **芯片平台**: nRF52810
- **通讯协议**: BLE GATT (Generic Attribute Profile)

### 1.3 应用下载

- **Android**: 在 Google Play 搜索 "nRF Connect" 或访问 [Nordic 官网](https://www.nordicsemi.com/Software-and-tools/Development-Tools/nRF-Connect-for-mobile)
- **iOS**: 在 App Store 搜索 "nRF Connect"

---

## 2. 设备扫描与连接

### 2.1 启动扫描

1. 打开 **RF CONNECT** 应用
2. 点击右上角的 **"SCAN"** 按钮（或底部导航栏的扫描图标）
3. 应用开始扫描附近的 BLE 设备

### 2.2 查找目标设备

在扫描结果列表中查找设备名称 **`yodfz-temp`**：

- **设备名称**: `yodfz-temp`
- **信号强度**: RSSI 值（通常为 -30 到 -90 dBm）
- **MAC 地址**: 显示设备的蓝牙 MAC 地址

**提示**：
- 如果设备未出现在列表中，请确保设备已上电并处于广播状态
- 设备在未连接时会持续广播，连接后停止广播
- 如果设备距离较远，信号强度会较弱（RSSI 值更负）

### 2.3 连接设备

1. 点击设备列表中的 **`yodfz-temp`** 设备
2. 应用会自动连接设备
3. 连接成功后，界面会显示设备的 **GATT 服务列表**

**连接状态指示**：
- **未连接**: LINK LED（P0.30）闪烁
- **已连接**: LINK LED（P0.30）常亮

---

## 3. 时间同步服务

### 3.1 服务信息

| 项目 | UUID | 说明 |
|---|---|---|
| **服务 UUID** | `12340010-1234-5678-1234-56789ABCDEF0` | 时间同步服务 |
| **时间特性 UUID** | `12340011-1234-5678-1234-56789ABCDEF0` | 可写，接收时间戳 |

### 3.2 操作步骤

#### 步骤 1: 找到时间同步服务

1. 连接设备后，在服务列表中找到 UUID 为 `12340010-1234-5678-1234-56789ABCDEF0` 的服务
2. 点击展开该服务，查看其特性列表

#### 步骤 2: 找到时间特性

在服务下找到 UUID 为 `12340011-1234-5678-1234-56789ABCDEF0` 的特性（Characteristic）

#### 步骤 3: 写入时间戳

1. 点击时间特性，进入特性详情页面
2. 点击 **"WRITE"** 或 **"↑"** 按钮
3. 在数据输入框中输入时间戳数据

**数据格式**：
- **格式**: 4 字节，小端序（Little Endian）
- **单位**: Unix 时间戳（秒，从 1970-01-01 00:00:00 UTC 起）
- **示例**: 当前时间 2024-01-01 00:00:00 UTC 对应时间戳 `1704067200`（十进制）

**输入方式**：
- **方式 1（十六进制）**: 输入 `00 C8 A8 65`（小端序，对应时间戳 1704067200）
- **方式 2（十进制）**: 部分应用支持直接输入十进制时间戳

**时间戳计算工具**：
- 在线工具: https://www.epochconverter.com/
- 命令行（Linux/Mac）: `date +%s`
- PowerShell（Windows）: `[int][double]::Parse((Get-Date -UFormat %s))`

#### 步骤 4: 确认写入

1. 确认数据格式正确后，点击 **"SEND"** 或 **"WRITE"** 按钮
2. 如果写入成功，设备会：
   - 在串口输出时间同步成功信息
   - DATA LED（P0.31）闪烁 3 次，表示时间同步成功

### 3.3 验证时间同步

**方法 1**: 查看设备串口输出
- 连接串口调试工具（115200 波特率）
- 查看是否有 `[时间同步] 成功！时间戳: xxx` 的输出

**方法 2**: 读取设备状态
- 通过配置服务的状态特性查看时间同步状态（见第 4 节）

---

## 4. 配置服务

### 4.1 服务信息

| 项目 | UUID | 说明 |
|---|---|---|
| **服务 UUID** | `12340020-1234-5678-1234-56789ABCDEF0` | 配置服务 |
| **采集间隔特性 UUID** | `12340021-1234-5678-1234-56789ABCDEF0` | 可读/可写 |
| **当前状态特性 UUID** | `12340022-1234-5678-1234-56789ABCDEF0` | 可读/可通知 |

### 4.2 采集间隔特性操作

#### 读取采集间隔

1. 在配置服务下找到 UUID 为 `12340021-1234-5678-1234-56789ABCDEF0` 的特性
2. 点击特性，进入详情页面
3. 点击 **"READ"** 或 **"↓"** 按钮
4. 应用会显示当前采集间隔值

**数据格式**：
- **格式**: 2 字节，小端序（Little Endian）
- **单位**: 秒
- **范围**: 10 ~ 3600 秒
- **默认值**: 30 秒

**示例**：
- 读取值 `1E 00`（十六进制） = 30（十进制）秒
- 读取值 `3C 00`（十六进制） = 60（十进制）秒

#### 设置采集间隔

1. 点击采集间隔特性，进入详情页面
2. 点击 **"WRITE"** 或 **"↑"** 按钮
3. 在数据输入框中输入新的采集间隔值

**输入格式**：
- **方式 1（十六进制）**: 输入 `3C 00`（表示 60 秒，小端序）
- **方式 2（十进制转十六进制）**: 
  - 30 秒 → `1E 00`
  - 60 秒 → `3C 00`
  - 300 秒（5分钟）→ `2C 01`
  - 3600 秒（1小时）→ `10 0E`

**注意事项**：
- 必须使用小端序（低字节在前）
- 值必须在 10 ~ 3600 秒范围内
- 写入成功后，设备会立即应用新配置并保存到 Flash

### 4.3 当前状态特性操作

#### 读取当前状态

1. 在配置服务下找到 UUID 为 `12340022-1234-5678-1234-56789ABCDEF0` 的特性
2. 点击特性，进入详情页面
3. 点击 **"READ"** 或 **"↓"** 按钮
4. 应用会显示当前状态数据

**数据格式**（6 字节）：
- **字节 0-1**: 采集间隔（uint16_t，小端序，单位：秒）
- **字节 2-3**: 记录数（uint16_t，小端序）
- **字节 4**: 系统状态（bit0=连接状态，bit1=时间同步状态）
  - `0x01`: 已连接
  - `0x02`: 时间已同步
  - `0x03`: 已连接且时间已同步
- **字节 5**: 保留（通常为 `0x00`）

**示例解析**：
```
数据: 1E 00 64 00 03 00
解析:
- 采集间隔: 1E 00 = 30 秒
- 记录数: 64 00 = 100
- 系统状态: 03 = 0b00000011 = 已连接(bit0) + 时间已同步(bit1)
- 保留: 00
```

#### 订阅状态通知

1. 点击状态特性，进入详情页面
2. 找到 **CCC (Client Characteristic Configuration)** 描述符
   - UUID: `00002902-0000-1000-8000-00805f9b34fb`
3. 点击 CCC 描述符，进入详情页面
4. 点击 **"WRITE"** 按钮
5. 输入 `01 00`（启用通知）或 `00 00`（禁用通知）
6. 点击 **"SEND"** 确认

**启用通知后**：
- 设备状态发生变化时（如采集间隔更新、记录数增加），会自动推送通知
- 应用会实时显示最新的状态数据

---

## 5. 温湿度服务

### 5.1 服务信息

| 项目 | UUID | 说明 |
|---|---|---|
| **服务 UUID** | `12340001-1234-5678-1234-56789ABCDEF0` | 温湿度服务 |
| **温度特性 UUID** | `12340002-1234-5678-1234-56789ABCDEF0` | 可读/可通知 |
| **湿度特性 UUID** | `12340003-1234-5678-1234-56789ABCDEF0` | 可读/可通知 |

### 5.2 温度特性操作

#### 读取温度值

1. 在温湿度服务下找到 UUID 为 `12340002-1234-5678-1234-56789ABCDEF0` 的特性
2. 点击特性，进入详情页面
3. 点击 **"READ"** 或 **"↓"** 按钮
4. 应用会显示当前温度值

**数据格式**：
- **格式**: 2 字节，小端序（Little Endian）
- **类型**: int16_t（有符号整数）
- **单位**: 0.01°C（实际值 = 读取值 / 100）
- **范围**: -4000 ~ 8500（对应 -40.00°C ~ 85.00°C）

**示例解析**：
```
读取值: 93 09 (十六进制)
转换为十进制: 0x0993 = 2451
实际温度: 2451 / 100 = 24.51°C
```

#### 订阅温度通知

1. 点击温度特性，进入详情页面
2. 找到 **CCC 描述符**（UUID: `00002902-0000-1000-8000-00805f9b34fb`）
3. 点击 CCC 描述符，写入 `01 00` 启用通知
4. 启用后，设备会按照采集间隔自动推送温度数据

**通知频率**：
- 默认每 30 秒推送一次（可在配置服务中修改采集间隔）
- 每次推送时，DATA LED（P0.31）会短暂闪烁

### 5.3 湿度特性操作

#### 读取湿度值

1. 在温湿度服务下找到 UUID 为 `12340003-1234-5678-1234-56789ABCDEF0` 的特性
2. 点击特性，进入详情页面
3. 点击 **"READ"** 或 **"↓"** 按钮
4. 应用会显示当前湿度值

**数据格式**：
- **格式**: 2 字节，小端序（Little Endian）
- **类型**: uint16_t（无符号整数）
- **单位**: 0.01%（实际值 = 读取值 / 100）
- **范围**: 0 ~ 10000（对应 0.00% ~ 100.00%）

**示例解析**：
```
读取值: 94 19 (十六进制)
转换为十进制: 0x1994 = 6548
实际湿度: 6548 / 100 = 65.48%
```

#### 订阅湿度通知

1. 点击湿度特性，进入详情页面
2. 找到 **CCC 描述符**，写入 `01 00` 启用通知
3. 启用后，设备会按照采集间隔自动推送湿度数据

---

## 6. 数据格式说明

### 6.1 字节序说明

**所有数据均使用小端序（Little Endian）**，即低字节在前，高字节在后。

**示例**：
- 十进制 30 → 十六进制 `0x001E` → 小端序字节序列 `1E 00`
- 十进制 60 → 十六进制 `0x003C` → 小端序字节序列 `3C 00`
- 十进制 1704067200 → 十六进制 `0x65A8C800` → 小端序字节序列 `00 C8 A8 65`

### 6.2 数据格式汇总表

| 特性 | 数据类型 | 字节数 | 单位 | 范围 | 示例 |
|---|---|---|---|---|---|
| 时间戳 | uint32_t | 4 | 秒 | 0 ~ 4294967295 | `00 C8 A8 65` = 1704067200 |
| 采集间隔 | uint16_t | 2 | 秒 | 10 ~ 3600 | `1E 00` = 30 |
| 记录数 | uint16_t | 2 | 条 | 0 ~ 65535 | `64 00` = 100 |
| 温度 | int16_t | 2 | 0.01°C | -4000 ~ 8500 | `93 09` = 24.51°C |
| 湿度 | uint16_t | 2 | 0.01% | 0 ~ 10000 | `94 19` = 65.48% |

### 6.3 数据转换工具

**在线工具**：
- Unix 时间戳转换: https://www.epochconverter.com/
- 十六进制转换: https://www.rapidtables.com/convert/number/hex-to-decimal.html

**命令行工具**：
```bash
# 获取当前 Unix 时间戳（Linux/Mac）
date +%s

# 获取当前 Unix 时间戳（Windows PowerShell）
[int][double]::Parse((Get-Date -UFormat %s))

# 十六进制转十进制（Python）
python3 -c "print(0x1E00)"

# 十进制转十六进制（Python）
python3 -c "print(hex(30))"
```

---

## 7. 常见问题排查

### 7.1 扫描不到设备

**可能原因**：
1. 设备未上电或未启动
2. 设备距离过远
3. 手机蓝牙未开启
4. 应用权限不足（Android 6.0+ 需要位置权限）

**解决方法**：
1. 检查设备电源和串口输出，确认设备正常运行
2. 靠近设备（建议 1 米内）
3. 检查手机蓝牙设置，确保蓝牙已开启
4. 在手机设置中授予应用位置权限（Android）

### 7.2 连接失败

**可能原因**：
1. 设备已被其他设备连接（BLE 外设通常只支持一个连接）
2. 设备处于低功耗模式，广播间隔较长
3. 手机蓝牙栈问题

**解决方法**：
1. 断开其他设备的连接
2. 等待设备重新开始广播（可能需要几秒）
3. 重启手机蓝牙或重启应用

### 7.3 读取/写入失败

**可能原因**：
1. 数据格式错误（字节序、长度等）
2. 值超出允许范围
3. 特性权限不足

**解决方法**：
1. 检查数据格式，确保使用小端序
2. 验证值是否在允许范围内（如采集间隔 10~3600 秒）
3. 确认特性支持该操作（Read/Write）

### 7.4 通知不工作

**可能原因**：
1. CCC 描述符未正确配置
2. 通知未启用

**解决方法**：
1. 检查 CCC 描述符是否写入 `01 00`（启用通知）
2. 重新连接设备并重新配置通知

### 7.5 数据值异常

**可能原因**：
1. 字节序错误（使用了大端序）
2. 数据类型理解错误（有符号/无符号）

**解决方法**：
1. 确认使用小端序（低字节在前）
2. 温度使用有符号整数（int16_t），湿度使用无符号整数（uint16_t）

---

## 8. 附录：完整 UUID 列表

### 8.1 服务 UUID

| 服务名称 | UUID | 说明 |
|---|---|---|
| 时间同步服务 | `12340010-1234-5678-1234-56789ABCDEF0` | 用于时间同步 |
| 配置服务 | `12340020-1234-5678-1234-56789ABCDEF0` | 用于设备配置 |
| 温湿度服务 | `12340001-1234-5678-1234-56789ABCDEF0` | 用于温湿度数据 |

### 8.2 特性 UUID

| 特性名称 | UUID | 服务 | 权限 |
|---|---|---|---|
| 时间特性 | `12340011-1234-5678-1234-56789ABCDEF0` | 时间同步服务 | Write |
| 采集间隔特性 | `12340021-1234-5678-1234-56789ABCDEF0` | 配置服务 | Read/Write |
| 当前状态特性 | `12340022-1234-5678-1234-56789ABCDEF0` | 配置服务 | Read/Notify |
| 温度特性 | `12340002-1234-5678-1234-56789ABCDEF0` | 温湿度服务 | Read/Notify |
| 湿度特性 | `12340003-1234-5678-1234-56789ABCDEF0` | 温湿度服务 | Read/Notify |

### 8.3 标准描述符 UUID

| 描述符名称 | UUID | 说明 |
|---|---|---|
| CCC (Client Characteristic Configuration) | `00002902-0000-1000-8000-00805f9b34fb` | 用于启用/禁用通知 |

---

## 9. 快速参考

### 9.1 常用操作流程

**首次连接并配置设备**：
1. 扫描并连接 `yodfz-temp` 设备
2. 同步时间（写入时间戳到时间特性）
3. 读取当前采集间隔
4. 根据需要修改采集间隔
5. 订阅温湿度通知
6. 订阅状态通知

**日常监控**：
1. 连接设备
2. 订阅温湿度通知（自动接收数据）
3. 查看实时温湿度值

### 9.2 数据格式速查

| 操作 | 输入格式 | 示例 |
|---|---|---|
| 设置采集间隔 60 秒 | 2 字节，小端序 | `3C 00` |
| 设置采集间隔 300 秒 | 2 字节，小端序 | `2C 01` |
| 同步时间（2024-01-01 00:00:00） | 4 字节，小端序 | `00 C8 A8 65` |
| 启用通知 | 2 字节 | `01 00` |
| 禁用通知 | 2 字节 | `00 00` |

---

**文档版本**: v1.0  
**最后更新**: 2024-01-01  
**适用设备**: E104-BT5010A (nRF52810)  
**适用应用**: RF CONNECT (Nordic Semiconductor)

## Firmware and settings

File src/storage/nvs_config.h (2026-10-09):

/**
 * @file nvs_config.h
 * @brief NVS 配置管理头文件
 */

#ifndef STORAGE_NVS_CONFIG_H_
#define STORAGE_NVS_CONFIG_H_

#include <zephyr/kernel.h>
#include <zephyr/fs/nvs.h>
#include <zephyr/app_version.h>
#include <limits.h>

#ifdef __cplusplus
extern "C" {
#endif

/* NVS 分区：offset/size 由 PM 生成的 nvs_storage 分区提供。 */
#define NVS_SECTOR_SIZE       4096

/* NVS key 定义 */
#define NVS_ID_NEXT_SECTOR    1
#define NVS_ID_OLDEST_SECTOR  2
#define NVS_ID_NEXT_RECORD    3
#define NVS_ID_CONFIG         4
#define NVS_ID_TIME_BASE      5
#define NVS_ID_HISTORY_RETENTION 7
#define NVS_ID_OTA            6   /* OTA 断点续传状态（offset / total / ih_ver / valid） */

/* ================== 版本号：唯一来源是工程根的 VERSION 文件 ==================
 *
 * Zephyr 在 `${APPLICATION_SOURCE_DIR}/VERSION` 存在时会：
 *   ① 生成 `app_version.h`（APP_VERSION_MAJOR / APP_PATCHLEVEL / APP_VERSION_STRING …）
 *   ② 把 `CONFIG_MCUBOOT_IMGTOOL_SIGN_VERSION` 的默认值设为 `APP_VERSION_TWEAK_STRING`
 *      （即 "1.0.4+0"），从而交给 imgtool `--version` 去签镜像。
 * 所以：**改版本只改 VERSION 文件**，不要再手改这里的常量、也不要手改 prj.conf 里的
 * CONFIG_MCUBOOT_IMGTOOL_SIGN_VERSION —— 那正是"镜像版本号恒为 0.0.0+0"事故的根源。
 *
 * FIRMWARE_VERSION 沿用历史约定：NVS 里存的是**补丁号**（v4=1.0.3 → 3，v5=1.0.4 → 4）。
 * 只跟到 PATCHLEVEL 是刻意的：MAJOR/MINOR 变更属于跨代不兼容，届时需另行走 NVS 布局迁移，
 * 不应悄悄改掉这个字段的语义。
 */
#ifndef APP_PATCHLEVEL
#error "缺少 app_version.h（由工程根 VERSION 文件生成）。请确认 VERSION 文件存在且已重新构建。"
#endif
#define FIRMWARE_VERSION          APP_PATCHLEVEL
#define FIRMWARE_VERSION_STRING   APP_VERSION_STRING

/*
 * 采样周期与历史记录周期已解耦（D-2，2026-09-11）
 * ---------------------------------------------------------------------------
 * sample_interval  —— 传感器采样 / 实时 BLE 显示 / 最高最低温度跟踪。**固定 1 秒，不可配置**。
 * history_interval —— 历史记录落盘周期：每积累 history_interval 个采样点，取算术平均写入
 *                     W25Q64 一条 12 字节记录。默认 60 秒，可由 BLE 特性 12340021 配置。
 *
 * 容量口径（每条记录 12 B，每扇区 336 条，上限 W25Q64_MAX_RECORDS = 65000 条）：
 *   60 秒  -> 65,000 × 60  / 86400 = 45.1 天   （产品承诺 30 天，余量 33%）
 *   30 秒  -> 22.6 天（**不足 30 天，故下限锁死在 60 秒**）
 *   300 秒 -> 225.7 天
 * MIN_HISTORY_INTERVAL 取 60 是**容量红线**，不是性能取舍：低于它就无法兑现 30 天保留承诺。
 */
#define SAMPLE_INTERVAL_FIXED    1     /* 采样固定 1 秒 */
#define DEFAULT_HISTORY_INTERVAL 60    /* 历史记录默认 60 秒 */
#define MIN_HISTORY_INTERVAL     60    /* 下限：守住 30 天保留（见上方容量口径）*/
#define MAX_HISTORY_INTERVAL     3600  /* 上限 1 小时 */

/* 以下三个宏仅用于解析**旧格式** NVS 配置（v2 及更早，采样/历史共用一个周期），
 * 新格式不再使用 sample_interval 作为可配置项。 */
#define DEFAULT_SAMPLE_INTERVAL  1
#define MIN_SAMPLE_INTERVAL      1
#define MAX_SAMPLE_INTERVAL      3600

/* 配置数据结构（存储在Flash）—— 当前格式：18 字节 */
typedef struct {
	uint16_t sample_interval;            /* 采样间隔（秒），新固件恒为 SAMPLE_INTERVAL_FIXED */
	uint16_t history_interval;           /* 历史记录落盘间隔（秒），60~3600 */
	int16_t  max_temperature;            /* 最高温度（0.01°C）*/
	int16_t  min_temperature;            /* 最低温度（0.01°C）*/
	uint32_t max_temperature_timestamp;  /* 最高温度发生时间 */
	uint32_t min_temperature_timestamp;  /* 最低温度发生时间 */
	uint16_t firmware_version;           /* 固件版本号 */
} __packed device_config_t;

/* 旧格式（固件 v2，16 字节）：无 history_interval。
 * 必须显式建模，否则升级后 nvs_load_config() 会因长度不匹配而丢弃历史最高/最低温度。 */
typedef struct {
	uint16_t sample_interval;
	int16_t  max_temperature;
	int16_t  min_temperature;
	uint32_t max_temperature_timestamp;
	uint32_t min_temperature_timestamp;
	uint16_t firmware_version;
} __packed device_config_v2_t;

/* Independent atomic checkpoint; legacy position keys 1..3 are unchanged. */
#define HISTORY_RETENTION_MAGIC 0x48525431U
#define HISTORY_GC_DONE 0xffffU
typedef struct {
    uint32_t magic;
    uint16_t limit;
    uint16_t head_sector;
    uint16_t head_record;
    uint16_t first_sector;
    uint16_t first_record;
    uint16_t count;
    uint16_t gc_sector;
} __packed history_retention_t;
int nvs_load_history_retention(history_retention_t *retention);
int nvs_save_history_retention(const history_retention_t *retention);

/* 设备配置上下文 */
typedef struct {
	uint16_t sample_interval;
	uint16_t history_interval;
	int16_t  max_temperature;
	int16_t  min_temperature;
	uint32_t max_temperature_timestamp;
	uint32_t min_temperature_timestamp;
	uint16_t firmware_version;
	uint16_t record_count;
	bool     config_dirty;
	bool     position_dirty;
} device_config_ctx_t;

/* 存储位置上下文 */
typedef struct {
	uint16_t next_sector;
	uint16_t oldest_sector;
	uint16_t next_record_in_sector;
} storage_position_t;

/**
 * @brief 初始化 NVS
 * @return 0 成功，负数错误码
 */
int nvs_config_init(void);

/**
 * @brief 检查 NVS 是否就绪
 * @return true 已就绪，false 未就绪
 */
bool nvs_config_is_ready(void);

/**
 * @brief 从 NVS 加载存储位置
 * @param pos 存储位置输出
 */
void nvs_load_storage_position(storage_position_t *pos);

/**
 * @brief 保存存储位置到 NVS
 * @param pos 存储位置
 */
void nvs_save_storage_position(const storage_position_t *pos);

/**
 * @brief 清空存储位置信息
 */
void nvs_clear_storage_position(void);

/**
 * @brief 从 NVS 加载时间基准
 * @param timestamp 时间戳输出
 * @param time_synced 时间同步状态输出
 */
void nvs_load_time(uint32_t *timestamp, bool *time_synced);

/**
 * @brief 保存时间到 NVS
 * @param timestamp 时间戳
 * @return 0 成功，负数错误码
 */
int nvs_save_time(uint32_t timestamp);

/**
 * @brief 从 NVS 加载设备配置
 * @param config 配置输出
 */
void nvs_load_config(device_config_ctx_t *config);

/**
 * @brief 保存设备配置到 NVS
 * @param config 配置
 * @param immediate true 立即保存，false 延迟保存
 */
void nvs_save_config(device_config_ctx_t *config, bool immediate);

/**
 * @brief 刷新 NVS（保存脏数据）
 * @param config 配置上下文
 * @param pos 存储位置
 */
void nvs_flush(device_config_ctx_t *config, const storage_position_t *pos);

/**
 * @brief 获取 NVS 文件系统指针
 * @return NVS 文件系统指针
 */
struct nvs_fs *nvs_get_fs(void);

#ifdef __cplusplus
}
#endif

#endif /* STORAGE_NVS_CONFIG_H_ */

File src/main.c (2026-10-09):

/*
 * 参考 RIOT-2020.10-RC3 的 E104-BT5010A 板级配置实现蓝牙温度计程序
 * 
 * 重要配置说明（参考 periph_conf.h）：
 * - 时钟配置：E104-BT5010A 模块没有外部晶振，必须使用内部 RC 振荡器
 *   在 prj.conf 中已配置：
 *   CONFIG_CLOCK_CONTROL_NRF_K32SRC_RC=y  (使用内部 RC 作为 32kHz 时钟源)
 *   这确保系统不会因等待外部晶振起振而卡死
 * 
 * - LED 配置：DATA LED: P0.4, LINK LED: P0.5
 *   LED 为低电平有效（低电平点亮，高电平熄灭）
 *   DATA LED 用于指示数据状态
 *   LINK LED 用于指示蓝牙连接状态
 */

#include <zephyr/kernel.h>
#include <zephyr/sys/printk.h>
#include <zephyr/sys/util.h>
#include <zephyr/sys/byteorder.h>
#include <string.h>
#include <limits.h>
#include <hal/nrf_gpio.h>
#include <hal/nrf_twim.h>
#include <zephyr/bluetooth/bluetooth.h>
#include <zephyr/bluetooth/conn.h>
#include <zephyr/bluetooth/gap.h>
#include <zephyr/bluetooth/uuid.h>
#include <zephyr/bluetooth/hci.h>
#include <zephyr/bluetooth/gatt.h>
#include <zephyr/drivers/i2c.h>
#include <zephyr/drivers/flash.h>
#include <zephyr/drivers/spi.h>
#include <zephyr/drivers/gpio.h>
#include <zephyr/fs/nvs.h>
#include <zephyr/storage/flash_map.h>
// PM 设备电源管理（用于I2C低功耗控制）
#include <zephyr/pm/device.h>

#include <zephyr/device.h>

/* 拆分模块头文件 */
#include "common.h"
#include "sensors/aht30.h"
#include "sensors/spl06.h"
#include "storage/w25q64.h"
#include "storage/nvs_config.h"
#include "storage/history_codec.h"
#include "ble/ble_adv.h"
#include "ble/ble_services.h"
#include "ble/ble_ota.h"
#include "led.h"
#include "vdd.h"

// RAM Buffer Definitions
// 注意：RAM_BUFFER_SIZE 由 common.h 统一定义（此处曾重复定义，属"同一宏两处定义"，已清理）。
// 语义变更（D-2）：本缓冲区**不再是"攒满一批再写"的批量缓冲**，而是 Flash 临时失败后的**重试区**；
// 正常情况下每形成一条历史记录就立即落盘，缓冲区随即清空。
static struct data_record ram_buffer[RAM_BUFFER_SIZE];
static uint8_t ram_buffer_count = 0;

// 前向声明
static void history_send_work_handler(struct k_work *work);

// UUID 宏定义使用 ble/ble_services.h 中的版本
// UUID 结构体变量（用于 BT_GATT_SERVICE_DEFINE）
static struct bt_uuid_128 time_sync_char_uuid = BT_UUID_INIT_128(BT_UUID_TIME_SYNC_CHAR_VAL);

static struct bt_uuid_128 config_service_uuid = BT_UUID_INIT_128(BT_UUID_CONFIG_SERVICE_VAL);
static struct bt_uuid_128 interval_char_uuid = BT_UUID_INIT_128(BT_UUID_INTERVAL_CHAR_VAL);
static struct bt_uuid_128 status_char_uuid = BT_UUID_INIT_128(BT_UUID_STATUS_CHAR_VAL);
static struct bt_uuid_128 history_char_uuid = BT_UUID_INIT_128(BT_UUID_HISTORY_CHAR_VAL);
static struct bt_uuid_128 temp_range_char_uuid = BT_UUID_INIT_128(BT_UUID_TEMP_RANGE_CHAR_VAL);
static struct bt_uuid_128 temp_range_reset_char_uuid = BT_UUID_INIT_128(BT_UUID_TEMP_RANGE_RESET_CHAR_VAL);
static struct bt_uuid_128 history_info_char_uuid = BT_UUID_INIT_128(BT_UUID_HISTORY_INFO_CHAR_VAL);
static struct bt_uuid_128 realtime_service_uuid = BT_UUID_INIT_128(BT_UUID_REALTIME_SERVICE_VAL);
static struct bt_uuid_128 realtime_char_uuid = BT_UUID_INIT_128(BT_UUID_REALTIME_CHAR_VAL);
static struct bt_uuid_128 clear_data_service_uuid = BT_UUID_INIT_128(BT_UUID_CLEAR_DATA_SERVICE_VAL);
static struct bt_uuid_128 clear_data_char_uuid = BT_UUID_INIT_128(BT_UUID_CLEAR_DATA_CHAR_VAL);

// I2C 设备（供传感器模块使用）
static const struct device *i2c_dev;

// 蓝牙连接状态
static bool bt_connected = false;
static bool bt_ready = false;  // 蓝牙是否就绪

// 时间同步相关变量
static uint32_t time_base_timestamp = 0;  // 基准时间戳（Unix 时间戳，秒）
static int64_t time_base_uptime = 0;      // 基准时间对应的系统运行时间（毫秒）
static bool time_synced = false;           // 时间是否已同步（含从 NVS 恢复的旧时间）
/* 时间基准是否来自**本次上电的手机对时**（决定是否按墙钟边界结算、是否对外宣称对齐）。
 * 仅从 NVS 恢复的旧时间不满足：设备停机期间秒数停走，恢复出来的时间必然偏慢，
 * 此时若仍按整分网格结算，会造出"看起来权威但绝对时刻是错的"时间戳。
 * 故只做严格等间隔（v6 行为），不宣称落在 :00 —— 见 §12.9。 */
static bool wall_clock_aligned = false;

// 配置相关变量
// FIRMWARE_VERSION / SAMPLE_INTERVAL_FIXED / DEFAULT_HISTORY_INTERVAL / MIN|MAX_HISTORY_INTERVAL
// 统一定义在 storage/nvs_config.h（此处曾重复定义同一批宏，已清理，避免"文档与实现不一致"）。
static uint16_t sample_interval = SAMPLE_INTERVAL_FIXED;      // 采样周期：固定 1 秒（实时显示 + 最高最低温度）
static uint16_t history_interval = DEFAULT_HISTORY_INTERVAL;  // 历史记录落盘周期（秒），60~3600，BLE 可配
static uint16_t record_count = 0;  // 已落盘记录计数（诊断用；对外以 storage_get_total_records() 为准）
static int16_t max_temperature = INT16_MIN;  // 最高温度（0.01°C），初始化为最小值
static int16_t min_temperature = INT16_MAX;  // 最低温度（0.01°C），初始化为最大值
static uint32_t max_temperature_timestamp = 0;  // 最高温度发生时间（Unix时间戳，秒）
static uint32_t min_temperature_timestamp = 0;  // 最低温度发生时间（Unix时间戳，秒）
static uint16_t firmware_version = FIRMWARE_VERSION;  // 固件版本号
static struct k_timer sample_timer;  // 采集定时器
static struct k_work sample_work;  // 采集工作队列
static struct k_work_delayable sample_start_work;  // 首次采集启动延迟工作队列
static struct k_work_delayable config_save_work;  // 配置延迟保存工作队列
static bool config_dirty = false;  // 配置是否已修改但未保存

// ========== 历史记录聚合状态（1 秒采样 -> history_interval 一条均值记录）==========
// 三个通道**独立累加**：某个传感器（尤其气压）故障时，其余通道仍能正常成记录。
// 这是对原实现的修正：原代码气压读失败时写 0，随后又被"气压范围校验"整条丢弃，
// 结果是气压传感器一坏就完全不落盘。
static int32_t  acc_temp_sum;      // 窗口内温度累加（0.01°C）
static uint32_t acc_hum_sum;       // 窗口内湿度累加（0.01%RH）
static uint32_t acc_press_sum;     // 窗口内气压累加（Pa）
static uint16_t acc_temp_n;        // 温度有效样本数
static uint16_t acc_hum_n;         // 湿度有效样本数
static uint16_t acc_press_n;       // 气压有效样本数
static uint16_t window_ticks;      // 窗口内**实际聚合到**的采样节拍数（诊断用；不再是结算依据）
static uint32_t window_deadline_ms;  // 本窗口的结算时刻（uptime ms，绝对网格；回绕安全）
/* 本窗口结算后要写入记录的**墙钟边界时间戳**（interval 的整数倍）。
 * 仅当 wall_clock_aligned 为真时有效；否则为 0，记录时间戳退回"结算时刻的真实秒"。
 * 周期记录用边界值而不是"实际执行完成的时刻"——后者会带 0~1 秒的执行抖动。 */
static uint32_t window_boundary_ts;
static uint32_t last_valid_pressure_pa;  // 最近一次有效气压（气压通道故障时的回退值）
static uint32_t dropped_records;   // Flash 持续失败导致丢弃的记录数（诊断用）

// 事件记录（突变/越限）判定基准
static int16_t  last_record_temp;  // 上一条已落盘记录的温度
static uint16_t last_record_hum;   // 上一条已落盘记录的湿度
static uint32_t last_record_ts;    // 上一条已落盘记录的时间戳
static bool     last_record_valid; // 是否已有可比对的基准记录
static uint8_t  alarm_state;       // 0=正常，1=越限（用于边沿触发）
static uint32_t last_event_uptime_ms;  // 上一条事件记录的时刻（uptime，免疫对时跳变）
static bool     last_event_seen;       // 是否已发过事件记录（限流基准是否有效）
static uint8_t  event_pending_kind;    // 被限流挡下、待补发的事件类型（见 EVENT_KIND_*）

// 写头持久化：storage_write_batch() 发生扇区切换时置位
static bool sector_switched_flag;

// 清空数据控制标志位
static bool data_clear_in_progress = false;  // 清空数据进行中标志，用于停止采集和存储

// 历史数据传输相关变量
static struct k_work_delayable history_send_work;
static bool history_transfer_active = false;
static uint16_t history_transfer_sector = 0;      // 当前传输扇区
static uint16_t history_transfer_record_idx = 0; // 当前扇区内的记录索引
static const struct bt_gatt_attr *history_char_attr = NULL;
static uint32_t history_start_timestamp = 0;  // 起始时间戳（0表示发送全部数据）
static bool history_binary_search_done = false;   // 二分查找是否已完成
static uint32_t history_total_sent_packets = 0;   // 累计发送包数
static uint32_t history_total_sent_records = 0;   // 累计发送记录数
static uint32_t history_expected_records = 0;     // 预期发送总记录数（用于进度显示）
static uint32_t history_last_sent_timestamp = 0;  // 上一条发送记录的时间戳（用于检测跨包乱序）
static uint32_t history_skipped_invalid = 0;      // 跳过的无效记录数（用于统计）
static uint32_t history_skipped_filtered = 0;     // 时间戳过滤跳过的记录数
// 历史数据通知发送控制（使用 bt_gatt_notify_cb 做“发完再发”流控）
static struct bt_gatt_notify_params history_notify_params;
static bool history_sending = false;                      // 是否有在途的历史通知
static uint8_t history_wire_size = 12U;
static uint8_t history_tx_buf[60];                        // 历史数据发送缓冲区（需保持到回调结束）

// W25Q64存储管理变量（提前声明，供history_char_ccc_cfg_changed使用）
static uint16_t next_sector = 0;      // 下一个写入扇区
static uint16_t oldest_sector = 0;    // 最旧扇区
static uint16_t next_record_in_sector = 0;  // 当前扇区内的记录索引

// 统一的历史总记录数计算函数（基于存储位置推算可读记录数）
static uint32_t storage_physical_count(void)
{
	// 无论是否环形覆盖，总是从 oldest_sector 开始写到 next_sector:next_record_in_sector
	if (next_sector == oldest_sector) {
		// 所有数据都在同一个扇区，或完全为空（next_record_in_sector == 0）
		return next_record_in_sector;
	}

	uint16_t sector_count;
	if (next_sector > oldest_sector) {
		sector_count = next_sector - oldest_sector;
	} else {
		// 环形情况：数据范围 [oldest_sector, MAX) + [0, next_sector)
		sector_count = W25Q64_MAX_SECTORS_LIMIT - oldest_sector + next_sector;
	}

	// 有效记录数 = 完整扇区数 * 每扇区容量 + 写入扇区内的记录数
	return (uint32_t)sector_count * W25Q64_RECORDS_PER_SECTOR + next_record_in_sector;
}

/* A separate atomic NVS checkpoint protects the logical window before reclamation. */
static history_retention_t retention;
static struct k_work_delayable retention_work;
static bool retention_busy;
static uint8_t retention_phase;
static uint16_t retention_prefix;
static uint32_t retention_scan_cursor;
static uint32_t retention_scan_remaining;
#define HISTORY_SLOT_COUNT (W25Q64_MAX_SECTORS_LIMIT * W25Q64_RECORDS_PER_SECTOR)
BUILD_ASSERT(sizeof(struct data_record) == W25Q64_RECORD_SIZE);
BUILD_ASSERT(sizeof(history_tx_buf) >= 4U * 14U);

static uint32_t storage_get_total_records(void)
{
    return retention.limit ? retention.count : storage_physical_count();
}
static uint16_t storage_first_record(void)
{
    return retention.limit ? retention.first_record : 0U;
}
static uint32_t storage_record_address(uint32_t slot)
{
    uint32_t sector = slot / W25Q64_RECORDS_PER_SECTOR;
    uint32_t record = slot % W25Q64_RECORDS_PER_SECTOR;
    return W25Q64_STORAGE_BASE + sector * W25Q64_SECTOR_SIZE +
        (record / W25Q64_RECORDS_PER_PAGE) * W25Q64_PAGE_SIZE +
        (record % W25Q64_RECORDS_PER_PAGE) * W25Q64_RECORD_SIZE;
}
static uint32_t storage_head_slot(void)
{
    return ((uint32_t)next_sector * W25Q64_RECORDS_PER_SECTOR +
            next_record_in_sector) % HISTORY_SLOT_COUNT;
}
static bool storage_valid_record(const struct data_record *record)
{
    uint32_t pressure;
    uint16_t voltage;
    return record->timestamp > 0U && record->timestamp <= 4102444800U &&
        record->temperature >= -5000 && record->temperature <= 15000 &&
        record->humidity <= 10000U &&
        history_decode_pressure(record->pressure_pa, &pressure, &voltage);
}
static int retention_checkpoint(void)
{
    retention.magic = HISTORY_RETENTION_MAGIC;
    retention.head_sector = next_sector;
    retention.head_record = next_record_in_sector;
    return nvs_save_history_retention(&retention);
}
static void retention_scan_begin(void)
{
    retention_scan_cursor = storage_head_slot();
    retention_scan_remaining = storage_physical_count();
    retention.count = 0;
    retention.first_sector = next_sector;
    retention.first_record = next_record_in_sector;
    if (retention.first_record == W25Q64_RECORDS_PER_SECTOR) {
        retention.first_sector = (next_sector + 1U) % W25Q64_MAX_SECTORS_LIMIT;
        retention.first_record = 0;
    }
}
/* At most 32 SPI reads per work slice; startup may call repeatedly before BLE starts. */
static int retention_scan_step(void)
{
    struct data_record record;
    for (unsigned n = 0; n < 32U && retention_scan_remaining &&
            retention.count < retention.limit; ++n) {
        uint32_t cursor = (retention_scan_cursor + HISTORY_SLOT_COUNT - 1U)
            % HISTORY_SLOT_COUNT;
        int ret = w25q64_read(storage_record_address(cursor),
                             (uint8_t *)&record, sizeof(record));
        if (ret) return ret;
        retention_scan_cursor = cursor;
        retention_scan_remaining--;
        if (storage_valid_record(&record)) {
            retention.count++;
            retention.first_sector = retention_scan_cursor / W25Q64_RECORDS_PER_SECTOR;
            retention.first_record = retention_scan_cursor % W25Q64_RECORDS_PER_SECTOR;
        }
    }
    return retention_scan_remaining && retention.count < retention.limit ? 1 : 0;
}
static const struct data_record erased_history_record; /* all-zero NOR tombstone */
static void retention_work_handler(struct k_work *work)
{
    ARG_UNUSED(work);
    int ret = 0;
    k_mutex_lock(w25q64_get_mutex(), K_FOREVER);
    if (retention_phase == 0U) {
        retention.limit = 3000U;
        retention.gc_sector = oldest_sector;
        retention_scan_begin();
        retention_phase = 1U;
    }
    if (retention_phase == 1U) {
        ret = retention_scan_step();
        if (ret == 1) { ret = 0; goto again; }
        if (ret) goto again;
        retention_phase = 2U;
    }
    if (retention_phase == 2U) {
        /* No destructive operation is permitted before this verified atomic write. */
        ret = retention_checkpoint();
        if (ret) goto again;
        oldest_sector = retention.first_sector;
        retention_prefix = 0;
        retention_scan_cursor = retention.gc_sector;
        retention_phase = 3U;
    }
    if (retention_phase == 3U) {
        if (retention_scan_cursor != retention.first_sector &&
                retention_scan_cursor != HISTORY_GC_DONE) {
            /* Only the old prefix is reclaimed; never erase the retained first/head sector. */
            if (retention_scan_cursor == next_sector) { ret = -EINVAL; goto again; }
            ret = w25q64_sector_erase(W25Q64_STORAGE_BASE +
                    retention_scan_cursor * W25Q64_SECTOR_SIZE);
            if (ret) goto again;
            retention_scan_cursor = (retention_scan_cursor + 1U) % W25Q64_MAX_SECTORS_LIMIT;
            goto again;
        }
        retention_phase = 4U;
    }
    if (retention_phase == 4U) {
        /* Partial first-sector prefix: 1->0 programming, no erase of retained records. */
        for (unsigned n = 0; n < 16U && retention_prefix < retention.first_record; ++n) {
            uint32_t slot = (uint32_t)retention.first_sector * W25Q64_RECORDS_PER_SECTOR + retention_prefix;
            ret = w25q64_page_program(storage_record_address(slot),
                    (const uint8_t *)&erased_history_record, sizeof(erased_history_record));
            if (ret) goto again;
            retention_prefix++;
        }
        if (retention_prefix < retention.first_record) goto again;
        retention.gc_sector = HISTORY_GC_DONE;
        retention_phase = 5U;
    }
    if (retention_phase == 5U) {
        ret = retention_checkpoint();
        if (ret) goto again;
        storage_position_t pos = {next_sector, oldest_sector, next_record_in_sector};
        nvs_save_storage_position(&pos); /* compatibility checkpoint; key 7 remains authoritative */
        retention_busy = false;
        printk("[历史保留] 完成 count=%u limit=%u first=%u:%u\r\n",
               retention.count, retention.limit, retention.first_sector, retention.first_record);
        k_mutex_unlock(w25q64_get_mutex());
        return;
    }
again:
    k_mutex_unlock(w25q64_get_mutex());
    if (ret < 0) printk("[历史保留] 重试: %d\r\n", ret);
    k_work_schedule(&retention_work, ret < 0 ? K_SECONDS(1) : K_MSEC(1));
}
static int retention_request(uint32_t limit)
{
    if (limit != 3000U) return -EINVAL;
    if (retention_busy || data_clear_in_progress || history_transfer_active ||
            ble_ota_in_progress()) return -EBUSY;
    /* The work runs on the same queue as sampling. There is no erase on the GATT thread. */
    retention_busy = true;
    retention_phase = 0U;
    k_work_schedule(&retention_work, K_NO_WAIT);
    return 0;
}
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
int main(void)
{
	// UART 已通过设备树（app.overlay）自动配置和初始化
	// 配置：P0.18 (TX), P0.14 (RX), 115200 波特率
	// 无需手动操作寄存器，Zephyr 驱动会自动处理
	// printk 会自动使用配置好的 UART 控制台输出
	
	// 立即输出测试信息，验证串口是否工作
	printk("\r\n\r\n");
	printk("=== 系统启动 ===\r\n");
	printk("[固件] 版本: %s（patch=%d，来自工程根 VERSION 文件）\r\n",
	       FIRMWARE_VERSION_STRING, FIRMWARE_VERSION);

	int err;
	
	// 初始化 LED 模块（使用 led.c 封装）
	// 低功耗优化：LED默认熄灭，只有蓝牙连接时才点亮
	led_init();
	
	// 在进行系统其它初始化（尤其是蓝牙、传感器）之前，
	// 先完成 W25Q64 存储的初始化和（可选的）启动强制擦除，
	// 确保强制擦除阶段不会有其它子系统并发访问存储。
	// NVS 初始化（配置 + W25Q64 位置，存芯片 FLASH）
	(void)nvs_config_init();
	load_config();

	/* OTA 服务的 GATT 是静态定义，这里只复位状态机。
	 * 必须放在 NVS 之后：断点续传状态要读写 NVS。 */
	ble_ota_init();

#ifdef CONFIG_ADC
	/* 电池电压：SAADC 内部 VDD 通道，零外部电路。
	 * 上电先采一次，手机连上后立刻就能看到电压（否则要等一个采样周期）。
	 * 此处仍在蓝牙启动之前 —— 避开 TX 突发导致的瞬时跌落，读数更接近静态电池电压。 */
	vdd_refresh();
#endif
	
	if (max_temperature != INT16_MIN) {
		printk("[配置] 当前最高温度: %d.%02d°C (时间戳: %u)\r\n",
		       max_temperature / 100, (max_temperature >= 0 ? max_temperature : -max_temperature) % 100,
		       max_temperature_timestamp);
	} else {
		printk("[配置] 最高温度未初始化，等待首次采集更新\r\n");
	}
	if (min_temperature != INT16_MAX) {
		printk("[配置] 当前最低温度: %d.%02d°C (时间戳: %u)\r\n",
		       min_temperature / 100, (min_temperature >= 0 ? min_temperature : -min_temperature) % 100,
		       min_temperature_timestamp);
	} else {
		printk("[配置] 最低温度未初始化，等待首次采集更新\r\n");
	}
	
    k_work_init_delayable(&retention_work, retention_work_handler);
	// 从 NVS 读取 W25Q64 位置，再 storage_init 里进行强制擦除/写头定位
	{
		storage_position_t pos = {0, 0, 0};
		nvs_load_storage_position(&pos);
		next_sector = pos.next_sector;
		oldest_sector = pos.oldest_sector;
		next_record_in_sector = pos.next_record_in_sector;
        if (nvs_load_history_retention(&retention) == 0 && retention.limit == 3000U &&
                retention.head_sector < W25Q64_MAX_SECTORS_LIMIT &&
                retention.head_record <= W25Q64_RECORDS_PER_SECTOR &&
                retention.first_sector < W25Q64_MAX_SECTORS_LIMIT &&
                retention.first_record < W25Q64_RECORDS_PER_SECTOR &&
                retention.count <= retention.limit &&
                (retention.gc_sector == HISTORY_GC_DONE || retention.gc_sector < W25Q64_MAX_SECTORS_LIMIT)) {
            next_sector = retention.head_sector;
            next_record_in_sector = retention.head_record;
            oldest_sector = retention.first_sector;
        } else {
            memset(&retention, 0, sizeof(retention));
        }
	}
	// 从 NVS 加载时间（如果之前已同步过）
	{
		uint32_t saved_timestamp;
		bool saved_time_synced;
		nvs_load_time(&saved_timestamp, &saved_time_synced);
		if (saved_time_synced) {
			time_base_timestamp = saved_timestamp;
			time_base_uptime = k_uptime_get();
			time_synced = true;
		}
		/* 无论恢复成功与否，都**不宣称**墙钟对齐：恢复出来的是上次对时的旧值，
		 * 停机期间秒数停走，它必然偏慢。要等**本次上电**收到手机对时才算可信
		 * （届时由 time_char_write_cb 置位并重算边界）。
		 * 在此之前周期记录退回"严格等间隔 + 真实秒"，不按整分网格造"看起来对齐"的时间戳。 */
		wall_clock_aligned = false;
	}
	int storage_err = storage_init();
	if (storage_err != 0) {
		printk("[系统] 严重错误: Flash 初始化失败 (%d)，系统停机\r\n", storage_err);
		// 持续快速闪烁 LED 指示故障
		while (1) {
			led_toggle(LED_MASK);
			k_msleep(100);
		}
	}
	// 注意：不再启动时统计历史记录，避免不必要的Flash读取
	// 历史数据可通过蓝牙连接后使用历史数据特性获取
	
	if (nvs_config_is_ready()) {
		k_timer_start(&nvs_flush_timer, K_SECONDS(30), K_SECONDS(30));
		printk("[NVS] 定时 flush 已启动 (30s)\r\n");
	}
	
	// 到这里为止，W25Q64 的强制清空（若启用 STORAGE_CLEAR_ON_BOOT）
	// 已经全部完成，下面再开始系统其它模块初始化。
	
	// 初始化采集定时器和工作队列（提前初始化，避免竞争条件）
	k_timer_init(&sample_timer, sample_timer_handler, NULL);
	k_work_init(&sample_work, sample_work_handler);
	k_work_init_delayable(&sample_start_work, sample_start_work_handler);
	
	// 广播工作队列已移至 ble_adv 模块
	k_work_init_delayable(&history_send_work, history_send_work_handler);
	k_work_init_delayable(&config_save_work, config_save_work_handler);
	k_work_init_delayable(&clear_data_work, clear_data_work_handler);
	// 预擦除工作队列在storage_init()中初始化
	
	// 发送测试消息
	printk("\r\n");
	printk("========================================\r\n");
	printk("蓝牙温度计程序启动 (参考 RIOT-2020.10-RC3)\r\n");
	printk("DATA LED: P0.%d, LINK LED: P0.%d\r\n", 31, 5);
	printk("设备名称: %s (启动后添加MAC后缀)\r\n", DEVICE_NAME_BASE);
	printk("========================================\r\n");
	
	// 低功耗优化：不再启动初始化闪烁，LED保持熄灭
	// led_start_init_blink();  // 已禁用
	
	// 初始化蓝牙（已禁用绑定，无需配对）
	err = bt_enable(bt_ready_cb);
	if (err) {
		printk("蓝牙使能失败 (错误码: %d)\r\n", err);
		return 0;
	}
	
	// 获取 I2C 设备
	i2c_dev = DEVICE_DT_GET(DT_NODELABEL(i2c0));
	if (!device_is_ready(i2c_dev)) {
		printk("I2C 设备未就绪\r\n");
	} else {
		printk("I2C 设备已就绪 (SDA: P0.7, SCL: P0.6)\r\n");
		i2c_scan_bus(i2c_dev);
	}
	
	// 初始化 AHT30 温湿度传感器
	err = aht30_init(i2c_dev);
	if (err) {
		printk("AHT30 初始化失败: %d\r\n", err);
	}
	
	// 初始化 SPL06-001 气压传感器
	err = spl06_init_ex(i2c_dev, false);
	if (err) {
		printk("SPL06-001 初始化失败: %d\r\n", err);
	}
	
	// 注意：采集任务将在蓝牙就绪后由 bt_ready_cb() 启动
	// 这样可以避免在蓝牙未初始化时访问 GATT 服务
	
	// 确保所有初始化完成后再进入主循环
	// 给系统一些时间完成所有异步初始化（如蓝牙初始化）
	k_msleep(200);
	
	printk("[系统] 初始化完成，进入主循环等待事件...\r\n");
	
	// 主循环 - 简化实现
	// 注意：CONFIG_PM=n 时不会进入深度睡眠，但功耗会略高
	// 使用 k_sleep() 让 CPU 进入空闲状态，由定时器和蓝牙中断唤醒
	int wait_count = 0;
	while (1) {
		if (!bt_ready) {
			wait_count++;
			if (wait_count % 3 == 0) { // 每30秒打印一次
				printk("[系统] 警告: 蓝牙尚未就绪，可能正在等待时钟 (RC振荡器校准)...\r\n");
			}
		}
		// 使用较长的睡眠时间，定时器或蓝牙中断会提前唤醒系统
		k_sleep(K_SECONDS(10));
	}
	
	return 0;
}

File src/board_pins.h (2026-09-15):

/**
 * @file board_pins.h
 * @brief E104-BT5010A 开发板引脚配置中心
 * 
 * 本文件集中定义所有 GPIO 引脚，便于硬件移植和维护
 * 
 * 硬件版本: E104-BT5010A (nRF52810)
 * 参考: RIOT-2020.10-RC3 boards/e104-bt5010a-tb
 */

#ifndef BOARD_PINS_H_
#define BOARD_PINS_H_

#ifdef __cplusplus
extern "C" {
#endif

/* ========== LED 指示灯引脚 ========== */
/* LED 为低电平有效（低电平点亮，高电平熄灭）*/
#define PIN_LED_DATA       4   /* P0.4 - 数据指示灯 */
#define PIN_LED_LINK       5    /* P0.5 - 蓝牙连接指示灯 */

/* ========== I2C0 传感器总线引脚 ========== */
/* 连接设备: AHT30/SHT40 温湿度传感器, SPL06 气压传感器, LTR-390UV 紫外线传感器 */
/* 配置在 overlay 文件中，此处仅作文档记录 */
#define PIN_I2C0_SCL       6   /* P0.6 - I2C 时钟线 */
#define PIN_I2C0_SDA       7   /* P0.7 - I2C 数据线 */

/* ========== UART0 调试串口引脚 ========== */
/* 配置在 overlay 文件中，此处仅作文档记录 */
#define PIN_UART0_TX       18  /* P0.18 - 串口发送 */
#define PIN_UART0_RX       14  /* P0.14 - 串口接收 */

/* ========== SPI0 Flash 存储引脚 ========== */
/* W25Q64 8MB SPI Flash，用于历史数据存储 */
/* SCK/MOSI/MISO 配置在 overlay 文件中，CS 由驱动控制 */
#define PIN_SPI0_CS        28  /* P0.28 - W25Q64 片选，低电平有效 */
#define PIN_SPI0_MISO      29  /* P0.29 - SPI 数据输出 */
#define PIN_SPI0_SCK       30  /* P0.30 - SPI 时钟 */
#define PIN_SPI0_MOSI      31  /* P0.31 - SPI 数据输入 */

/* ========== 引脚功能汇总表 ========== */
/*
 * GPIO  | 功能          | 方向 | 说明
 * ------|---------------|------|----------------------------------
 * P0.4  | DATA LED      | 输出 | 数据指示灯，低电平点亮
 * P0.5  | LINK LED      | 输出 | 蓝牙连接指示灯，低电平点亮
 * P0.6  | I2C0 SCL      | 双向 | I2C 时钟线（AHT30/SHT40/SPL06/LTR390）
 * P0.7  | I2C0 SDA      | 双向 | I2C 数据线（AHT30/SHT40/SPL06/LTR390）
 * P0.14 | UART0 RX      | 输入 | 串口接收（调试用）
 * P0.18 | UART0 TX      | 输出 | 串口发送（调试用）
 * P0.28 | W25Q64 CS     | 输出 | SPI Flash 片选，低电平有效
 * P0.29 | W25Q64 MISO   | 输入 | SPI Flash 数据输出
 * P0.30 | W25Q64 SCK    | 输出 | SPI Flash 时钟
 * P0.31 | W25Q64 MOSI   | 输出 | SPI Flash 数据输入
 */

/* ========== 硬件版本标识 ========== */
#define BOARD_NAME         "E104-BT5010A"
#define BOARD_VERSION      "1.1.3"
#define MCU_MODEL          "nRF52810"

#ifdef __cplusplus
}
#endif

#endif /* BOARD_PINS_H_ */

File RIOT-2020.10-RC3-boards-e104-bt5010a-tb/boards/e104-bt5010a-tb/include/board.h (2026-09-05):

/*
 * Copyright (C) 2020 Benjamin Valentin
 *
 * This file is subject to the terms and conditions of the GNU Lesser
 * General Public License v2.1. See the file LICENSE in the top level
 * directory for more details.
 */

/**
 * @ingroup     boards_e104-bt5010a-tb
 * @{
 *
 * @file
 * @brief       Board specific configuration for the E104-BT5010A Test Board
 *
 * @author      Benjamin Valentin <benpicco@googlemail.com>
 */

#ifndef BOARD_H
#define BOARD_H

#include "board_common.h"

#ifdef __cplusplus
extern "C" {
#endif

/**
 * @name    LED pin configuration
 * @{
 */
#define LED0_PIN            GPIO_PIN(0, 30)
#define LED1_PIN            GPIO_PIN(0, 31)

#define LED_PORT            (NRF_P0)
#define LED0_MASK           (1 << 30)
#define LED1_MASK           (1 << 31)
#define LED_MASK            (LED0_MASK | LED1_MASK)

#define LED0_ON             (LED_PORT->OUTCLR = LED0_MASK)
#define LED0_OFF            (LED_PORT->OUTSET = LED0_MASK)
#define LED0_TOGGLE         (LED_PORT->OUT   ^= LED0_MASK)

#define LED1_ON             (LED_PORT->OUTCLR = LED1_MASK)
#define LED1_OFF            (LED_PORT->OUTSET = LED1_MASK)
#define LED1_TOGGLE         (LED_PORT->OUT   ^= LED1_MASK)
/** @} */

/**
 * @name    Button pin configuration
 * @{
 */
#define BTN0_PIN            GPIO_PIN(0, 21)
#define BTN0_MODE           GPIO_IN_PU
#define BTN1_PIN            GPIO_PIN(0, 29)
#define BTN1_MODE           GPIO_IN_PU
/** @} */

#ifdef __cplusplus
}
#endif

#endif /* BOARD_H */
/** @} */

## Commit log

2026-09-05 init
    项目开源
    [BOM单_2026-02-24.xlsx, 外壳.3mf, 底部.3mf]
2026-09-14 feat: 自定义 BLE OTA、电池电压上报与 MCUboot 双槽体系
    相对上游初版（cdeb418）的主要改动：
    版本与发布治理
    - 新增 VERSION 作为镜像版本唯一源（当前 1.0.8+0），驱动 app_version.h
    与 CONFIG_MCUBOOT_IMGTOOL_SIGN_VERSION，杜绝手工改版本号
    - 新增 tools/release_gate.py 发布门禁（版本非 0.0.0+0、与 VERSION 一致、
    高于上一生产版本、无手工签名残留）
    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
2026-09-14 docs: 补齐 Codex 交接文档集；签名私钥改外部注入；真机 OTA 回归通过
    交接文档（全部依据当前代码与构建产物写成，不是设计稿）
    - 新增 CODEX_START_HERE / HANDOFF / DEVELOPMENT / HARDWARE / OTA / PROTOCOL
    - README.rst 顶部改为交接入口，并标注 LED 引脚描述与代码不符
    - 明确区分「编译验证」与「真机验证」，并记录 20 项代码↔文档一致性核对结果
    安全配置清理
    - tools/build_sysbuild.py: 签名私钥改为
    --signing-key > MCU_BOOT_SIGNING_KEY > 报错退出，移除本机路径与默认值
    修复：abspath 在 Windows 产出的反斜杠会被 Kconfig/CMake 逐层吃掉
    （日志里变成 C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
2026-09-15 chore: 清理交接文档与无效配置
2026-09-15 docs: 移除交接文档残留引用
2026-09-15 docs: 记录 Windows Git 与 Gradle 故障处理
2026-10-09 Add negotiated history voltage and persistent 3000-record retention
2026-10-09 Keep app history aligned with validated 3000-record device window
2026-10-14 Verify production Release APK on device and preserve signature migration data
2026-10-14 Add visible three-second startup indication and millivolt voltage display
